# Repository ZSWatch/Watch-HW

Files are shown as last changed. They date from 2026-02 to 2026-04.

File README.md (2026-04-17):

> [!IMPORTANT]  
> This is a prototype right now, not fully tested. Do not order.
> Please use https://github.com/ZSWatch/Watch-DevKit-HW until this PCB is finalized.
> Not recommended to order the older legacy_zswatch. 

# ZSWatch-Watch



## 📑 Table of Contents

- [ZSWatch-Watch](#zswatch-watch)
  - [📑 Table of Contents](#-table-of-contents)
  - [📖 About](#-about)
  - [📂 Directory Breakdown](#-directory-breakdown)
  - [Purchasing](#purchasing)
  - [Ressources](#ressources)
  - [👨‍💻 Maintainer](#-maintainer)

## 📖 About

The **ZSWatch-Watch** project provides the hardware design and production files for a smartwatch development board tailored to the ZSWatch ecosystem.
It is built with **KiCad** and integrates a full **CI/CD pipeline** using **KiBot**, ensuring reproducible outputs for documentation, manufacturing, and releases.

Key features:

- 🛠️ Open-source hardware design
- 📦 Automated generation of Gerber, BoM, and documentation via KiBot
- 🔄 Workflow stages (DRAFT → PRELIMINARY → CHECKED → RELEASED) for structured releases
- 📝 Clear documentation and changelog to track progress
- 🌍 Designed with collaboration and transparency in mind

Please check the [wiki](https://github.com/ZSWatch/ZSWatch/wiki) for more information about the project.

You can also view this project on [CADLAB.io](...). 

## 📂 Directory Breakdown

- **`.github`**: GitHub related files
- **`.gitignore`**: Ignored files list
- **`devkit`**: KiCad project for the devkit
- **`production`**: Manufacturing outputs (Gerbers, documentation, etc.)
- **`CHANGELOG.md`**: Version history
- **`LICENSE`**: Project license (GPL-3.0)
- **`README.md`**: Project overview

## Purchasing

TBD

## Ressources

- [KiBot Template](https://github.com/nguyen-v/KDT_Hierarchical_KiBot)

## 👨‍💻 Maintainer

- [Daniel Kampert](mailto:danielkameprt@kampis-elektroecke.de)

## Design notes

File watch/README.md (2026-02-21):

<p align="center" width="100%">
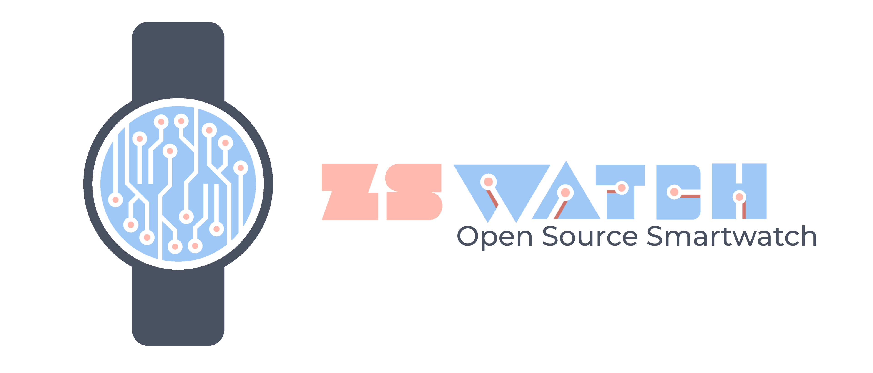
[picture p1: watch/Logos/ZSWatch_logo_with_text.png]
  
</p>

<h1 align="center">Template</h1>

<p align="center" width="100%">
  <a href="${GIT_URL}/actions/workflows/watch.yaml">
    CI Badge
  </a>
</p>

***

<p align="center">
  3D Top Angled
&nbsp; &nbsp; &nbsp; &nbsp;
  3D Bottom Angled
</p>

***

## SPECIFICATIONS

| Parameter | Value |
| --- | --- |
| Dimensions | 32.0 × 24.0 mm |

***

## DIRECTORY STRUCTURE

    .
    ├─ Computations       # Misc calculations
    ├─ HTML               # HTML files for generated webpage
    ├─ Images             # Pictures and renders
    │
    ├─ kibot_resources    # External resources for KiBot
    │  ├─ colors          # Color theme for KiCad
    │  ├─ fonts           # Fonts used in the project
    │  ├─ scripts         # External scripts used with KiBot
    │  └─ templates       # Templates for KiBot generated reports
    │
    ├─ kibot_yaml         # KiBot YAML config files
    ├─ KiRI               # KiRI (PCB diff viewer) files
    │
    ├─ lib                # KiCad footprint and symbol libraries
    │  ├─ 3d_models       # Component 3D models
    │  ├─ lib_fp          # Footprint libraries
    │  └─ lib_sym         # Symbol libraries
    │
    ├─ logos              # Logos
    │
    ├─ Manufacturing      # Assembly and fabrication documents
    │  ├─ Assembly        # Assembly documents (BoM, pos, notes)
    │  │
    │  └─ Fabrication     # Fabrication documents (ZIP, notes)
    │     ├─ Drill Tables # CSV drill tables
    │     └─ Gerbers      # Gerbers
    │
    ├─ Report             # Reports for ERC/DRC
    ├─ Schematic          # PDF of schematic
    ├─ templates          # Title block templates
    ├─ Testing
    │  └─ Testpoints      # Testpoints tables
    │
    └─ Variants           # Outputs for assembly variants

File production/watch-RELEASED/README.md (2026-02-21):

<p align="center" width="100%">
  
</p>

<h1 align="center">Watch-DevKit-HW</h1>

<p align="center" width="100%">
  <a href="https://github.com/ZSWatch/Watch-DevKit-HW/actions/workflows/watch.yaml">
    
  </a>
</p>

***

<p align="center">
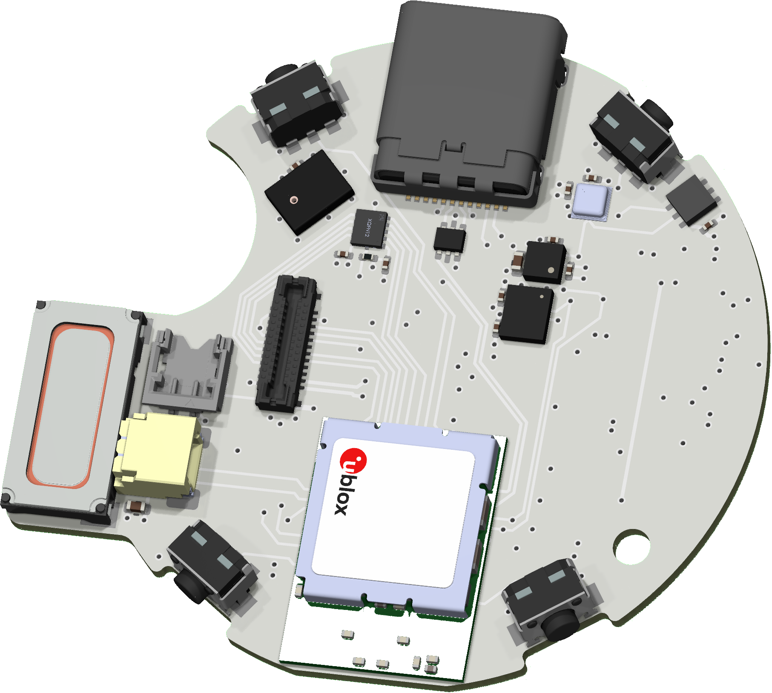
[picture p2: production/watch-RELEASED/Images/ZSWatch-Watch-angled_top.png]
3D Top Angled
  
&nbsp; &nbsp; &nbsp; &nbsp;
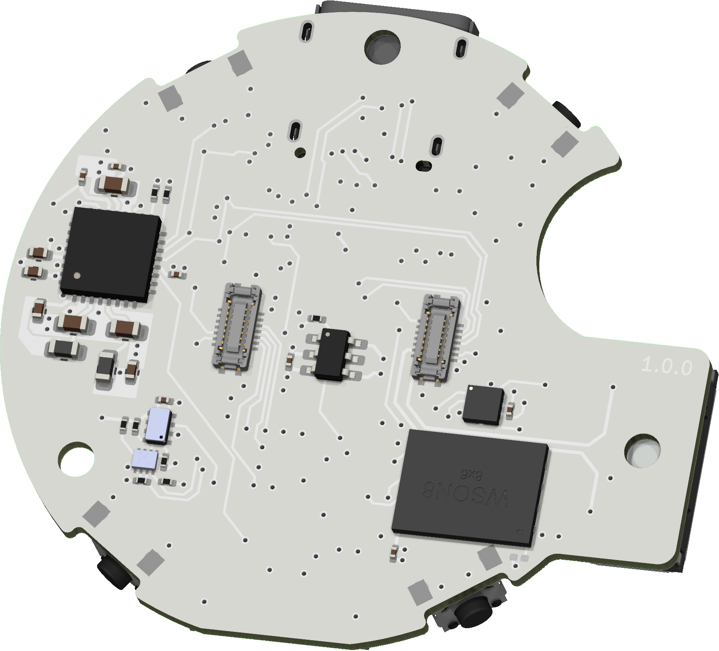
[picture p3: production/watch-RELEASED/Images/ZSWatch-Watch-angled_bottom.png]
3D Bottom Angled
  
</p>

***

## SPECIFICATIONS

| Parameter | Value |
| --- | --- |
| Dimensions | 40.97 × 37.5 mm |

***

## DIRECTORY STRUCTURE

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

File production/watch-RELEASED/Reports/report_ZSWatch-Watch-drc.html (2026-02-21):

Logo

| DRC report for ZSWatch-Watch
| PCB: ZSWatch-Watch Revision: 1.0.0 Date: 2026-02-21T12:36:49+0000 KiCad Version: 9.0.7 | Errors: 0 Warnings: 65 Total: 65

Violations

Type | Description | Details
lib_footprint_issues | The current configuration does not include the footprint library 'Package_QFN'. | @(202.45 mm, 131.19 mm): Footprint IC604
lib_footprint_mismatch | Footprint 'C_0201_0603Metric' does not match copy in library 'Capacitor_SMD'. | @(203.7 mm, 133.1 mm): Footprint C603
lib_footprint_issues | The current configuration does not include the footprint library 'Wuerth'. | @(216.7 mm, 124.7 mm): Footprint S501
lib_footprint_mismatch | Footprint 'C_0201_0603Metric' does not match copy in library 'Capacitor_SMD'. | @(210.507497 mm, 136.062499 mm): Footprint C504
lib_footprint_mismatch | Footprint 'C_0402_1005Metric' does not match copy in library 'Capacitor_SMD'. | @(192.325 mm, 148.675 mm): Footprint C403
lib_footprint_issues | The current configuration does not include the footprint library 'Wuerth'. | @(197.409401 mm, 152.152416 mm): Footprint S504
lib_footprint_mismatch | Footprint 'C_0201_0603Metric' does not match copy in library 'Capacitor_SMD'. | @(201.23 mm, 132.79 mm): Footprint C604
lib_footprint_mismatch | Footprint 'C_0201_0603Metric' does not match copy in library 'Capacitor_SMD'. | @(213.976079 mm, 132.307498 mm): Footprint C507
lib_footprint_mismatch | Footprint 'R_0201_0603Metric' does not match copy in library 'Resistor_SMD'. | @(202.63 mm, 132.79 mm): Footprint R613
lib_footprint_mismatch | Footprint 'C_0201_0603Metric' does not match copy in library 'Capacitor_SMD'. | @(210.462496 mm, 134.237499 mm): Footprint C503
lib_footprint_mismatch | Footprint 'C_0201_0603Metric' does not match copy in library 'Capacitor_SMD'. | @(214.282501 mm, 126.8575 mm): Footprint C509
lib_footprint_mismatch | Footprint 'C_0201_0603Metric' does not match copy in library 'Capacitor_SMD'. | @(213.100001 mm, 127.675001 mm): Footprint C508
lib_footprint_issues | The current configuration does not include the footprint library 'EastRising'. | @(199.0 mm, 138.5 mm): Footprint X608
lib_footprint_issues | The current configuration does not include the footprint library 'Package_LGA_Kampi'. | @(212.1 mm, 135.2 mm): Footprint IC502
lib_footprint_issues | The current configuration does not include the footprint library 'Wuerth'. | @(216.6 mm, 152.1 mm): Footprint S502
lib_footprint_mismatch | Footprint 'C_0201_0603Metric' does not match copy in library 'Capacitor_SMD'. | @(212.78 mm, 130.667001 mm): Footprint C505
lib_footprint_mismatch | Footprint 'C_0201_0603Metric' does not match copy in library 'Capacitor_SMD'. | @(197.675287 mm, 128.024713 mm): Footprint C502
lib_footprint_issues | The current configuration does not include the footprint library 'Package_LGA_Kampi'. | @(214.500001 mm, 128.2375 mm): Footprint IC504
lib_footprint_mismatch | Footprint 'JST_SH_SM02B-SRSS-TB_1x02-1MP_P1.00mm_Horizontal' does not match copy in library 'Connector_JST'. | @(192.9 mm, 146.0 mm): Footprint X402
lib_footprint_mismatch | Footprint 'SOT-666' does not match copy in library 'Package_TO_SOT_SMD'. | @(207.0375 mm, 131.35 mm): Footprint IC602
lib_footprint_issues | The current configuration does not include the footprint library 'Molex'. | @(193.95 mm, 140.8 mm): Footprint X509
lib_footprint_issues | The current configuration does not include the footprint library 'Wuerth'. | @(197.433306 mm, 124.890678 mm): Footprint S503
lib_footprint_issues | The current configuration does not include the footprint library 'Knowles'. | @(198.820801 mm, 129.566207 mm): Footprint MK501
lib_footprint_issues | The current configuration does not include the footprint library 'Package_LGA_Kampi'. | @(212.604999 mm, 132.15 mm): Footprint IC503
lib_footprint_issues | The current configuration does not include the footprint library 'Broadcom'. | @(220.146966 mm, 127.633273 mm): Footprint IC501
lib_footprint_issues | The current configuration does not include the footprint library 'uBlox'. | @(207.0 mm, 150.1 mm): Footprint M601
lib_footprint_mismatch | Footprint 'C_0402_1005Metric' does not match copy in library 'Capacitor_SMD'. | @(211.054999 mm, 132.1875 mm): Footprint C506
lib_footprint_mismatch | Footprint 'USB_C_Receptacle_Amphenol_12401610E4-2A' does not match copy in library 'Connector_USB'. | @(207.0 mm, 123.9 mm): Footprint X603
lib_footprint_mismatch | Footprint 'C_0201_0603Metric' does not match copy in library 'Capacitor_SMD'. | @(221.234143 mm, 128.879548 mm): Footprint C501
lib_footprint_issues | The current configuration does not include the footprint library 'Same Sky'. | @(188.0 mm, 143.8 mm): Footprint LS801
lib_footprint_issues | The current configuration does not include the footprint library 'Package_QFN'. | @(197.4 mm, 142.15 mm): Footprint IC505
lib_footprint_mismatch | Footprint 'C_0201_0603Metric' does not match copy in library 'Capacitor_SMD'. | @(216.3304 mm, 136.3 mm): Footprint C402
lib_footprint_mismatch | Footprint 'R_0201_0603Metric' does not match copy in library 'Resistor_SMD'. | @(207.9 mm, 138.0 mm): Footprint R601
lib_footprint_mismatch | Footprint 'R_0201_0603Metric' does not match copy in library 'Resistor_SMD'. | @(216.209999 mm, 148.7 mm): Footprint R501
lib_footprint_mismatch | Footprint 'R_0201_0603Metric' does not match copy in library 'Resistor_SMD'. | @(217.8 mm, 145.5 mm): Footprint R506
lib_footprint_mismatch | Footprint 'R_0201_0603Metric' does not match copy in library 'Resistor_SMD'. | @(214.755 mm, 148.6 mm): Footprint R502
lib_footprint_mismatch | Footprint 'C_0201_0603Metric' does not match copy in library 'Capacitor_SMD'. | @(209.0 mm, 140.7 mm): Footprint C601
lib_footprint_mismatch | Footprint 'C_0201_0603Metric' does not match copy in library 'Capacitor_SMD'. | @(215.755 mm, 143.8 mm): Footprint C511
lib_footprint_mismatch | Footprint 'C_0201_0603Metric' does not match copy in library 'Capacitor_SMD'. | @(220.9 mm, 130.3 mm): Footprint C401
lib_footprint_mismatch | Footprint 'C_0201_0603Metric' does not match copy in library 'Capacitor_SMD'. | @(201.05 mm, 151.355 mm): Footprint C602
lib_footprint_mismatch | Footprint 'C_0603_1608Metric' does not match copy in library 'Capacitor_SMD'. | @(220.761401 mm, 131.497172 mm): Footprint C410
lib_footprint_mismatch | Footprint 'C_0201_0603Metric' does not match copy in library 'Capacitor_SMD'. | @(195.9 mm, 142.2 mm): Footprint C510
lib_footprint_mismatch | Footprint 'C_0603_1608Metric' does not match copy in library 'Capacitor_SMD'. | @(218.622001 mm, 139.936383 mm): Footprint C409
lib_footprint_issues | The current configuration does not include the footprint library 'Amphenol'. | @(200.8 mm, 138.5 mm): Footprint X702
lib_footprint_mismatch | Footprint 'C_0402_1005Metric' does not match copy in library 'Capacitor_SMD'. | @(224.5 mm, 137.1 mm): Footprint C512
lib_footprint_mismatch | Footprint 'C_0402_1005Metric' does not match copy in library 'Capacitor_SMD'. | @(217.892001 mm, 142.308382 mm): Footprint C406
lib_footprint_mismatch | Footprint 'R_0201_0603Metric' does not match copy in library 'Resistor_SMD'. | @(193.87 mm, 150.8 mm): Footprint R612
lib_footprint_mismatch | Footprint 'C_0402_1005Metric' does not match copy in library 'Capacitor_SMD'. | @(224.400001 mm, 135.950002 mm): Footprint C404
lib_footprint_mismatch | Footprint 'L_0603_1608Metric' does not match copy in library 'Inductor_SMD'. | @(221.911 mm, 141.5 mm): Footprint L402
lib_footprint_issues | The current configuration does not include the footprint library 'Package_SON_Kampi'. | @(216.18 mm, 147.5 mm): Footprint IC506
lib_footprint_mismatch | Footprint 'R_0201_0603Metric' does not match copy in library 'Resistor_SMD'. | @(215.109999 mm, 147.420001 mm): Footprint R505
lib_footprint_mismatch | Footprint 'R_0201_0603Metric' does not match copy in library 'Resistor_SMD'. | @(217.75 mm, 131.608381 mm): Footprint R408
lib_footprint_mismatch | Footprint 'C_0402_1005Metric' does not match copy in library 'Capacitor_SMD'. | @(223.8304 mm, 139.278193 mm): Footprint C408
lib_footprint_mismatch | Footprint 'QFN-32-1EP_5x5mm_P0.5mm_EP3.6x3.6mm' does not match copy in library 'Package_DFN_QFN'. | @(220.2 mm, 135.7 mm): Footprint IC401
lib_footprint_mismatch | Footprint 'TSOT-23-6' does not match copy in library 'Package_TO_SOT_SMD'. | @(206.5375 mm, 140.15 mm): Footprint IC601
lib_footprint_mismatch | Footprint 'WSON-8-1EP_8x6mm_P1.27mm_EP3.4x4.3mm' does not match copy in library 'Package_SON'. | @(197.3 mm, 147.135 mm): Footprint IC603
lib_footprint_mismatch | Footprint 'C_0603_1608Metric' does not match copy in library 'Capacitor_SMD'. | @(221.657 mm, 139.936383 mm): Footprint C407
lib_footprint_mismatch | Footprint 'L_0603_1608Metric' does not match copy in library 'Inductor_SMD'. | @(219.370999 mm, 142.349382 mm): Footprint L401
lib_footprint_issues | The current configuration does not include the footprint library 'Micro Crystal'. | @(215.755 mm, 145.430001 mm): Footprint IC507
lib_footprint_mismatch | Footprint 'R_0201_0603Metric' does not match copy in library 'Resistor_SMD'. | @(217.1 mm, 145.5 mm): Footprint R504
lib_footprint_mismatch | Footprint 'R_0201_0603Metric' does not match copy in library 'Resistor_SMD'. | @(218.449999 mm, 131.608381 mm): Footprint R407
lib_footprint_mismatch | Footprint 'C_0201_0603Metric' does not match copy in library 'Capacitor_SMD'. | @(222.730398 mm, 131.087793 mm): Footprint C405
lib_footprint_issues | The current configuration does not include the footprint library 'Amphenol'. | @(212.3 mm, 139.1 mm): Footprint X701

Schematic parity

Type | Description | Details
footprint_symbol_mismatch | Connector_JST:JST_SH_SM02B-SRSS-TB_1x02-1MP_P1.00mm_Horizontal doesn't match footprint given by symbol (JST_SH_SM02B-SRSS-TB_1x02-1MP_P1.00mm_Horizontal). | @(192.9 mm, 146.0 mm): Footprint X402
extra_footprint | Extra footprint | @(220.2 mm, 147.8 mm): Footprint REF**

Generated by KiBot (https://github.com/INTI-CMNB/KiBot/) v1.8.5

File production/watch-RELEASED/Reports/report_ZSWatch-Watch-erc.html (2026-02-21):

Logo

| ERC report for ZSWatch-Watch
| Schematic: ZSWatch-Watch Revision: 1.0.0 Date: 2026-02-21T12:36:46+0000 KiCad Version: 9.0.7 | Errors: 0 Warnings: 49 Total: 49

Sheet / (ZSWatch-Watch.kicad_sch)

Type | Description | Details
unresolved_variable | Unresolved text variable | @(0.2032 mm, 0.3175 mm): Text Box
unresolved_variable | Unresolved text variable | @(0.2286 mm, 0.3556 mm): Text Box
unresolved_variable | Unresolved text variable | @(0.8636 mm, 0.3175 mm): Text Box
unresolved_variable | Unresolved text variable | @(0.889 mm, 0.3556 mm): Text Box
unresolved_variable | Unresolved text variable | @(1.524 mm, 0.3175 mm): Text Box
unresolved_variable | Unresolved text variable | @(1.5494 mm, 0.3556 mm): Text Box
unresolved_variable | Unresolved text variable | @(2.1844 mm, 0.3175 mm): Text Box
unresolved_variable | Unresolved text variable | @(2.2098 mm, 0.3556 mm): Text Box
footprint_link_issues | The current configuration does not include the footprint library 'Broadcom'. | @(0.3048 mm, 0.5461 mm): Symbol IC501 [APDS-9306-065]
footprint_link_issues | The current configuration does not include the footprint library 'Wuerth'. | @(0.254 mm, 1.0033 mm): Symbol S501 [SW_Push]
footprint_link_issues | The current configuration does not include the footprint library 'Wuerth'. | @(0.254 mm, 1.1176 mm): Symbol S502 [SW_Push]
footprint_link_issues | The current configuration does not include the footprint library 'Wuerth'. | @(0.254 mm, 1.2319 mm): Symbol S503 [SW_Push]
footprint_link_issues | The current configuration does not include the footprint library 'Wuerth'. | @(0.254 mm, 1.3462 mm): Symbol S504 [SW_Push]
footprint_link_issues | The current configuration does not include the footprint library 'Knowles'. | @(0.8636 mm, 1.27 mm): Symbol MK501 [SPK0641HT4H-1]
lib_symbol_issues | The current configuration does not include the symbol library 'Knowles' | @(0.8636 mm, 1.27 mm): Symbol MK501 [SPK0641HT4H-1]
footprint_link_issues | The current configuration does not include the footprint library 'Package_LGA_Kampi'. | @(1.9558 mm, 0.7747 mm): Symbol IC502 [BMI270]
lib_symbol_issues | The current configuration does not include the symbol library 'Bosch_Kampi' | @(1.9558 mm, 0.7747 mm): Symbol IC502 [BMI270]
footprint_link_issues | The current configuration does not include the footprint library 'Package_LGA_Kampi'. | @(2.7051 mm, 0.762 mm): Symbol IC504 [BMP581]
lib_symbol_issues | The current configuration does not include the symbol library 'Bosch_Kampi' | @(2.7051 mm, 0.762 mm): Symbol IC504 [BMP581]
footprint_link_issues | The current configuration does not include the footprint library 'Package_LGA_Kampi'. | @(2.6162 mm, 1.5875 mm): Symbol IC503 [LIS2MDLTR]
lib_symbol_issues | The current configuration does not include the symbol library 'ST' | @(2.6162 mm, 1.5875 mm): Symbol IC503 [LIS2MDLTR]
footprint_link_issues | The current configuration does not include the footprint library 'Package_QFN'. | @(3.3782 mm, 0.6096 mm): Symbol IC505 [DRV2603RUNT]
lib_symbol_issues | The current configuration does not include the symbol library 'Texas Instruments' | @(3.3782 mm, 0.6096 mm): Symbol IC505 [DRV2603RUNT]
footprint_link_issues | The current configuration does not include the footprint library 'Molex'. | @(3.6068 mm, 0.6223 mm): Symbol X509 [Conn_01x02]
footprint_link_issues | The current configuration does not include the footprint library 'Package_SON_Kampi'. | @(3.4544 mm, 1.3081 mm): Symbol IC506 [PCA9306JK]
lib_symbol_issues | The current configuration does not include the symbol library 'NXP' | @(3.4544 mm, 1.3081 mm): Symbol IC506 [PCA9306JK]
footprint_link_issues | The current configuration does not include the footprint library 'Micro Crystal'. | @(3.81 mm, 1.3843 mm): Symbol IC507 [RV-8263-C8]
lib_symbol_issues | The current configuration does not include the symbol library 'Micro Crystal' | @(3.81 mm, 1.3843 mm): Symbol IC507 [RV-8263-C8]
footprint_link_issues | The current configuration does not include the footprint library 'uBlox'. | @(0.8636 mm, 1.1049 mm): Symbol M601 [NORA-B106]
lib_symbol_issues | The current configuration does not include the symbol library 'uBlox' | @(0.8636 mm, 1.1049 mm): Symbol M601 [NORA-B106]
footprint_link_issues | The current configuration does not include the footprint library 'uBlox'. | @(1.397 mm, 1.0287 mm): Symbol M601 [NORA-B106]
lib_symbol_issues | The current configuration does not include the symbol library 'uBlox' | @(1.397 mm, 1.0287 mm): Symbol M601 [NORA-B106]
lib_symbol_issues | The current configuration does not include the symbol library 'ON Semiconductor' | @(0.5334 mm, 1.9685 mm): Symbol IC601 [FAN5622]
footprint_link_issues | The current configuration does not include the footprint library 'uBlox'. | @(2.159 mm, 1.2319 mm): Symbol M601 [NORA-B106]
lib_symbol_issues | The current configuration does not include the symbol library 'uBlox' | @(2.159 mm, 1.2319 mm): Symbol M601 [NORA-B106]
lib_symbol_issues | The current configuration does not include the symbol library 'Infineon' | @(2.3749 mm, 1.9939 mm): Symbol IC603 [S25FS512SAGNFI010]
footprint_link_issues | The current configuration does not include the footprint library 'Package_QFN'. | @(3.5179 mm, 0.762 mm): Symbol IC604 [NTS0104GU12 (XQFN12)]
lib_symbol_issues | The current configuration does not include the symbol library 'NXP' | @(3.5179 mm, 0.762 mm): Symbol IC604 [NTS0104GU12 (XQFN12)]
footprint_link_issues | The current configuration does not include the footprint library 'EastRising'. | @(3.5433 mm, 1.4605 mm): Symbol X608 [GC9A01A_CST816S]
lib_symbol_issues | The current configuration does not include the symbol library 'Display' | @(3.5433 mm, 1.4605 mm): Symbol X608 [GC9A01A_CST816S]
lib_symbol_issues | The current configuration does not include the symbol library 'Nordic' | @(1.7018 mm, 1.0414 mm): Symbol IC401 [nPM1300-QEXX]
footprint_link_issues | The current configuration does not include the footprint library ''. | @(1.9812 mm, 0.3683 mm): Symbol X402 [Conn_01x02]
footprint_link_issues | The current configuration does not include the footprint library 'Amphenol'. | @(0.9017 mm, 0.8636 mm): Symbol X701 [Conn_02x07_Top_Bottom]
footprint_link_issues | The current configuration does not include the footprint library 'Amphenol'. | @(1.5875 mm, 0.8636 mm): Symbol X702 [Conn_02x07_Top_Bottom]
footprint_link_issues | The current configuration does not include the footprint library 'Same Sky'. | @(1.8034 mm, 0.8255 mm): Symbol LS801 [Speaker]

Sheet /Project Architecture/Power Management/ (Power.kicad_sch)

Type | Description | Details
pin_to_pin | Pins of type Bidirectional and Power output are connected | @(2.032 mm, 1.2319 mm): Symbol IC401 Pin 29 [LSOUT1/VOUTLDO1, Bidirectional, Line] @(2.3114 mm, 1.2192 mm): Symbol #FLG0502 Pin 1 [Power output, Line]
pin_to_pin | Pins of type Bidirectional and Power output are connected | @(2.032 mm, 1.3081 mm): Symbol IC401 Pin 31 [LSOUT2/VOUTLDO2, Bidirectional, Line] @(2.159 mm, 1.2954 mm): Symbol #FLG0501 Pin 1 [Power output, Line]

Sheet /Project Architecture/Peripherals/ (Peripherals.kicad_sch)

Type | Description | Details
pin_to_pin | Pins of type Bidirectional and Power output are connected | @(1.8288 mm, 0.7239 mm): Symbol IC502 Pin 1 [SDO, Bidirectional, Line] @(0.889 mm, 1.8796 mm): Symbol #FLG0402 Pin 1 [Power output, Line]
pin_to_pin | Pins of type Bidirectional and Power output are connected | @(2.5781 mm, 0.7366 mm): Symbol IC504 Pin 5 [SDO, Bidirectional, Line] @(2.032 mm, 0.8255 mm): Symbol IC401 Pin 1 [VOUT1, Power output, Line]

Generated by KiBot (https://github.com/INTI-CMNB/KiBot/) v1.8.5

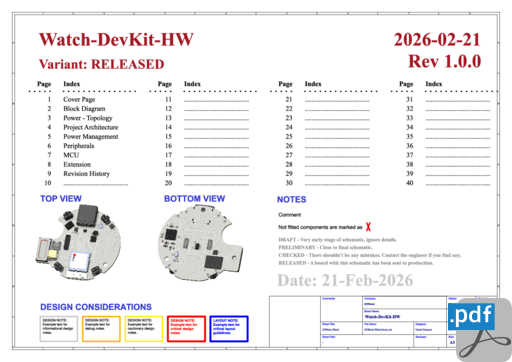
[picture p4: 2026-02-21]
production/watch-RELEASED/HTML/images/cat_pdf_schematic_ZSWatch-Watch-schematic.png

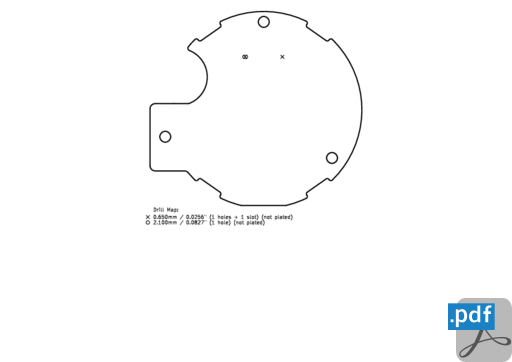
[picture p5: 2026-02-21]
production/watch-RELEASED/HTML/images/cat_pdf_drill_map_ZSWatch-Watch-NPTH_drill_map.png

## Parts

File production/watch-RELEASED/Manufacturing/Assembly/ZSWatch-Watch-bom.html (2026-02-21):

 | Bill of Materials
 | Schematic: ZSWatch-Watch Variant: RELEASED Revision: 1.0.0 Date: 2025-07-13 KiCad Version: 9.0.7+1 | Component Groups: 37 Component Count: 62 (per PCB) Fitted Components: 62 (per PCB) Number of PCBs: 1 Total Components: 62 (for 1 PCBs)
Row | Quantity Per PCB | References | Value | Datasheet | Footprint | Description | manf | manf# | mouser#
1 | 13 | C402 C501 C502 C503 C504 C507 C508 C509 C510 C511 C602 C603 C604 | 100n | https://datasheets.kyocera-avx.com/cx5r-KGM.pdf | C_0201_0603Metric | Unpolarized capacitor, small symbol | KYOCERA AVX | 02016D104MAT4A | 581-02016D104MAT4A
2 | 1 | C505 | 220n | https://datasheets.kyocera-avx.com/cx5r-KGM.pdf | C_0201_0603Metric | Unpolarized capacitor, small symbol | KYOCERA AVX | 0201ZD224KAT2A | 581-0201ZD224KAT2A
3 | 3 | C401 C405 C601 | 1u | https://datasheets.kyocera-avx.com/cx5r-KGM.pdf | C_0201_0603Metric | Unpolarized capacitor, small symbol | KYOCERA AVX | KGM03BR50J105KH | 581-KGM03BR50J105KH
4 | 1 | C403 | 2u2 | https://datasheets.kyocera-avx.com/cx5r.pdf | C_0402_1005Metric | Unpolarized capacitor, small symbol | KYOCERA AVX | 0402ZD225MAT2A | 581-0402ZD225MAT2A
5 | 5 | C404 C406 C408 C506 C512 | 10u | https://search.murata.co.jp/Ceramy/image/img/A01X/G101/ENG/GRJ155R60J106ME11-02A.pdf | C_0402_1005Metric | Unpolarized capacitor, small symbol | Murata Electronics | GRJ155R60J106ME11D | 81-GRJ155R60J106ME11D
6 | 3 | C407 C409 C410 | 10u | https://datasheets.kyocera-avx.com/cx5r-KGM.pdf | C_0603_1608Metric | Unpolarized capacitor, small symbol | KYOCERA AVX | KGM15CR50J106MT | 581-KGM15CR50J106MT
7 | 1 | IC501 | APDS-9306-065 | https://docs.broadcom.com/docs/AV02-4755EN | Broadcom_DFN-6_2x2mm_P0.65mm | Ambient Light Sensor, I2C interface, 1.7-3.6V, DFN-6 | Broadcom / Avago | APDS-9306-065 | 630-APDS-9306-065
8 | 1 | IC502 | BMI270 | https://www.bosch-sensortec.com/media/boschsensortec/downloads/datasheets/bst-bmi270-ds000.pdf | Bosch_LGA-14_3x2.5mm_P0.5mm_LayoutBorder3x4y |  | Bosch | BMI270 | 262-BMI270
9 | 1 | IC504 | BMP581 | https://www.bosch-sensortec.com/media/boschsensortec/downloads/datasheets/bst-bmp581-ds004.pdf | Bosch_LGA-10_2x2mm_P0.5mm_ClockwisePinNumbering |  | Bosch | BMP581 | 262-BMP581
10 | 1 | IC505 | DRV2603RUNT | https://www.ti.com/lit/ds/symlink/drv2603.pdf?HQS=dis-mous-null-mousermode-dsf-pf-null-wwe&ts=1692200896697 | WQFN-10_2x2mm_P0.5mm |  | Texas Instruments | DRV2603RUNT | 595-DRV2603RUNT
11 | 1 | IC601 | FAN5622SX | https://www.onsemi.com/download/data-sheet/pdf/fan5626-d.pdf | TSOT-23-6 |  | onsemi / Fairchild | FAN5622SX | 512-FAN5622SX
12 | 1 | IC503 | LIS2MDLTR | http://www.st.com/content/ccc/resource/technical/document/datasheet/group3/29/13/d1/e0/9a/4d/4f/30/DM00395193/files/DM00395193.pdf/jcr:content/translations/en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 | LGA-12_2x2mm_P0.5mm |  | STMicroelectronics | LIS2MDLTR | 511-LIS2MDLTR
13 | 1 | IC603 | MX25U51245GZ4I00 | https://www.mouser.de/datasheet/2/819/MX25U51245G_2c_1_8V_2c_512Mb_2c_v1_4-3371129.pdf | WSON-8-1EP_8x6mm_P1.27mm_EP3.4x4.3mm |  | Macronix | MX25U51245GZ4I00 | 95-25U51245GZ4I00T
14 | 1 | IC604 | NTS0104GU12 | https://www.nxp.com/docs/en/data-sheet/NTS0104.pdf | XQFN-12-1.7x2mm_P0.4mm |  | NXP Semiconductors | NTS0104GU12,115 | 771-NTS0104GU12115
15 | 1 | IC506 | PCA9306JK | https://www.nxp.com/docs/en/data-sheet/PCA9306.pdf | XSON-8_0.65x0.17mm_P0.35mm | Dual bidirectional I2C Bus and SMBus voltage level translator | NXP Semiconductors | PCA9306JKZ | 771-PCA9306JKZ
16 | 1 | IC507 | RV-8263-C8 | https://www.microcrystal.com/fileadmin/Media/Products/RTC/Datasheet/RV-8263-C8.pdf | RV-8263-C8 |  | Micro Crystal | RV-8263-C8 32.768kHz-20PPM-TA-QA | 428-204291-MC01
17 | 1 | IC602 | USBLC6-2P6 | https://www.st.com/resource/en/datasheet/usblc6-2.pdf | SOT-666 | Very low capacitance ESD protection diode, 2 data-line, SOT-666 | STMicroelectronics | USBLC6-2P6 | 511-USBLC6-2P6
18 | 1 | IC401 | nPM1300-QEXX | https://infocenter.nordicsemi.com/index.jsp?topic=%2Fstruct_pmic%2Fstruct%2Fnpm1300.html | QFN-32-1EP_5x5mm_P0.5mm_EP3.6x3.6mm |  | Nordic Semiconductor | nPM1300-QEAA-R7 | 949-NPM1300-QEAA-R7
19 | 2 | L401 L402 | 2u2 | https://www.mouser.de/datasheet/3/76/1/JELF243B-9121.pdf | L_0603_1608Metric | Inductor | Murata Electronics | LQM18PZ2R2MDHD | 81-LQM18PZ2R2MDHD
20 | 1 | LS801 | Speaker | https://www.mouser.de/datasheet/3/6118/1/cmr_12062s_67.pdf | CMR-12062S-67 | Speaker | Same Sky | CMR-12062S-67 | 490-CMR-12062S-67
21 | 1 | M601 | NORA-B106 | https://www.u-blox.com/docs/UBX-20027119 | NORA-B106 |  | u-blox | NORA-B106-00B | 377-NORA-B106-00B
22 | 1 | MK501 | SPK0641HT4H-1 | https://www.knowles.com/docs/default-source/default-document-library/sph0645lm4h-1-datasheet.pdf | SPK0641HT4H-1 | Digital MEMS Microphone | Knowles | SPK0641HT4H-1 | 721-SPK0641HT4H-1
23 | 2 | R501 R502 | 1k8 | https://www.mouser.com/catalog/specsheets/YAGEO_PYu_RC_Group_51_RoHS_L_12.pdf | R_0201_0603Metric | Resistor, small symbol | YAGEO | RC0201JR-071K8L | 603-RC0201JR-071K8L
24 | 2 | R504 R505 | 3k3 | https://www.mouser.com/catalog/specsheets/YAGEO_PYu_RC_Group_51_RoHS_L_12.pdf | R_0201_0603Metric | Resistor, small symbol | YAGEO | RC0201JR-073K3L | 603-RC0201JR-073K3L
25 | 1 | R601 | 12k | https://www.mouser.com/catalog/specsheets/YAGEO_PYu_RC_Group_51_RoHS_L_12.pdf | R_0201_0603Metric | Resistor, small symbol | YAGEO | RC0201JR-0712KL | 603-RC0201JR-0712KL
26 | 1 | R407 | 47k | https://www.mouser.com/catalog/specsheets/YAGEO_PYu_RC_Group_51_RoHS_L_12.pdf | R_0201_0603Metric | Resistor, small symbol | YAGEO | RC0201JR-0747KL | 603-RC0201JR-0747KL
27 | 2 | R408 R613 | 100k | https://www.mouser.com/catalog/specsheets/YAGEO_PYu_RC_Group_51_RoHS_L_12.pdf | R_0201_0603Metric | Resistor, small symbol | YAGEO | RC0201JR-07100KL | 603-RC0201JR-07100KL
28 | 1 | R506 | 200k | https://www.mouser.com/catalog/specsheets/YAGEO_PYu_RC_Group_51_RoHS_L_12.pdf | R_0201_0603Metric | Resistor, small symbol | YAGEO | RC0201JR-07200KL | 603-RC0201JR-07200KL
29 | 1 | S501 | SW1 | https://www.we-online.com/components/products/datasheet/436333033816.pdf | 43633303381_NoMountingPads | Push button switch, generic, two pins | Wurth Elektronik | 436333033816 | 710-436333033816
30 | 1 | S502 | SW2 | https://www.we-online.com/components/products/datasheet/436333033816.pdf | 43633303381_NoMountingPads | Push button switch, generic, two pins | Wurth Elektronik | 436333033816 | 710-436333033816
31 | 1 | S503 | SW3 | https://www.we-online.com/components/products/datasheet/436333033816.pdf | 43633303381_NoMountingPads | Push button switch, generic, two pins | Wurth Elektronik | 436333033816 | 710-436333033816
32 | 1 | S504 | SW4 | https://www.we-online.com/components/products/datasheet/436333033816.pdf | 43633303381_NoMountingPads | Push button switch, generic, two pins | Wurth Elektronik | 436333033816 | 710-436333033816
33 | 1 | X402 | Battery | https://www.mouser.com/catalog/specsheets/JST_SM02B-SRSS-TB_LF_SN_eSR_SZ.pdf | JST_SH_SM02B-SRSS-TB_1x02-1MP_P1.00mm_Horizontal | Generic connector, single row, 01x02, script generated (kicad-library-utils/schlib/autogen/connector/) | JST Commercial | SM02B-SRSS-TB | 306-SM02BSRSSTBLFSN
34 | 1 | X603 | Device | https://www.usb.org/sites/default/files/documents/usb_type-c.zip | USB_C_Receptacle_Amphenol_12401610E4-2A | USB Full-Featured Type-C Receptacle connector | Amphenol Commercial Products | 12401610E4#2A | 523-12401610E4#2A
35 | 1 | X608 | Display | https://www.buydisplay.com/download/manual/ER-TFT1.28-2_Datasheet.pdf | ER-CON0.4-24P |  | EastRising | OK-24F024-04
36 | 2 | X701 X702 | MB1 | https://cdn.amphenol-cs.com/media/wysiwyg/files/drawing/101r014fb110.pdf | 101R014FB110 | Generic connector, double row, 02x07, top/bottom pin numbering scheme (row 1: 1...pins_per_row, row2: pins_per_row+1 ... num_pins), script generated (kicad-library-utils/schlib/autogen/connector/) | Amphenol Aorora | 101R014FB110 | 649-101R014FB110
37 | 1 | X509 | Motor | https://www.molex.com/en-us/products/part-detail-pdf/781710002?display=pdf | 78171-0002 | Generic connector, single row, 01x02, script generated (kicad-library-utils/schlib/autogen/connector/) | Molex | 78171-0002 | 538-78171-0002
Color reference for columns:
KiCad Fields (default)
Generated Fields
User Fields
Empty Fields

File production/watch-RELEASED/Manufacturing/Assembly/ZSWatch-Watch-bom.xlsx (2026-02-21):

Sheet: BoM
Bill of Materials
Schematic: | ZSWatch-Watch | Component Groups: | 37
Variant: | RELEASED | Component Count: | 62 (58 SMD/ 4 THT)
Revision: |  | Fitted Components: | 62 (58 SMD/ 4 THT)
Date: | 2025-07-13 | Number of PCBs: | 1
KiCad Version: | 9.0.7+1 | Total Components: | 62
Row | Quantity Per PCB | References | Value | Datasheet | Footprint | Description | manf | manf#
1 | 13 | C402 C501 C502 C503 C504 C507 C508 C509 C510 C511 C602 C603 C604 | 100n | https://datasheets.kyocera-avx.com/cx5r-KGM.pdf | C_0201_0603Metric | Unpolarized capacitor, small symbol | KYOCERA AVX | 02016D104MAT4A
2 | 1 | C505 | 220n | https://datasheets.kyocera-avx.com/cx5r-KGM.pdf | C_0201_0603Metric | Unpolarized capacitor, small symbol | KYOCERA AVX | 0201ZD224KAT2A
3 | 3 | C401 C405 C601 | 1u | https://datasheets.kyocera-avx.com/cx5r-KGM.pdf | C_0201_0603Metric | Unpolarized capacitor, small symbol | KYOCERA AVX | KGM03BR50J105KH
4 | 1 | C403 | 2u2 | https://datasheets.kyocera-avx.com/cx5r.pdf | C_0402_1005Metric | Unpolarized capacitor, small symbol | KYOCERA AVX | 0402ZD225MAT2A
5 | 5 | C404 C406 C408 C506 C512 | 10u | https://search.murata.co.jp/Ceramy/image/img/A01X/G101/ENG/GRJ155R60J106ME11-02A.pdf | C_0402_1005Metric | Unpolarized capacitor, small symbol | Murata Electronics | GRJ155R60J106ME11D
6 | 3 | C407 C409 C410 | 10u | https://datasheets.kyocera-avx.com/cx5r-KGM.pdf | C_0603_1608Metric | Unpolarized capacitor, small symbol | KYOCERA AVX | KGM15CR50J106MT
7 | 1 | IC501 | APDS-9306-065 | https://docs.broadcom.com/docs/AV02-4755EN | Broadcom_DFN-6_2x2mm_P0.65mm | Ambient Light Sensor, I2C interface, 1.7-3.6V, DFN-6 | Broadcom / Avago | APDS-9306-065
8 | 1 | IC502 | BMI270 | https://www.bosch-sensortec.com/media/boschsensortec/downloads/datasheets/bst-bmi270-ds000.pdf | Bosch_LGA-14_3x2.5mm_P0.5mm_LayoutBorder3x4y |  | Bosch | BMI270
9 | 1 | IC504 | BMP581 | https://www.bosch-sensortec.com/media/boschsensortec/downloads/datasheets/bst-bmp581-ds004.pdf | Bosch_LGA-10_2x2mm_P0.5mm_ClockwisePinNumbering |  | Bosch | BMP581
10 | 1 | IC505 | DRV2603RUNT | https://www.ti.com/lit/ds/symlink/drv2603.pdf?HQS=dis-mous-null-mousermode-dsf-pf-null-wwe&ts=1692200896697 | WQFN-10_2x2mm_P0.5mm |  | Texas Instruments | DRV2603RUNT
11 | 1 | IC601 | FAN5622SX | https://www.onsemi.com/download/data-sheet/pdf/fan5626-d.pdf | TSOT-23-6 |  | onsemi / Fairchild | FAN5622SX
12 | 1 | IC503 | LIS2MDLTR | http://www.st.com/content/ccc/resource/technical/document/datasheet/group3/29/13/d1/e0/9a/4d/4f/30/DM00395193/files/DM00395193.pdf/jcr:content/translations/en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 | LGA-12_2x2mm_P0.5mm |  | STMicroelectronics | LIS2MDLTR
13 | 1 | IC603 | MX25U51245GZ4I00 | https://www.mouser.de/datasheet/2/819/MX25U51245G_2c_1_8V_2c_512Mb_2c_v1_4-3371129.pdf | WSON-8-1EP_8x6mm_P1.27mm_EP3.4x4.3mm |  | Macronix | MX25U51245GZ4I00
14 | 1 | IC604 | NTS0104GU12 | https://www.nxp.com/docs/en/data-sheet/NTS0104.pdf | XQFN-12-1.7x2mm_P0.4mm |  | NXP Semiconductors | NTS0104GU12,115
15 | 1 | IC506 | PCA9306JK | https://www.nxp.com/docs/en/data-sheet/PCA9306.pdf | XSON-8_0.65x0.17mm_P0.35mm | Dual bidirectional I2C Bus and SMBus voltage level translator | NXP Semiconductors | PCA9306JKZ
16 | 1 | IC507 | RV-8263-C8 | https://www.microcrystal.com/fileadmin/Media/Products/RTC/Datasheet/RV-8263-C8.pdf | RV-8263-C8 |  | Micro Crystal | RV-8263-C8 32.768kHz-20PPM-TA-QA
17 | 1 | IC602 | USBLC6-2P6 | https://www.st.com/resource/en/datasheet/usblc6-2.pdf | SOT-666 | Very low capacitance ESD protection diode, 2 data-line, SOT-666 | STMicroelectronics | USBLC6-2P6
18 | 1 | IC401 | nPM1300-QEXX | https://infocenter.nordicsemi.com/index.jsp?topic=%2Fstruct_pmic%2Fstruct%2Fnpm1300.html | QFN-32-1EP_5x5mm_P0.5mm_EP3.6x3.6mm |  | Nordic Semiconductor | nPM1300-QEAA-R7
19 | 2 | L401 L402 | 2u2 | https://www.mouser.de/datasheet/3/76/1/JELF243B-9121.pdf | L_0603_1608Metric | Inductor | Murata Electronics | LQM18PZ2R2MDHD
20 | 1 | LS801 | Speaker | https://www.mouser.de/datasheet/3/6118/1/cmr_12062s_67.pdf | CMR-12062S-67 | Speaker | Same Sky | CMR-12062S-67
21 | 1 | M601 | NORA-B106 | https://www.u-blox.com/docs/UBX-20027119 | NORA-B106 |  | u-blox | NORA-B106-00B
22 | 1 | MK501 | SPK0641HT4H-1 | https://www.knowles.com/docs/default-source/default-document-library/sph0645lm4h-1-datasheet.pdf | SPK0641HT4H-1 | Digital MEMS Microphone | Knowles | SPK0641HT4H-1
23 | 2 | R501 R502 | 1k8 | https://www.mouser.com/catalog/specsheets/YAGEO_PYu_RC_Group_51_RoHS_L_12.pdf | R_0201_0603Metric | Resistor, small symbol | YAGEO | RC0201JR-071K8L
24 | 2 | R504 R505 | 3k3 | https://www.mouser.com/catalog/specsheets/YAGEO_PYu_RC_Group_51_RoHS_L_12.pdf | R_0201_0603Metric | Resistor, small symbol | YAGEO | RC0201JR-073K3L
25 | 1 | R601 | 12k | https://www.mouser.com/catalog/specsheets/YAGEO_PYu_RC_Group_51_RoHS_L_12.pdf | R_0201_0603Metric | Resistor, small symbol | YAGEO | RC0201JR-0712KL
26 | 1 | R407 | 47k | https://www.mouser.com/catalog/specsheets/YAGEO_PYu_RC_Group_51_RoHS_L_12.pdf | R_0201_0603Metric | Resistor, small symbol | YAGEO | RC0201JR-0747KL
27 | 2 | R408 R613 | 100k | https://www.mouser.com/catalog/specsheets/YAGEO_PYu_RC_Group_51_RoHS_L_12.pdf | R_0201_0603Metric | Resistor, small symbol | YAGEO | RC0201JR-07100KL
28 | 1 | R506 | 200k | https://www.mouser.com/catalog/specsheets/YAGEO_PYu_RC_Group_51_RoHS_L_12.pdf | R_0201_0603Metric | Resistor, small symbol | YAGEO | RC0201JR-07200KL
29 | 1 | S501 | SW1 | https://www.we-online.com/components/products/datasheet/436333033816.pdf | 43633303381_NoMountingPads | Push button switch, generic, two pins | Wurth Elektronik | 436333033816
30 | 1 | S502 | SW2 | https://www.we-online.com/components/products/datasheet/436333033816.pdf | 43633303381_NoMountingPads | Push button switch, generic, two pins | Wurth Elektronik | 436333033816
31 | 1 | S503 | SW3 | https://www.we-online.com/components/products/datasheet/436333033816.pdf | 43633303381_NoMountingPads | Push button switch, generic, two pins | Wurth Elektronik | 436333033816
32 | 1 | S504 | SW4 | https://www.we-online.com/components/products/datasheet/436333033816.pdf | 43633303381_NoMountingPads | Push button switch, generic, two pins | Wurth Elektronik | 436333033816
33 | 1 | X402 | Battery | https://www.mouser.com/catalog/specsheets/JST_SM02B-SRSS-TB_LF_SN_eSR_SZ.pdf | JST_SH_SM02B-SRSS-TB_1x02-1MP_P1.00mm_Horizontal | Generic connector, single row, 01x02, script generated (kicad-library-utils/schlib/autogen/connector/) | JST Commercial | SM02B-SRSS-TB
34 | 1 | X603 | Device | https://www.usb.org/sites/default/files/documents/usb_type-c.zip | USB_C_Receptacle_Amphenol_12401610E4-2A | USB Full-Featured Type-C Receptacle connector | Amphenol Commercial Products | 12401610E4#2A
35 | 1 | X608 | Display | https://www.buydisplay.com/download/manual/ER-TFT1.28-2_Datasheet.pdf | ER-CON0.4-24P |  | EastRising | OK-24F024-04
36 | 2 | X701 X702 | MB1 | https://cdn.amphenol-cs.com/media/wysiwyg/files/drawing/101r014fb110.pdf | 101R014FB110 | Generic connector, double row, 02x07, top/bottom pin numbering scheme (row 1: 1...pins_per_row, row2: pins_per_row+1 ... num_pins), script generated (kicad-library-utils/schlib/autogen/connector/) | Amphenol Aorora | 101R014FB110
37 | 1 | X509 | Motor | https://www.molex.com/en-us/products/part-detail-pdf/781710002?display=pdf | 78171-0002 | Generic connector, single row, 01x02, script generated (kicad-library-utils/schlib/autogen/connector/) | Molex | 78171-0002

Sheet: Costs
Bill of Materials
Schematic: | ZSWatch-Watch |  |  |  |  | Board Qty: | 1
Variant: | RELEASED |  |  |  |  | Unit Cost: | $0.00
Revision: |  |  |  |  |  | Total Cost: | $0.00 |  |  |  |  | $0.00 | 0 of 37 parts found
Date: | 2025-07-13
KiCad Version: | 9.0.7+1
Global Part Info |  |  |  |  |  |  |  | Mouser
References | Value | Footprint | Manf | Manf# | Build Quantity | Unit$ | Ext$ | Avail | Purch | Unit$ | MOQ | Ext$ | Cat#
C402 C501 C502 C503 C504 C507 C508 C509 C510 C511 C602 C603 C604 | 100n | C_0201_0603Metric | KYOCERA AVX | 02016D104MAT4A (https://datasheets.kyocera-avx.com/cx5r-KGM.pdf) | 13
C505 | 220n | C_0201_0603Metric | KYOCERA AVX | 0201ZD224KAT2A (https://datasheets.kyocera-avx.com/cx5r-KGM.pdf) | 1
C401 C405 C601 | 1u | C_0201_0603Metric | KYOCERA AVX | KGM03BR50J105KH (https://datasheets.kyocera-avx.com/cx5r-KGM.pdf) | 3
C403 | 2u2 | C_0402_1005Metric | KYOCERA AVX | 0402ZD225MAT2A (https://datasheets.kyocera-avx.com/cx5r.pdf) | 1
C404 C406 C408 C506 C512 | 10u | C_0402_1005Metric | Murata Electronics | GRJ155R60J106ME11D (https://search.murata.co.jp/Ceramy/image/img/A01X/G101/ENG/GRJ155R60J106ME11-02A.pdf) | 5
C407 C409 C410 | 10u | C_0603_1608Metric | KYOCERA AVX | KGM15CR50J106MT (https://datasheets.kyocera-avx.com/cx5r-KGM.pdf) | 3
IC501 | APDS-9306-065 | Broadcom_DFN-6_2x2mm_P0.65mm | Broadcom / Avago | APDS-9306-065 (https://docs.broadcom.com/docs/AV02-4755EN) | 1
IC502 | BMI270 | Bosch_LGA-14_3x2.5mm_P0.5mm_LayoutBorder3x4y | Bosch | BMI270 (https://www.bosch-sensortec.com/media/boschsensortec/downloads/datasheets/bst-bmi270-ds000.pdf) | 1
IC504 | BMP581 | Bosch_LGA-10_2x2mm_P0.5mm_ClockwisePinNumbering | Bosch | BMP581 (https://www.bosch-sensortec.com/media/boschsensortec/downloads/datasheets/bst-bmp581-ds004.pdf) | 1
IC505 | DRV2603RUNT | WQFN-10_2x2mm_P0.5mm | Texas Instruments | DRV2603RUNT (https://www.ti.com/lit/ds/symlink/drv2603.pdf?HQS=dis-mous-null-mousermode-dsf-pf-null-wwe&ts=1692200896697) | 1
IC601 | FAN5622SX | TSOT-23-6 | onsemi / Fairchild | FAN5622SX (https://www.onsemi.com/download/data-sheet/pdf/fan5626-d.pdf) | 1
IC503 | LIS2MDLTR | LGA-12_2x2mm_P0.5mm | STMicroelectronics | LIS2MDLTR (http://www.st.com/content/ccc/resource/technical/document/datasheet/group3/29/13/d1/e0/9a/4d/4f/30/DM00395193/files/DM00395193.pdf/jcr:content/translations/en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) | 1
IC603 | MX25U51245GZ4I00 | WSON-8-1EP_8x6mm_P1.27mm_EP3.4x4.3mm | Macronix | MX25U51245GZ4I00 (https://www.mouser.de/datasheet/2/819/MX25U51245G_2c_1_8V_2c_512Mb_2c_v1_4-3371129.pdf) | 1
IC604 | NTS0104GU12 | XQFN-12-1.7x2mm_P0.4mm | NXP Semiconductors | NTS0104GU12,115 (https://www.nxp.com/docs/en/data-sheet/NTS0104.pdf) | 1
IC506 | PCA9306JK | XSON-8_0.65x0.17mm_P0.35mm | NXP Semiconductors | PCA9306JKZ (https://www.nxp.com/docs/en/data-sheet/PCA9306.pdf) | 1
IC507 | RV-8263-C8 | RV-8263-C8 | Micro Crystal | RV-8263-C8 32.768kHz-20PPM-TA-QA (https://www.microcrystal.com/fileadmin/Media/Products/RTC/Datasheet/RV-8263-C8.pdf) | 1
IC602 | USBLC6-2P6 | SOT-666 | STMicroelectronics | USBLC6-2P6 (https://www.st.com/resource/en/datasheet/usblc6-2.pdf) | 1
IC401 | nPM1300-QEXX | QFN-32-1EP_5x5mm_P0.5mm_EP3.6x3.6mm | Nordic Semiconductor | nPM1300-QEAA-R7 (https://infocenter.nordicsemi.com/index.jsp?topic=%2Fstruct_pmic%2Fstruct%2Fnpm1300.html) | 1
L401 L402 | 2u2 | L_0603_1608Metric | Murata Electronics | LQM18PZ2R2MDHD (https://www.mouser.de/datasheet/3/76/1/JELF243B-9121.pdf) | 2
LS801 | Speaker | CMR-12062S-67 | Same Sky | CMR-12062S-67 (https://www.mouser.de/datasheet/3/6118/1/cmr_12062s_67.pdf) | 1
M601 | NORA-B106 | NORA-B106 | u-blox | NORA-B106-00B (https://www.u-blox.com/docs/UBX-20027119) | 1
MK501 | SPK0641HT4H-1 | SPK0641HT4H-1 | Knowles | SPK0641HT4H-1 (https://www.knowles.com/docs/default-source/default-document-library/sph0645lm4h-1-datasheet.pdf) | 1
R501 R502 | 1k8 | R_0201_0603Metric | YAGEO | RC0201JR-071K8L (https://www.mouser.com/catalog/specsheets/YAGEO_PYu_RC_Group_51_RoHS_L_12.pdf) | 2
R504 R505 | 3k3 | R_0201_0603Metric | YAGEO | RC0201JR-073K3L (https://www.mouser.com/catalog/specsheets/YAGEO_PYu_RC_Group_51_RoHS_L_12.pdf) | 2
R601 | 12k | R_0201_0603Metric | YAGEO | RC0201JR-0712KL (https://www.mouser.com/catalog/specsheets/YAGEO_PYu_RC_Group_51_RoHS_L_12.pdf) | 1
R407 | 47k | R_0201_0603Metric | YAGEO | RC0201JR-0747KL (https://www.mouser.com/catalog/specsheets/YAGEO_PYu_RC_Group_51_RoHS_L_12.pdf) | 1
R408 R613 | 100k | R_0201_0603Metric | YAGEO | RC0201JR-07100KL (https://www.mouser.com/catalog/specsheets/YAGEO_PYu_RC_Group_51_RoHS_L_12.pdf) | 2
R506 | 200k | R_0201_0603Metric | YAGEO | RC0201JR-07200KL (https://www.mouser.com/catalog/specsheets/YAGEO_PYu_RC_Group_51_RoHS_L_12.pdf) | 1
S501 | SW1 | 43633303381_NoMountingPads | Wurth Elektronik | 436333033816 (https://www.we-online.com/components/products/datasheet/436333033816.pdf) | 1
S502 | SW2 | 43633303381_NoMountingPads | Wurth Elektronik | 436333033816 (https://www.we-online.com/components/products/datasheet/436333033816.pdf) | 1
S503 | SW3 | 43633303381_NoMountingPads | Wurth Elektronik | 436333033816 (https://www.we-online.com/components/products/datasheet/436333033816.pdf) | 1
S504 | SW4 | 43633303381_NoMountingPads | Wurth Elektronik | 436333033816 (https://www.we-online.com/components/products/datasheet/436333033816.pdf) | 1
X402 | Battery | JST_SH_SM02B-SRSS-TB_1x02-1MP_P1.00mm_Horizontal | JST Commercial | SM02B-SRSS-TB (https://www.mouser.com/catalog/specsheets/JST_SM02B-SRSS-TB_LF_SN_eSR_SZ.pdf) | 1
X603 | Device | USB_C_Receptacle_Amphenol_12401610E4-2A | Amphenol Commercial Products | 12401610E4#2A (https://www.usb.org/sites/default/files/documents/usb_type-c.zip) | 1
X608 | Display | ER-CON0.4-24P | EastRising | OK-24F024-04 (https://www.buydisplay.com/download/manual/ER-TFT1.28-2_Datasheet.pdf) | 1
X701 X702 | MB1 | 101R014FB110 | Amphenol Aorora | 101R014FB110 (https://cdn.amphenol-cs.com/media/wysiwyg/files/drawing/101r014fb110.pdf) | 2
X509 | Motor | 78171-0002 | Molex | 78171-0002 (https://www.molex.com/en-us/products/part-detail-pdf/781710002?display=pdf) | 1
 |  |  |  |  |  | Total Purchase: | $0.00 | Buy here (https://mouser.com/bom/) |  |  |  | $0.00
Created: | 2026-02-21 12:41:46 |  |  |  |  | Purchase description:
KiCost® v1.1.20 + KiBot v1.8.5

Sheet: Colors
Columns colors
KiCad Fields (default)
Generated Fields
User Fields
Empty Fields
Costs sheet colors
Best price
No manufacturer or distributor code
Not available
Purchase quantity is more than what is available
Minimum order quantity not respected
Total available part quantity is less than needed
Total purchased part quantity is less than needed
This part is obsolete
This part is listed but is not normally stocked

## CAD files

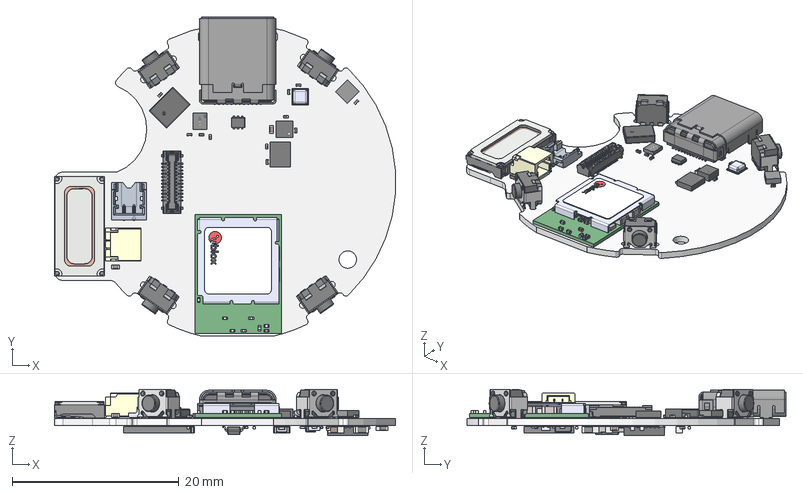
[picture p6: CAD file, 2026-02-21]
production/watch-CHECKED/3D/ZSWatch-Watch.step
40.9 x 38.3 x 5.54 mm
XQFN-12
C_0201_0603Metric x 17
frame x 4
stem x 4
cover_0 x 4
pins x 4
pin2 x 8
C_0402_1005Metric x 6
R_0201_0603Metric x 9
ER-CON0.4-24P
LGA-14_3x2.5mm_P0.5mm_LayoutBorder3x4y
BMP581
SM02B-SRSS-TB-LF-SN
SOT-666
SPK0641HT4H
LGA-12_2x2mm_P0.5mm
Pins
label_8x8
logo_x_4mm
logo_o_4mm
logo_l_4mm
logo_b_4mm
logo_u_4mm
UBXH04-0000650_NORA-TYPE-1_SHIELD_rev3
Extruded x 185
aQFN-116_(7x7) x 2
Free-Models
USB_C_Receptacle_Amphenol_12401610E4-2A
CMR-12062S-67
WQFN-10
C_0603_1608Metric x 3
BW94_SERIES x 2
L_0603_1608Metric x 2
SOT1089 LF
SOT1089 Mold body
QFN-32-5x5_0.5_EP3.6x3.6mm
TSOT-23-6
WSON-8-8x6
RV-8263-C8
kibot_yj7t4_vw_PCB

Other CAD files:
production/watch-PRELIMINARY/3D/ZSWatch-Watch.step
production/watch-RELEASED/3D/ZSWatch-Watch.step

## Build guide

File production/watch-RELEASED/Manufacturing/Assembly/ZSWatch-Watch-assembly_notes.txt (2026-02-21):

ASSEMBLY NOTES (UNLESS OTHERWISE SPECIFIED)

1)	DO NOT POPULATE PARTS ARE MARKED WITH A RED CROSS.

2)	DO NOT POPULATE PARTS ARE NOT PRESENT IN THE BOM.

3)	IF CONFLICTING INFORMATION IS FOUND BETWEEN THE ASSEMBLY
	FILE AND BOM, BOM SHOULD BE USED AS THE MAIN SOURCE.

4)	CONFORMAL COATING IS NOT REQUIRED.

5)	DOT IDENTIFIES PIN #1 LOCATION AND DEVICE ORIENTATION
	WHEN VIEWED FROM THE TOP.

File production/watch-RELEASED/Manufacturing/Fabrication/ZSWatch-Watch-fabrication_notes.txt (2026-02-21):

FABRICATION NOTES (UNLESS OTHERWISE SPECIFIED)

1)	FABRICATE PER IPC-6012A CLASS 2.

2)	OUTLINE DEFINED IN SEPARATE GERBER FILE WITH
	"Edge_Cuts.GBR" SUFFIX.

	DIMENSIONS OF CIRCUMSIZED RECTANGLE SHOWN ON THIS
	DRAWING FOR REFERENCE ONLY.

3)	SEE SEPARATE DRILL FILES WITH ".DRL" SUFFIX 
	FOR HOLE LOCATIONS.

	SELECTED HOLE LOCATIONS SHOWN ON THIS DRAWING 
	FOR REFERENCE ONLY.

4)	SURFACE FINISH: HAL LEAD-FREE

5)	SOLDERMASK ON BOTH SIDES OF THE BOARD SHALL 
	BE LPI, COLOR WHITE.

6)	SILK SCREEN LEGEND TO BE APPLIED PER LAYER 
	STACKUP USING BLACK NON-CONDUCTIVE EPOXY INK.

7)	ALL VIAS ARE TENTED ON BOTH SIDES UNLESS 
	SOLDERMASK OPENED IN GERBER.

8)	VENDOR SHOULD FOLLOW ROHS COMPLIANT PROCESS 
	AND Pb FREE FOR MANUFACTURING

9)	PCB MATERIAL REQUIREMENTS:

	A.	FLAMMABILITY RATING MUST MEET OR EXCEED 
		UL94V-0 REQUIREMENTS.
	B.	Tg 150 C OR EQUIVALENT.

10)	DESIGN GEOMETRY MINIMUM FEATURE SIZES:

	BOARD SIZE				40.972 × 37.500 mm
	BOARD THICKNESS		0.982 mm
	TRACE WIDTH			0.150 mm
	TRACE TO TRACE		0.125 mm
	MIN. HOLE (PTH)			0.250 mm
	MIN. HOLE (NPTH)		0.650 mm
	ANNULAR RING			0.100 mm
	COPPER TO HOLE		0.125 mm
	COPPER TO EDGE		0.125 mm
	HOLE TO HOLE			0.250 mm

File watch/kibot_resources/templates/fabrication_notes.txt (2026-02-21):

FABRICATION NOTES (UNLESS OTHERWISE SPECIFIED)

1)	FABRICATE PER IPC-6012A CLASS 2.

2)	OUTLINE DEFINED IN SEPARATE GERBER FILE WITH
	"Edge_Cuts.GBR" SUFFIX.

	DIMENSIONS OF CIRCUMSIZED RECTANGLE SHOWN ON THIS
	DRAWING FOR REFERENCE ONLY.

3)	SEE SEPARATE DRILL FILES WITH ".DRL" SUFFIX 
	FOR HOLE LOCATIONS.

	SELECTED HOLE LOCATIONS SHOWN ON THIS DRAWING 
	FOR REFERENCE ONLY.

4)	SURFACE FINISH: ${pcb_finish_cap}

5)	SOLDERMASK ON BOTH SIDES OF THE BOARD SHALL 
	BE LPI, COLOR ${solder_mask_color_text_cap}.

6)	SILK SCREEN LEGEND TO BE APPLIED PER LAYER 
	STACKUP USING ${silk_screen_color_text_cap} NON-CONDUCTIVE EPOXY INK.

7)	ALL VIAS ARE TENTED ON BOTH SIDES UNLESS 
	SOLDERMASK OPENED IN GERBER.

8)	VENDOR SHOULD FOLLOW ROHS COMPLIANT PROCESS 
	AND Pb FREE FOR MANUFACTURING

9)	PCB MATERIAL REQUIREMENTS:

	A.	FLAMMABILITY RATING MUST MEET OR EXCEED 
		UL94V-0 REQUIREMENTS.
	B.	Tg 150 C OR EQUIVALENT.

10)	DESIGN GEOMETRY MINIMUM FEATURE SIZES:

	BOARD SIZE				${bb_w_mm} × ${bb_h_mm} mm
	BOARD THICKNESS		${thickness_mm} mm
	TRACE WIDTH			${track_mm} mm
	TRACE TO TRACE		${clearance_mm} mm
	MIN. HOLE (PTH)			${drill_pth_real_mm} mm
	MIN. HOLE (NPTH)		${drill_npth_real_mm} mm
	ANNULAR RING			${oar_mm} mm
	COPPER TO HOLE		${c2h_mm} mm
	COPPER TO EDGE		${c2e_mm} mm
	HOLE TO HOLE			${h2h_mm} mm
#?stackup and impedance_controlled

#?stackup and impedance_controlled
11)	REFER TO IMPEDANCE TABLE FOR IMPEDANCE CONTROL REQUIREMENTS.
#?stackup and impedance_controlled

#?stackup and impedance_controlled
12)	CONFIRM SPACE WIDTHS AND SPACINGS.

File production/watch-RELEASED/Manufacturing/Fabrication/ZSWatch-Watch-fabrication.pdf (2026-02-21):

# Top Fabrication (Scale 1:1)

# Watch-DevKit-HW Fabrication Document

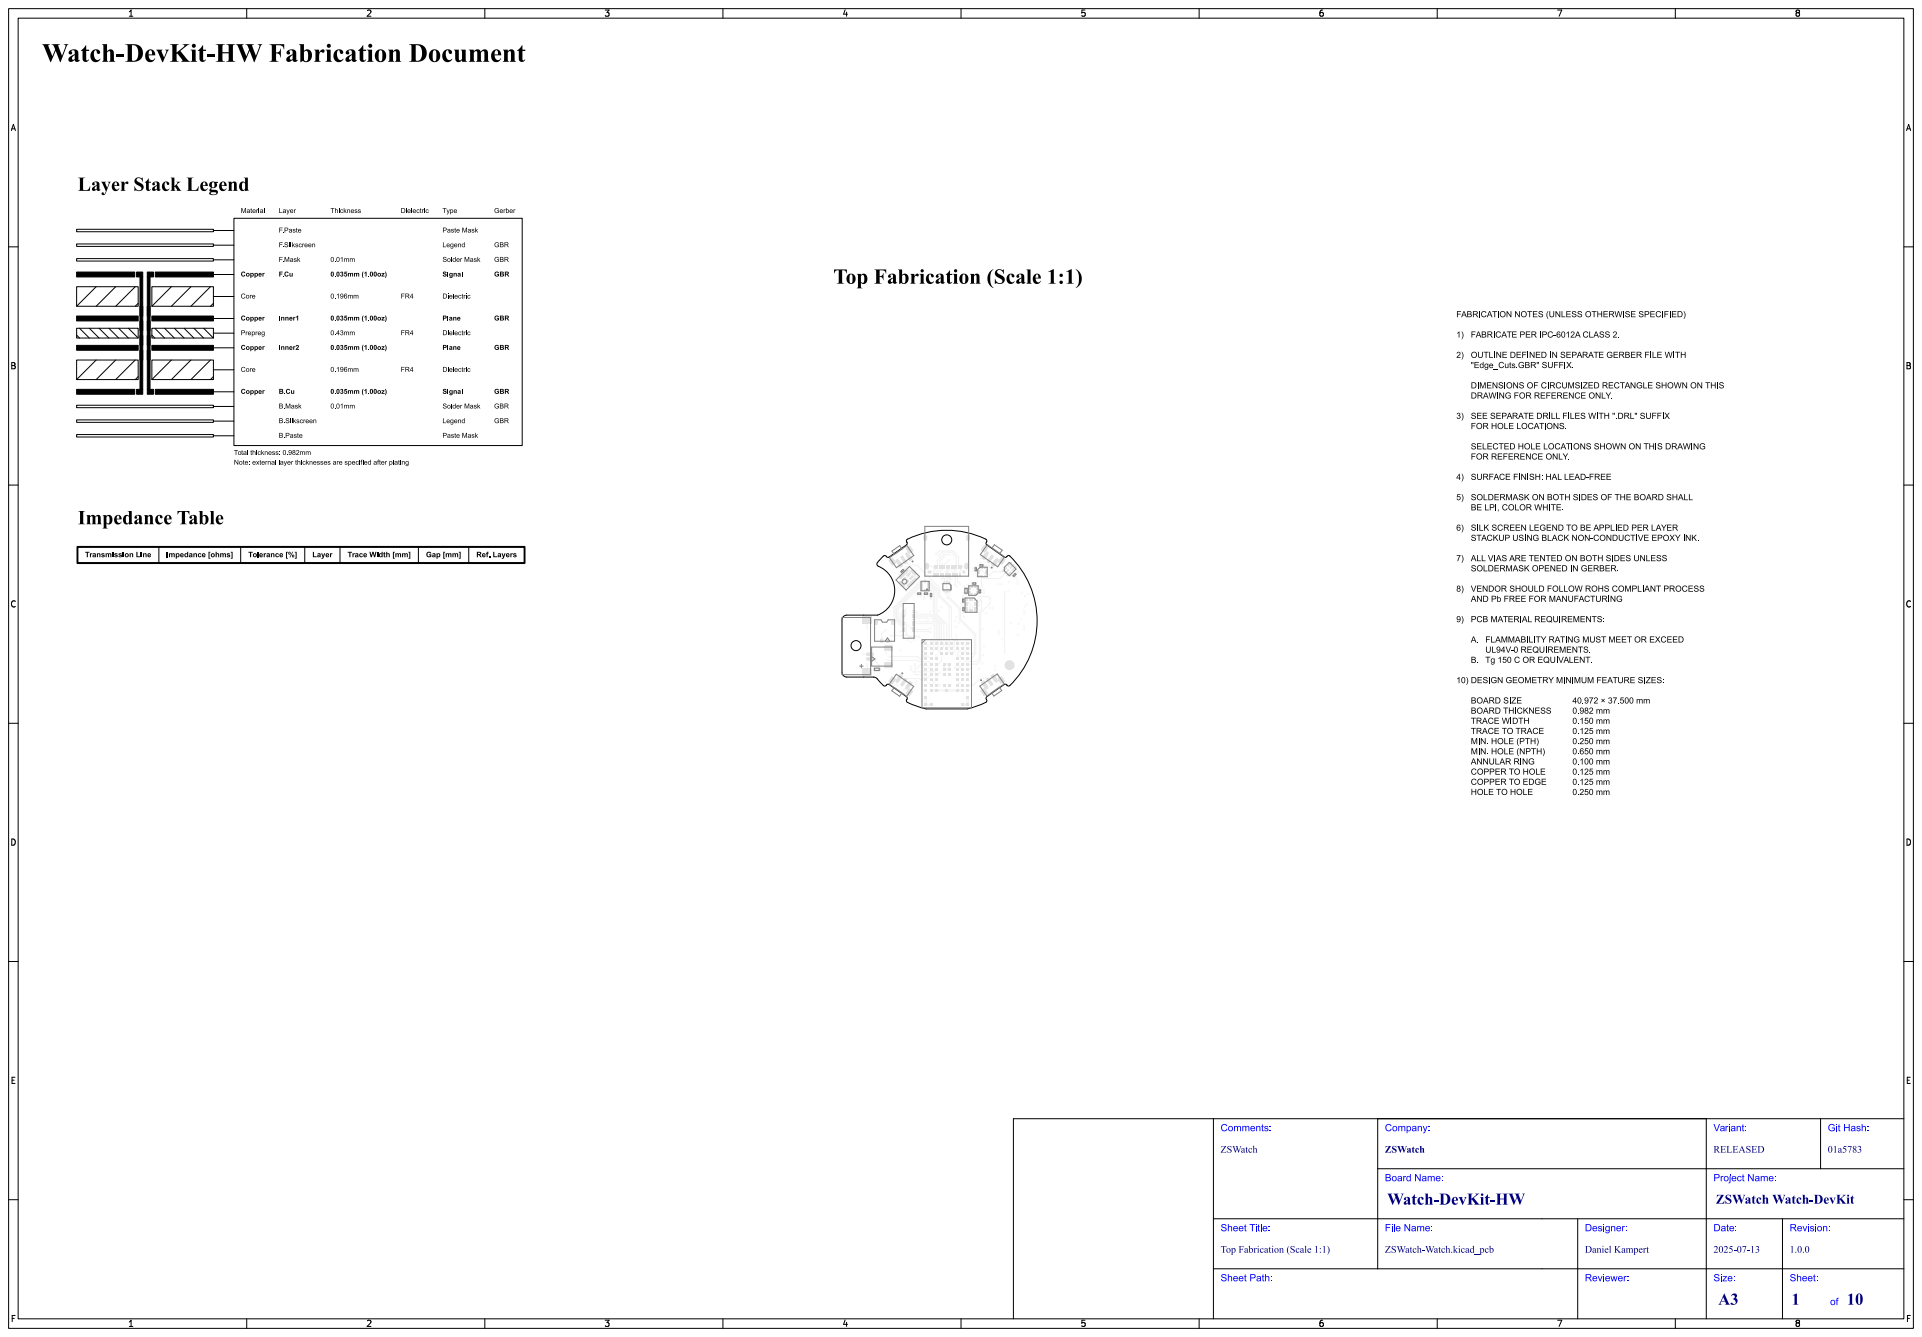
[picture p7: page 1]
Git Hash:; ZSWatch; Comments:; Sheet Path:; Sheet Title:; File Name:; Watch-DevKit-HW; ZSWatch Watch-DevKit; Company:; RELEASED; Variant:; Board Name:; ZSWatch-Watch.kicad_pcb; Daniel Kampert; Designer:; Reviewer:; Project Name:; Date:; Revision:; Size:; Sheet:

Top Fabrication (Scale 1:1)

# Bottom Fabrication (Scale 1:1)

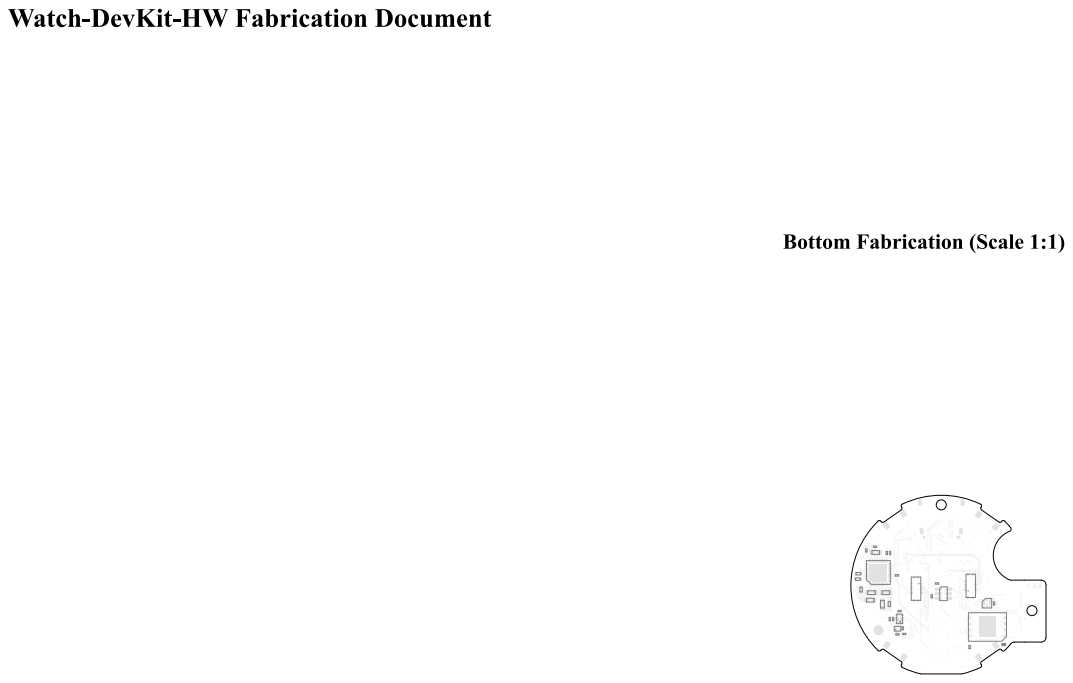
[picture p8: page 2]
Git; Hash:; ZSWatch; Comments:; Sheet Title:; File Name:; Watch-DevKit-HW; ZSWatch Watch-DevKit; Company:; RELEASED; Variant:; Board Name:; ZSWatch-Watch.kicad_pcb; Daniel Kampert; Designer:; Project Name:; Date:; Revision:

Bottom Fabrication (Scale 1:1)

# Drill Drawing L1 - L4 (Scale 1:1)

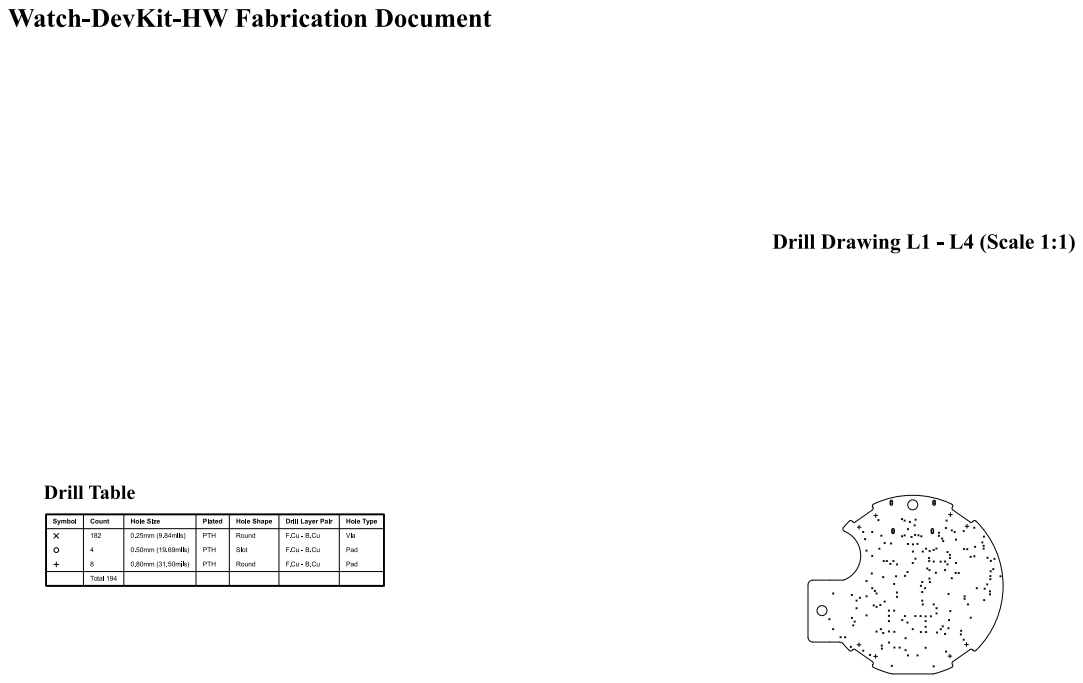
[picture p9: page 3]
Git; Hash:; ZSWatch; Comments:; Drill Drawing (L1 - L4); Sheet Title:; File Name:; Watch-DevKit-HW; ZSWatch Watch-DevKit; Company:; RELEASED; Variant:; Board Name:; ZSWatch-Watch.kicad_pcb; Daniel Kampert; Designer:; Project Name:; Date:; Revision:

# Drill Drawing L1 - L4 (Scale 1:1)

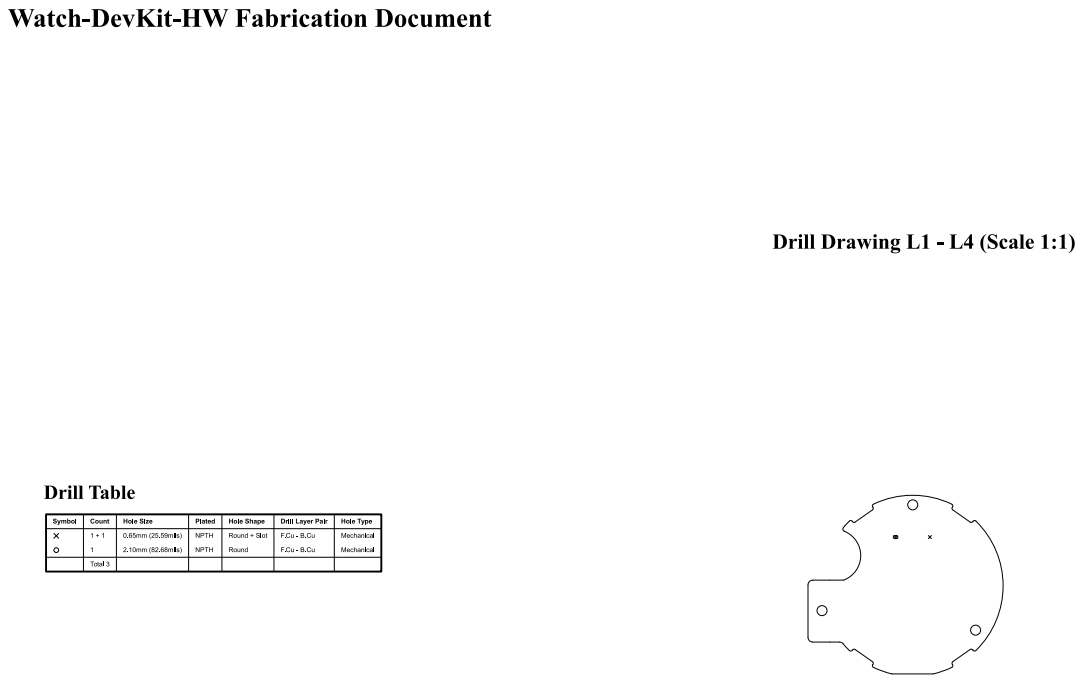
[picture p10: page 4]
Git; Hash:; ZSWatch; Comments:; Drill Drawing (L1 - L4); Sheet Title:; File Name:; Watch-DevKit-HW; ZSWatch Watch-DevKit; Company:; RELEASED; Variant:; Board Name:; ZSWatch-Watch.kicad_pcb; Daniel Kampert; Designer:; Project Name:; Date:; Revision:

# Top Test Points (Scale 1:1)

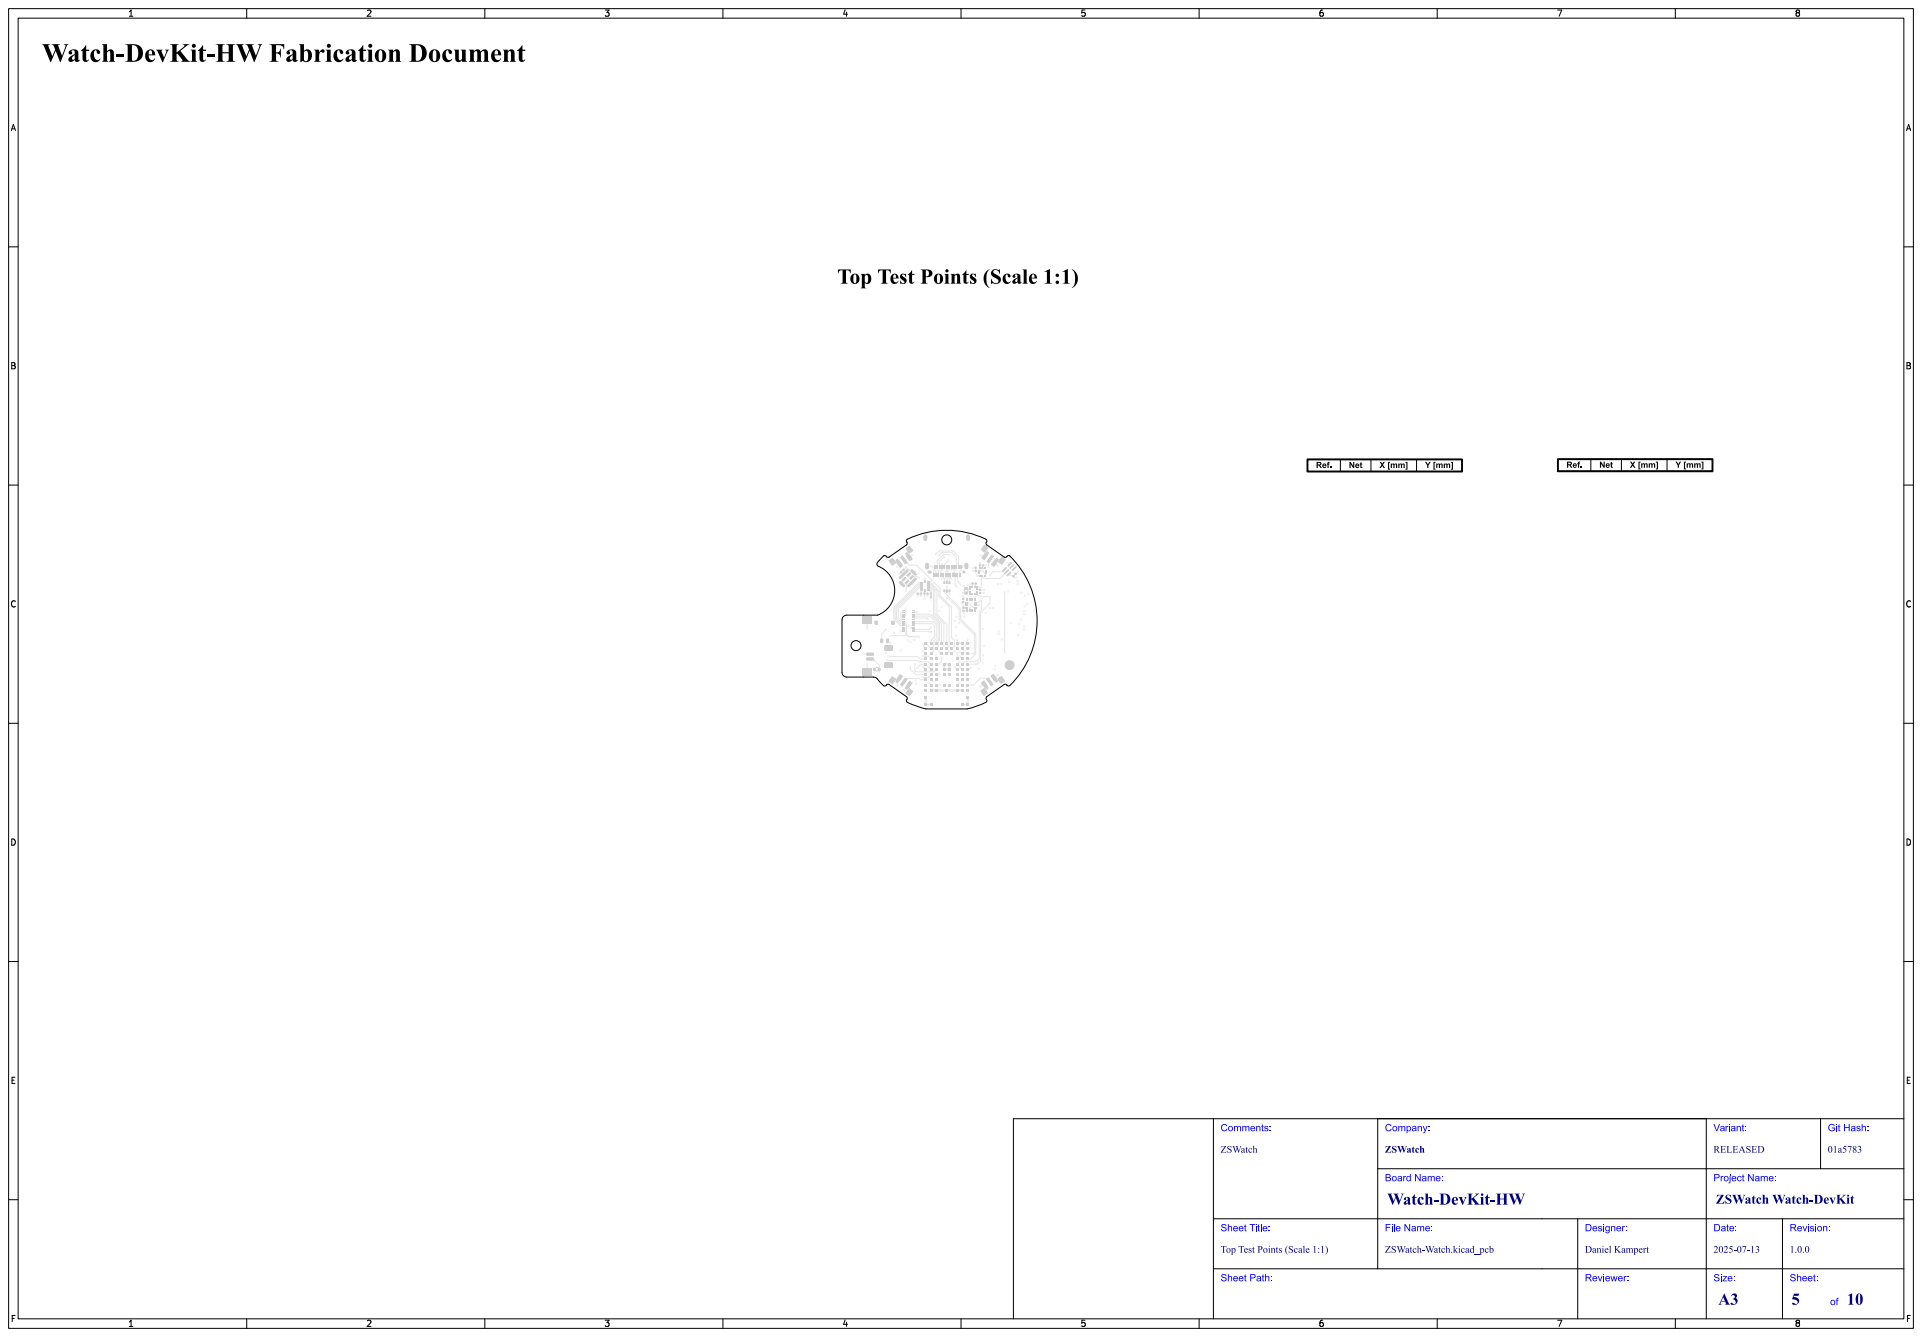
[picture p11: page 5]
Git; Hash:; ZSWatch; Comments:; Sheet Title:; File Name:; Watch-DevKit-HW; ZSWatch Watch-DevKit; Company:; RELEASED; Variant:; Board Name:; ZSWatch-Watch.kicad_pcb; Daniel Kampert; Designer:; Project Name:; Date:; Revision:

Top Test Points (Scale 1:1)

# Bottom Test Points (Scale 1:1)

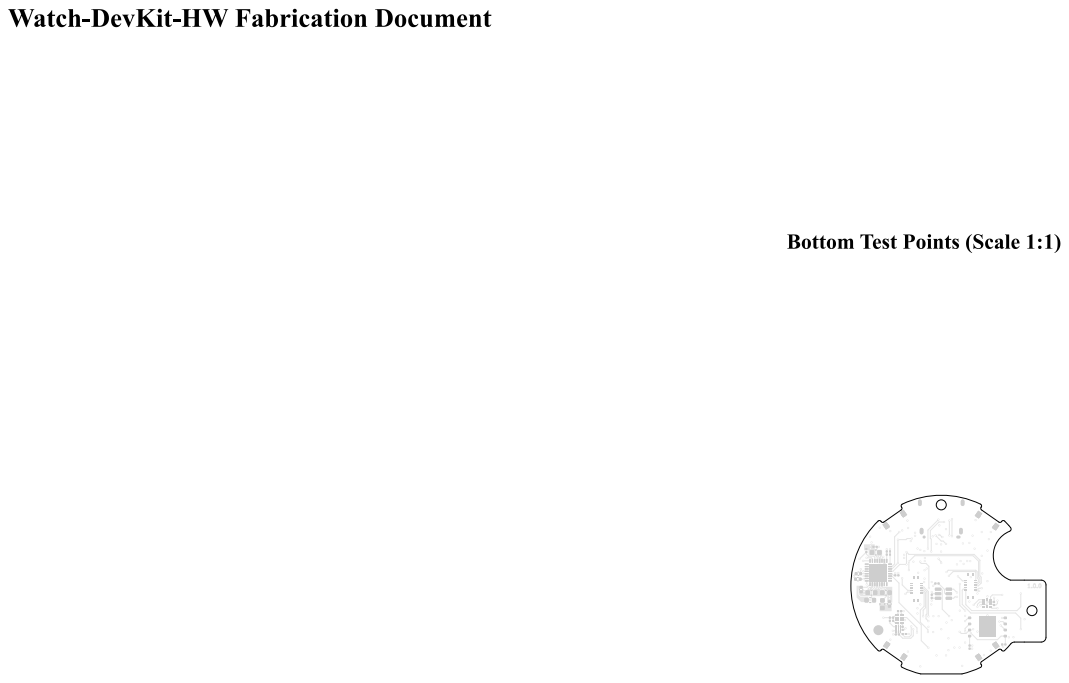
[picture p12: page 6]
Git; Hash:; ZSWatch; Comments:; Sheet Title:; File Name:; Watch-DevKit-HW; ZSWatch Watch-DevKit; Company:; RELEASED; Variant:; Board Name:; ZSWatch-Watch.kicad_pcb; Daniel Kampert; Designer:; Project Name:; Date:; Revision:

Bottom Test Points (Scale 1:1)

# F.Cu (Scale 1:1)

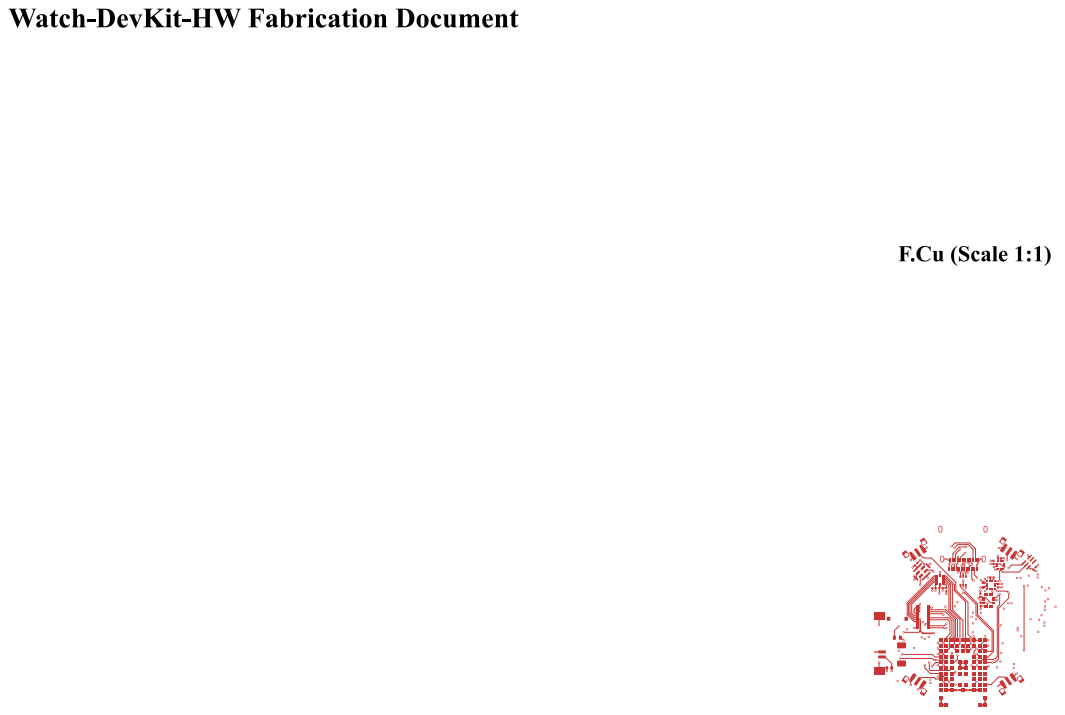
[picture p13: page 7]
Git; Hash:; ZSWatch; Comments:; F.Cu (Scale 1:1); Sheet Title:; File Name:; Watch-DevKit-HW; ZSWatch Watch-DevKit; Company:; RELEASED; Variant:; Board Name:; ZSWatch-Watch.kicad_pcb; Daniel Kampert; Designer:; Project Name:; Date:; Revision:

# Inner1 (Scale 1:1)

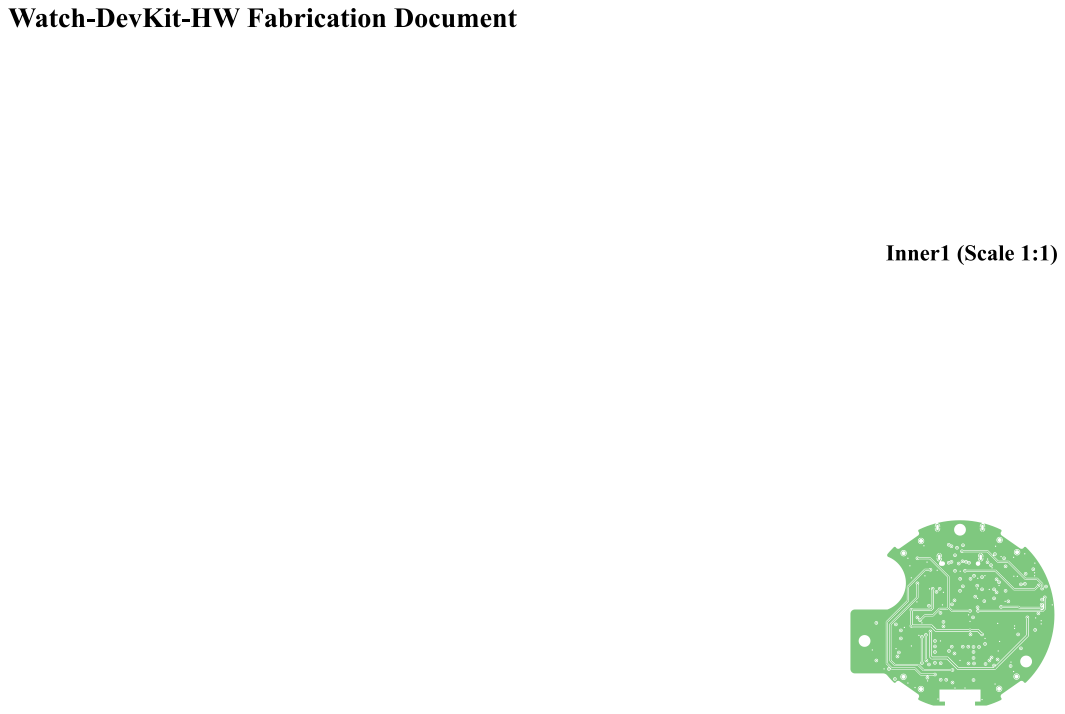
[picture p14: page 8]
Git; Hash:; ZSWatch; Comments:; Inner1 (Scale 1:1); Sheet Title:; File Name:; Watch-DevKit-HW; ZSWatch Watch-DevKit; Company:; RELEASED; Variant:; Board Name:; ZSWatch-Watch.kicad_pcb; Daniel Kampert; Designer:; Project Name:; Date:; Revision:

# Inner2 (Scale 1:1)

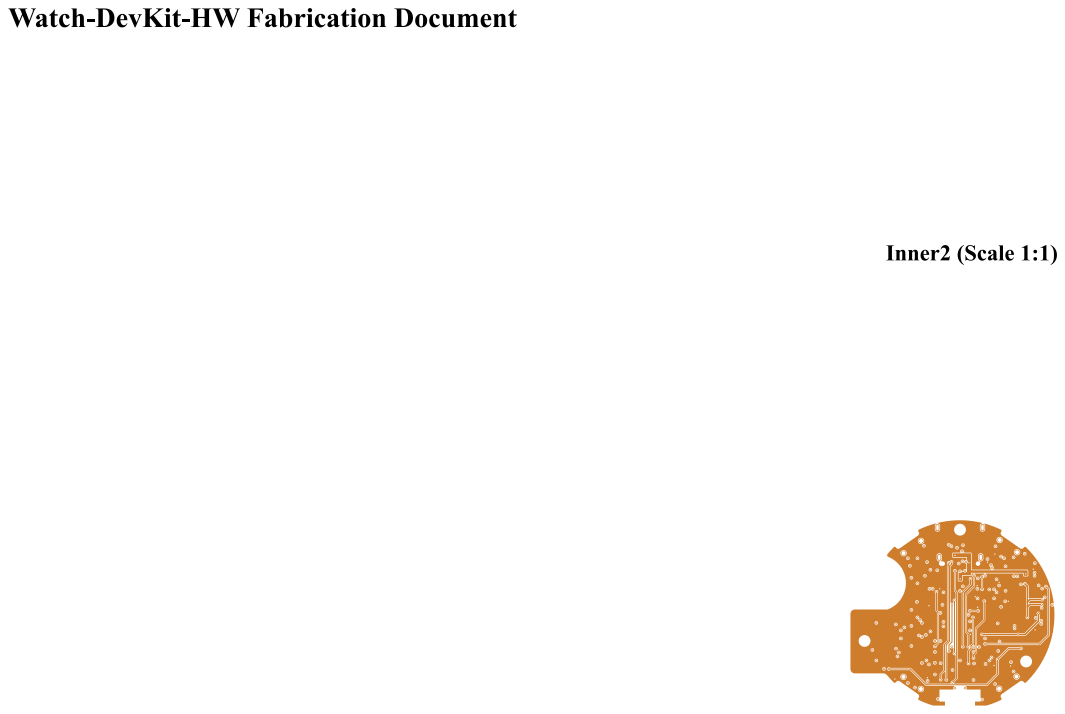
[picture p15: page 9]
Git; Hash:; ZSWatch; Comments:; Inner2 (Scale 1:1); Sheet Title:; File Name:; Watch-DevKit-HW; ZSWatch Watch-DevKit; Company:; RELEASED; Variant:; Board Name:; ZSWatch-Watch.kicad_pcb; Daniel Kampert; Designer:; Project Name:; Date:; Revision:

# B.Cu (Scale 1:1)

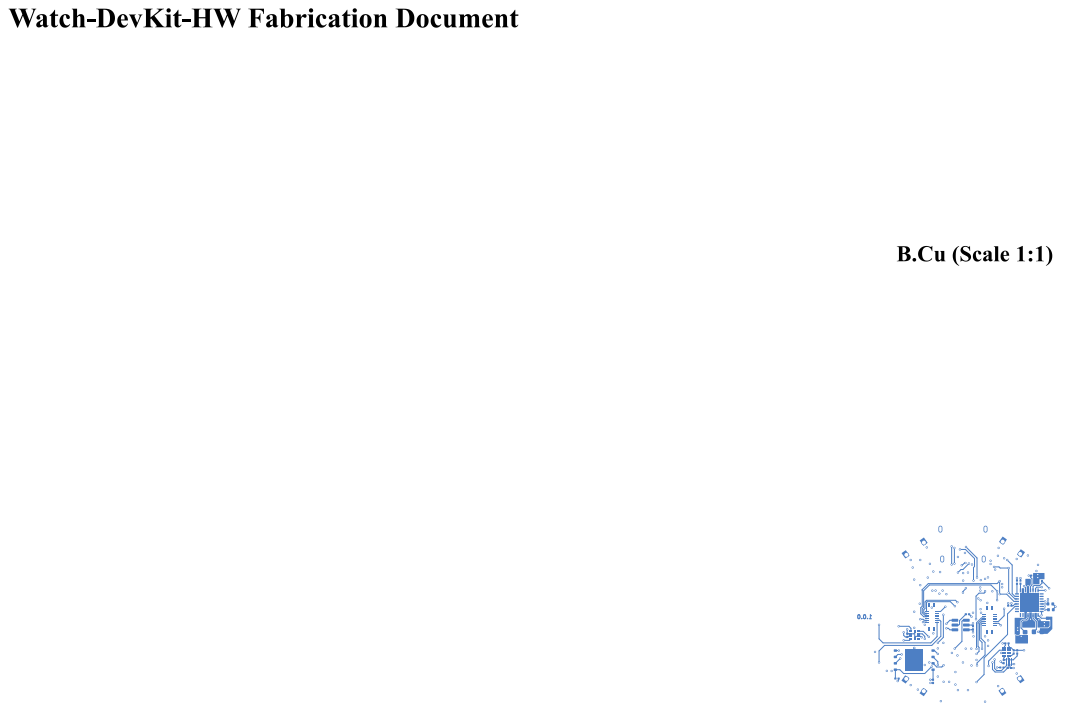
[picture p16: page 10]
Git; Hash:; ZSWatch; Comments:; B.Cu (Scale 1:1); Sheet Title:; File Name:; Watch-DevKit-HW; ZSWatch Watch-DevKit; Company:; RELEASED; Variant:; Board Name:; ZSWatch-Watch.kicad_pcb; Daniel Kampert; Designer:; Project Name:; Date:; Revision:

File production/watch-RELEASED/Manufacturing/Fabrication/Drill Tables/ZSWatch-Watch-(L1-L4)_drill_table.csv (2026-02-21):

Count | Hole Size | Plated | Hole Shape | Drill Layer Pair | Hole Type
182 | 0.25mm (9.84mils) | PTH | Round | F.Cu - B.Cu | Via
4 | 0.50mm (19.69mils) | PTH | Slot | F.Cu - B.Cu | Pad
8 | 0.80mm (31.50mils) | PTH | Round | F.Cu - B.Cu | Pad
Total 194

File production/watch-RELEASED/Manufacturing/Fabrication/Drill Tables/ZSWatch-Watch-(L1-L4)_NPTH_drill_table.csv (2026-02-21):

Count | Hole Size | Plated | Hole Shape | Drill Layer Pair | Hole Type
1 + 1 | 0.65mm (25.59mils) | NPTH | Round + Slot | F.Cu - B.Cu | Mechanical
1 | 2.10mm (82.68mils) | NPTH | Round | F.Cu - B.Cu | Mechanical
Total 3

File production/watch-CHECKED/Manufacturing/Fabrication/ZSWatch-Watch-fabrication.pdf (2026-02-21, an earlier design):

# Top Fabrication (Scale 1:1)

# Watch-DevKit-HW Fabrication Document

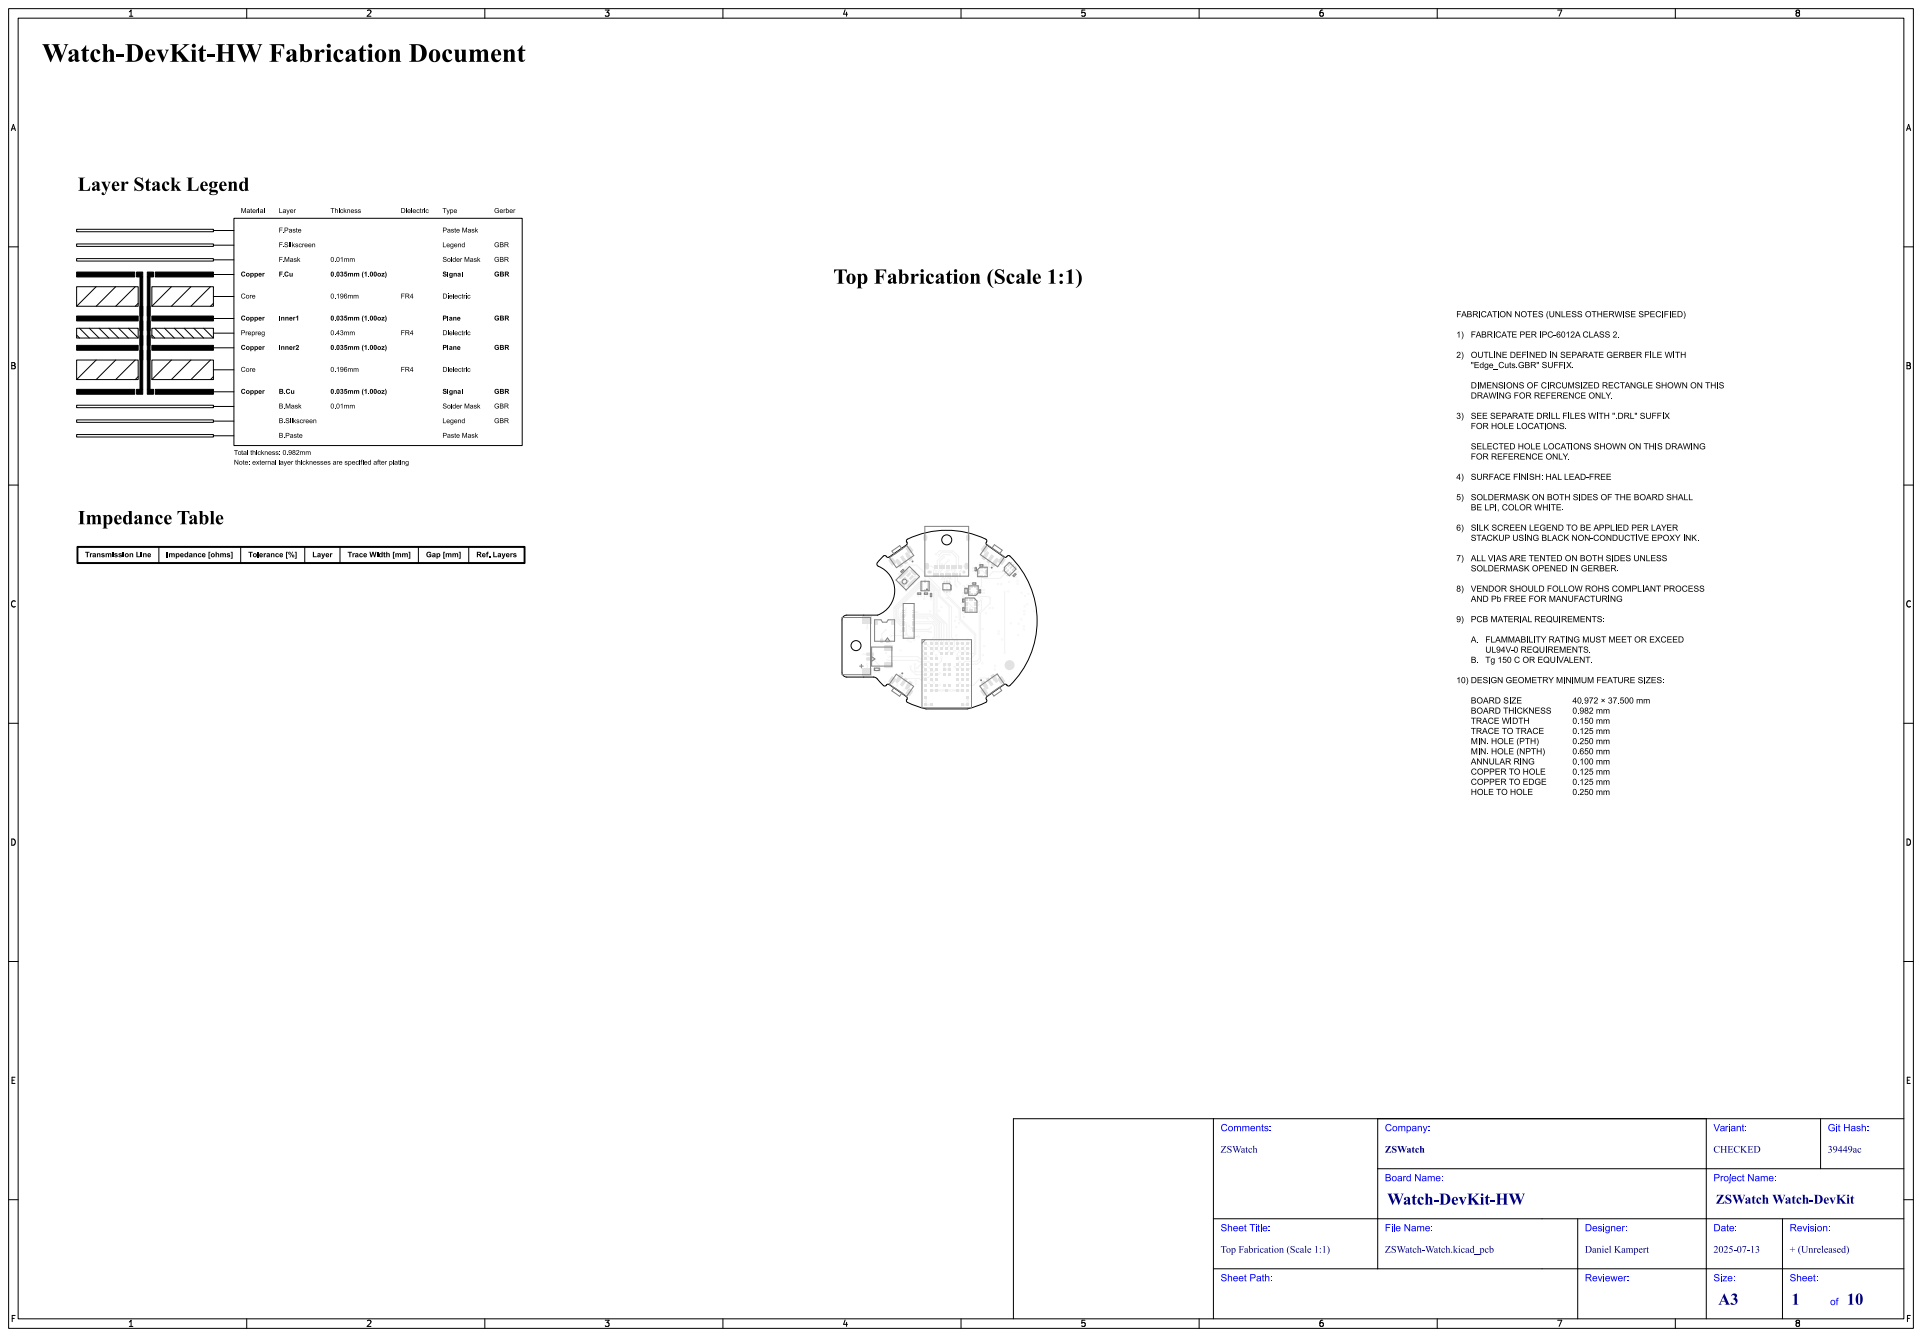
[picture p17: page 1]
Git Hash:; ZSWatch; Comments:; Sheet Path:; Sheet Title:; File Name:; Watch-DevKit-HW; ZSWatch Watch-DevKit; Company:; CHECKED; Variant:; Board Name:; ZSWatch-Watch.kicad_pcb; Daniel Kampert; Designer:; Reviewer:; Project Name:; Date:; + (Unreleased); Revision:; Size:; Sheet:

Top Fabrication (Scale 1:1)

# Bottom Fabrication (Scale 1:1)

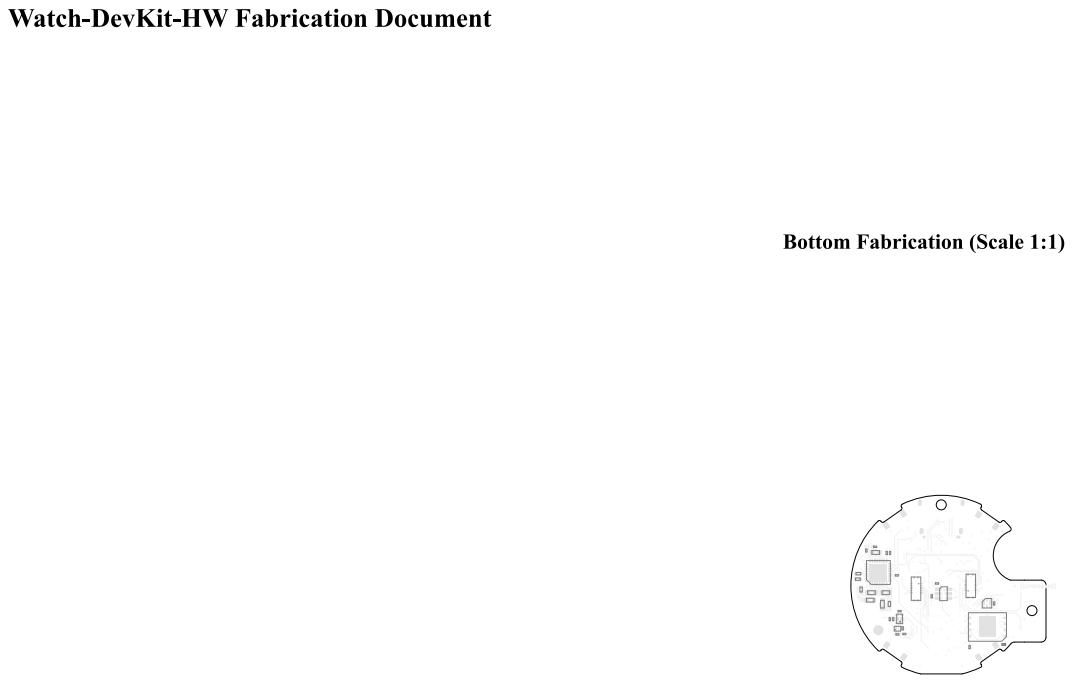
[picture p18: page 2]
Git; Hash:; ZSWatch; Comments:; Sheet Title:; File Name:; Watch-DevKit-HW; ZSWatch Watch-DevKit; Company:; CHECKED; Variant:; Board Name:; ZSWatch-Watch.kicad_pcb; Daniel Kampert; Designer:; Project Name:; Date:; + (Unreleased); Revision:

Bottom Fabrication (Scale 1:1)

# Drill Drawing L1 - L4 (Scale 1:1)

Git; Hash:; ZSWatch; Comments:; Drill Drawing (L1 - L4); Sheet Title:; File Name:; Watch-DevKit-HW; ZSWatch Watch-DevKit; Company:; CHECKED; Variant:; Board Name:; ZSWatch-Watch.kicad_pcb; Daniel Kampert; Designer:; Project Name:; Date:; + (Unreleased); Revision:

# Drill Drawing L1 - L4 (Scale 1:1)

Git; Hash:; ZSWatch; Comments:; Drill Drawing (L1 - L4); Sheet Title:; File Name:; Watch-DevKit-HW; ZSWatch Watch-DevKit; Company:; CHECKED; Variant:; Board Name:; ZSWatch-Watch.kicad_pcb; Daniel Kampert; Designer:; Project Name:; Date:; + (Unreleased); Revision:

# Top Test Points (Scale 1:1)

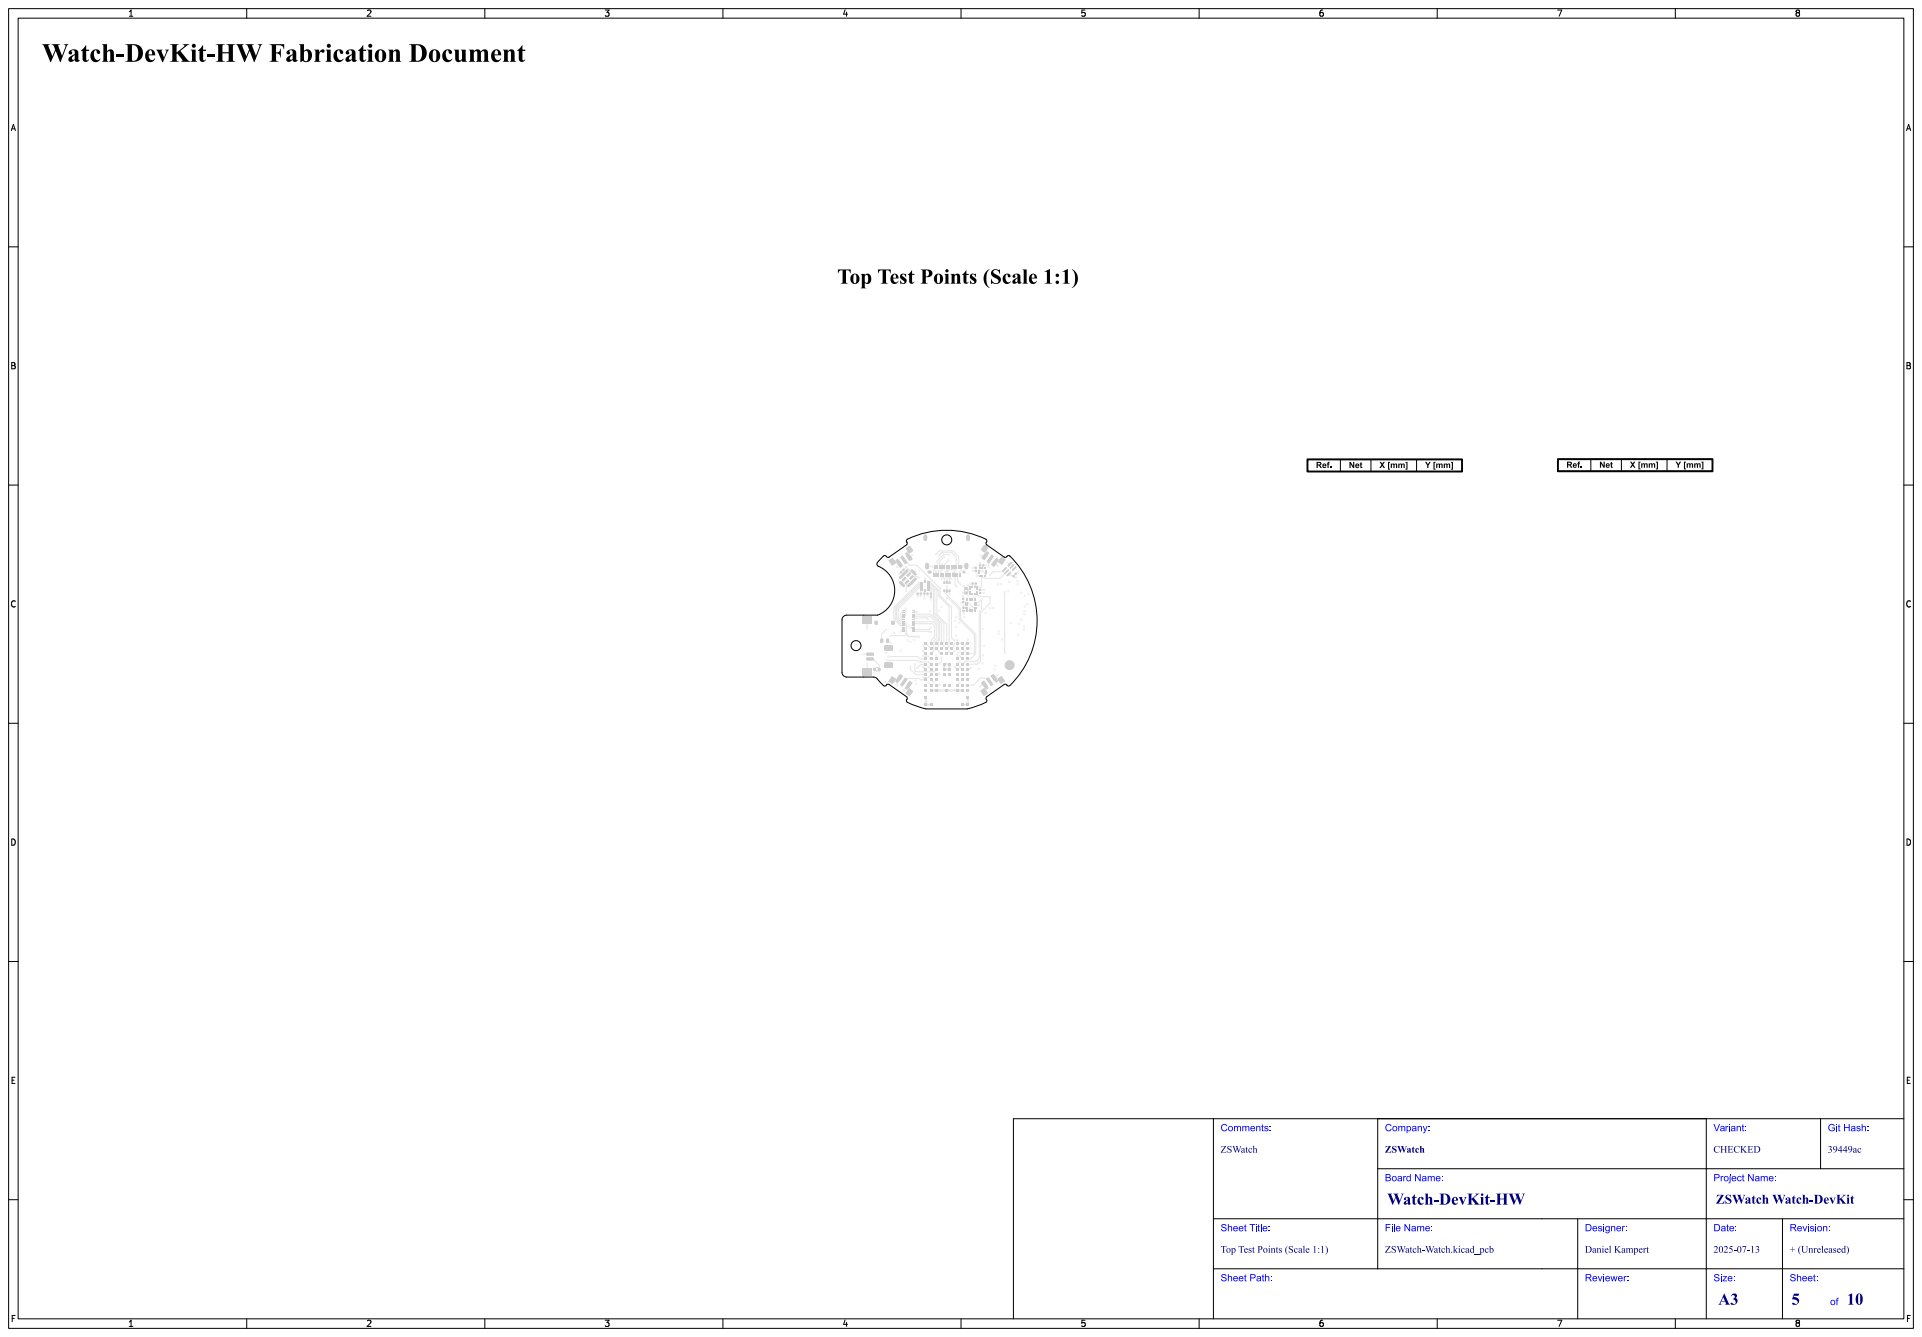
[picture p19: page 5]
Git; Hash:; ZSWatch; Comments:; Sheet Title:; File Name:; Watch-DevKit-HW; ZSWatch Watch-DevKit; Company:; CHECKED; Variant:; Board Name:; ZSWatch-Watch.kicad_pcb; Daniel Kampert; Designer:; Project Name:; Date:; + (Unreleased); Revision:

Top Test Points (Scale 1:1)

# Bottom Test Points (Scale 1:1)

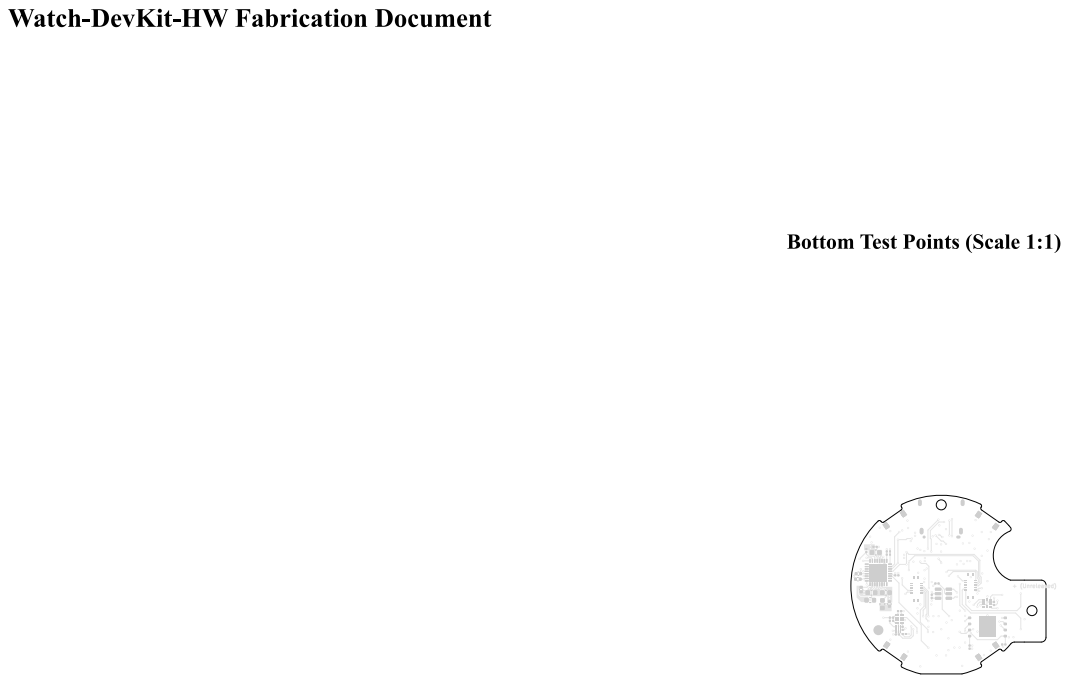
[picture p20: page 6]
Git; Hash:; ZSWatch; Comments:; Sheet Title:; File Name:; Watch-DevKit-HW; ZSWatch Watch-DevKit; Company:; CHECKED; Variant:; Board Name:; ZSWatch-Watch.kicad_pcb; Daniel Kampert; Designer:; Project Name:; Date:; + (Unreleased); Revision:

Bottom Test Points (Scale 1:1)

# F.Cu (Scale 1:1)

Git; Hash:; ZSWatch; Comments:; F.Cu (Scale 1:1); Sheet Title:; File Name:; Watch-DevKit-HW; ZSWatch Watch-DevKit; Company:; CHECKED; Variant:; Board Name:; ZSWatch-Watch.kicad_pcb; Daniel Kampert; Designer:; Project Name:; Date:; + (Unreleased); Revision:

# Inner1 (Scale 1:1)

Git; Hash:; ZSWatch; Comments:; Inner1 (Scale 1:1); Sheet Title:; File Name:; Watch-DevKit-HW; ZSWatch Watch-DevKit; Company:; CHECKED; Variant:; Board Name:; ZSWatch-Watch.kicad_pcb; Daniel Kampert; Designer:; Project Name:; Date:; + (Unreleased); Revision:

# Inner2 (Scale 1:1)

Git; Hash:; ZSWatch; Comments:; Inner2 (Scale 1:1); Sheet Title:; File Name:; Watch-DevKit-HW; ZSWatch Watch-DevKit; Company:; CHECKED; Variant:; Board Name:; ZSWatch-Watch.kicad_pcb; Daniel Kampert; Designer:; Project Name:; Date:; + (Unreleased); Revision:

# B.Cu (Scale 1:1)

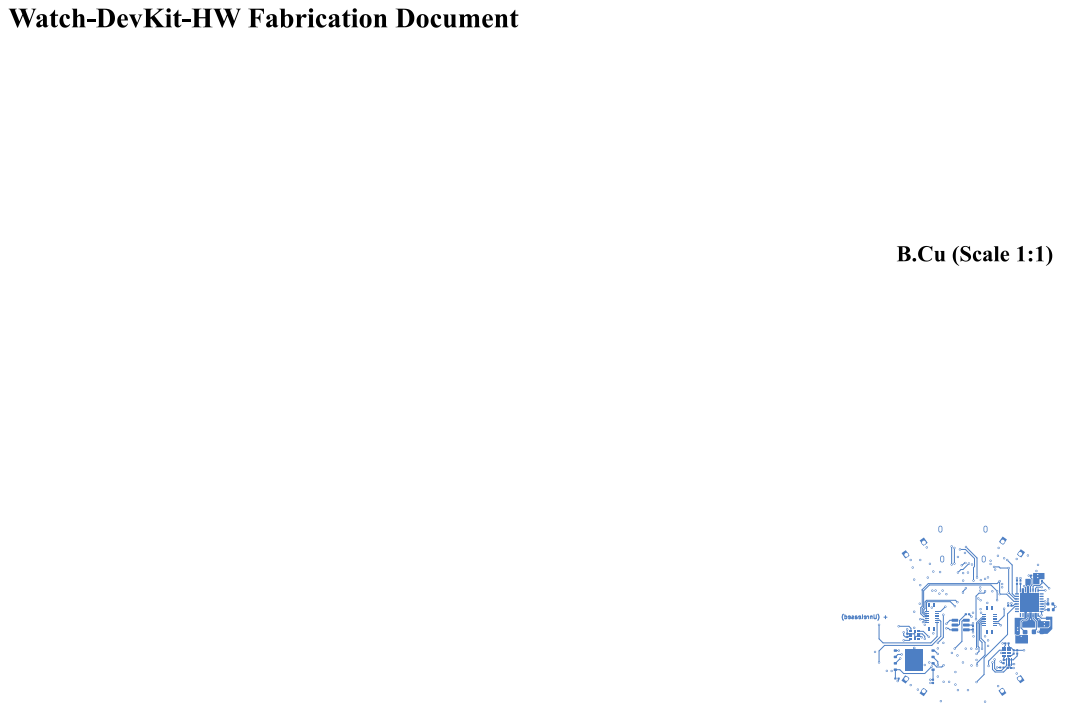
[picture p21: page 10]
Git; Hash:; ZSWatch; Comments:; B.Cu (Scale 1:1); Sheet Title:; File Name:; Watch-DevKit-HW; ZSWatch Watch-DevKit; Company:; CHECKED; Variant:; Board Name:; ZSWatch-Watch.kicad_pcb; Daniel Kampert; Designer:; Project Name:; Date:; + (Unreleased); Revision:

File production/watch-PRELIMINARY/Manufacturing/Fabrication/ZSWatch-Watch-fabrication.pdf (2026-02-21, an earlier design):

# Top Fabrication (Scale 1:1)

# Watch-DevKit-HW Fabrication Document

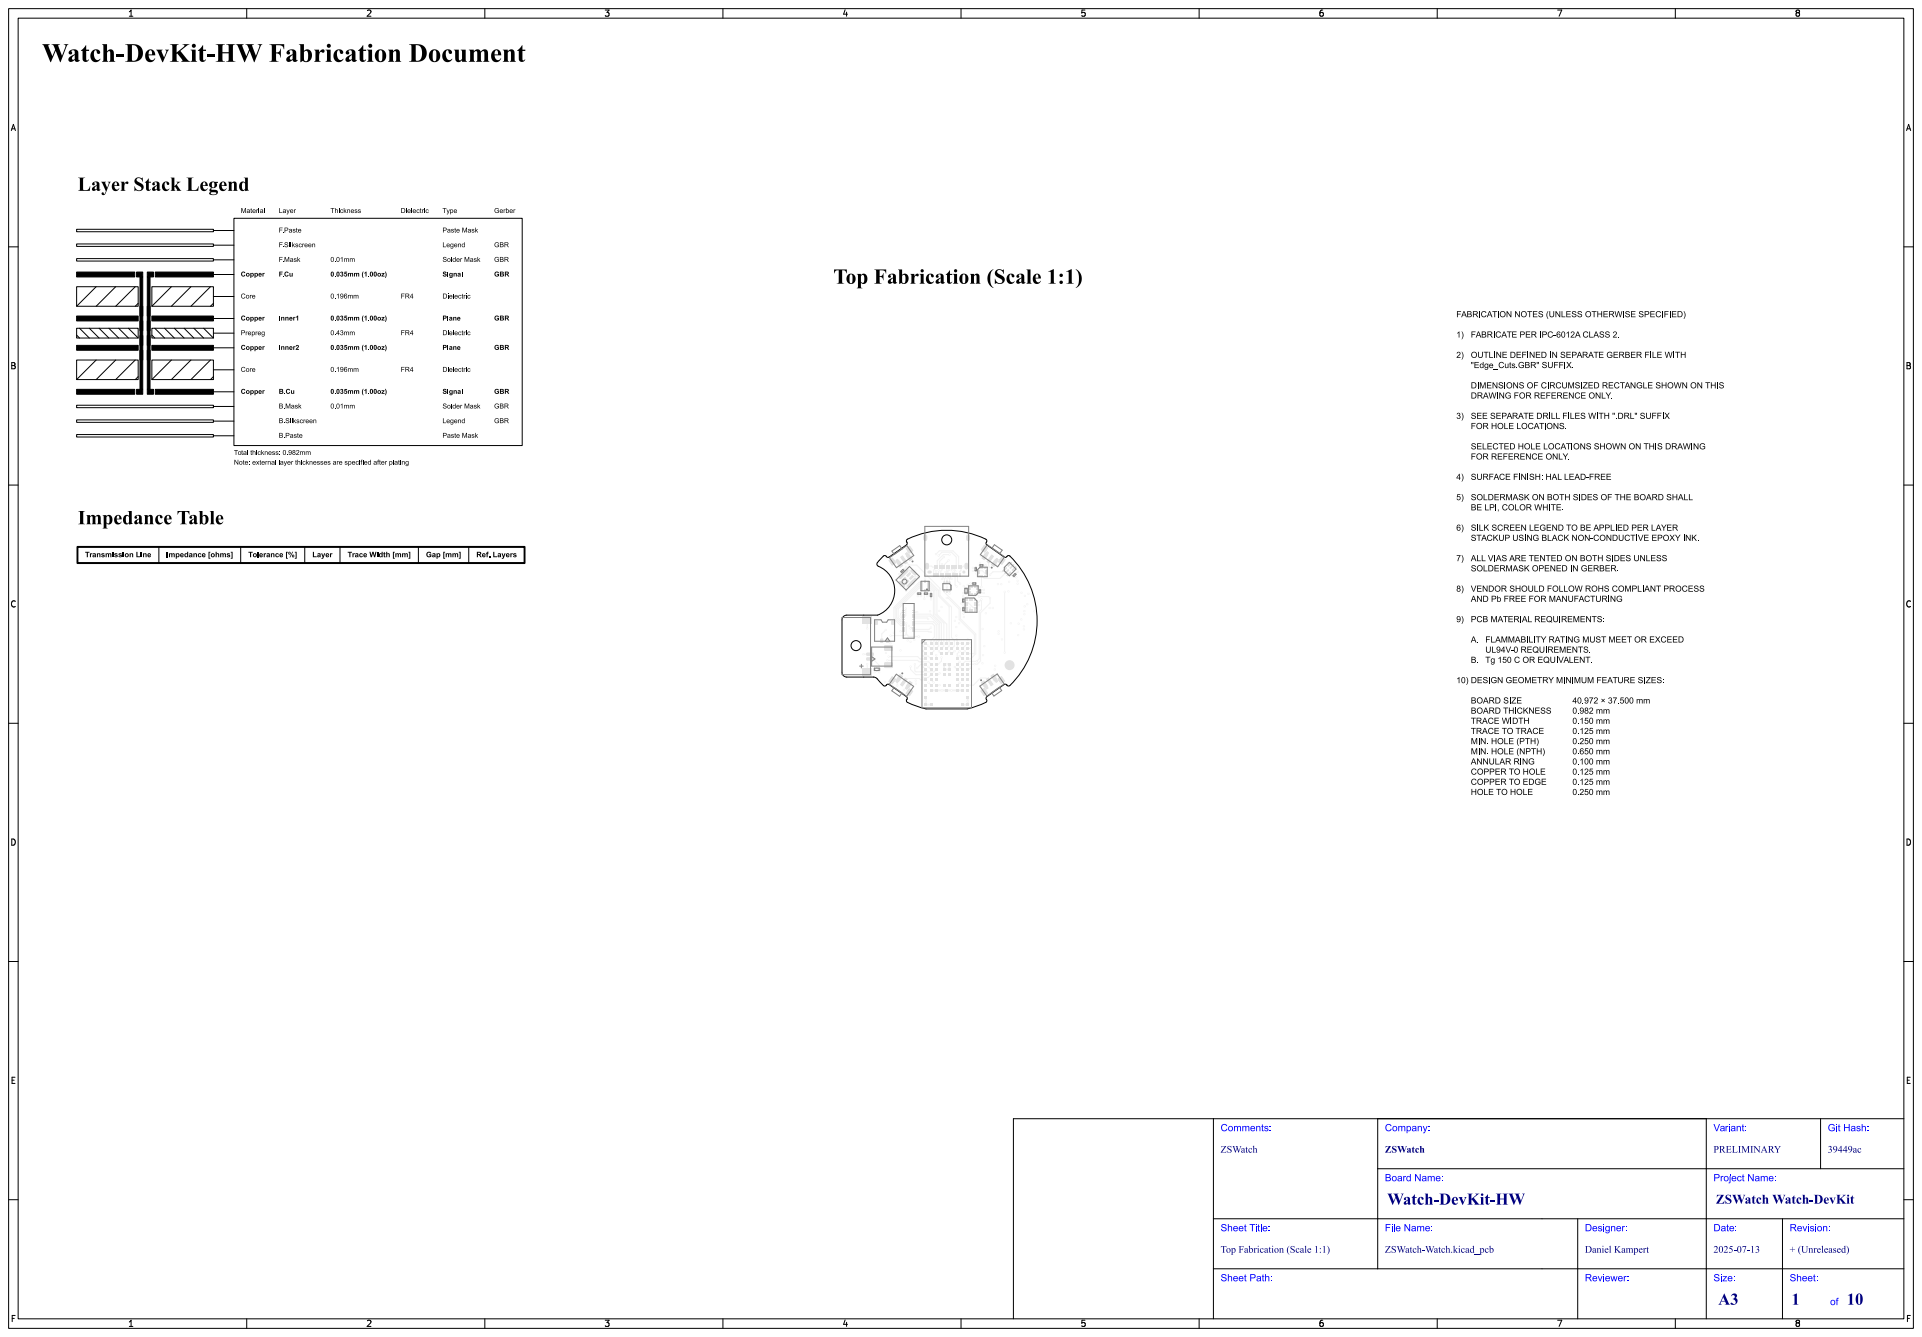
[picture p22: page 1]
Git Hash:; ZSWatch; Comments:; Sheet Path:; Sheet Title:; File Name:; Watch-DevKit-HW; ZSWatch Watch-DevKit; Company:; PRELIMINARY; Variant:; Board Name:; ZSWatch-Watch.kicad_pcb; Daniel Kampert; Designer:; Reviewer:; Project Name:; Date:; + (Unreleased); Revision:; Size:; Sheet:

Top Fabrication (Scale 1:1)

# Bottom Fabrication (Scale 1:1)

Git; Hash:; ZSWatch; Comments:; Sheet Title:; File Name:; Watch-DevKit-HW; ZSWatch Watch-DevKit; Company:; PRELIMINARY; Variant:; Board Name:; ZSWatch-Watch.kicad_pcb; Daniel Kampert; Designer:; Project Name:; Date:; + (Unreleased); Revision:

Bottom Fabrication (Scale 1:1)

# Drill Drawing L1 - L4 (Scale 1:1)

Git; Hash:; ZSWatch; Comments:; Drill Drawing (L1 - L4); Sheet Title:; File Name:; Watch-DevKit-HW; ZSWatch Watch-DevKit; Company:; PRELIMINARY; Variant:; Board Name:; ZSWatch-Watch.kicad_pcb; Daniel Kampert; Designer:; Project Name:; Date:; + (Unreleased); Revision:

# Drill Drawing L1 - L4 (Scale 1:1)

Git; Hash:; ZSWatch; Comments:; Drill Drawing (L1 - L4); Sheet Title:; File Name:; Watch-DevKit-HW; ZSWatch Watch-DevKit; Company:; PRELIMINARY; Variant:; Board Name:; ZSWatch-Watch.kicad_pcb; Daniel Kampert; Designer:; Project Name:; Date:; + (Unreleased); Revision:

# Top Test Points (Scale 1:1)

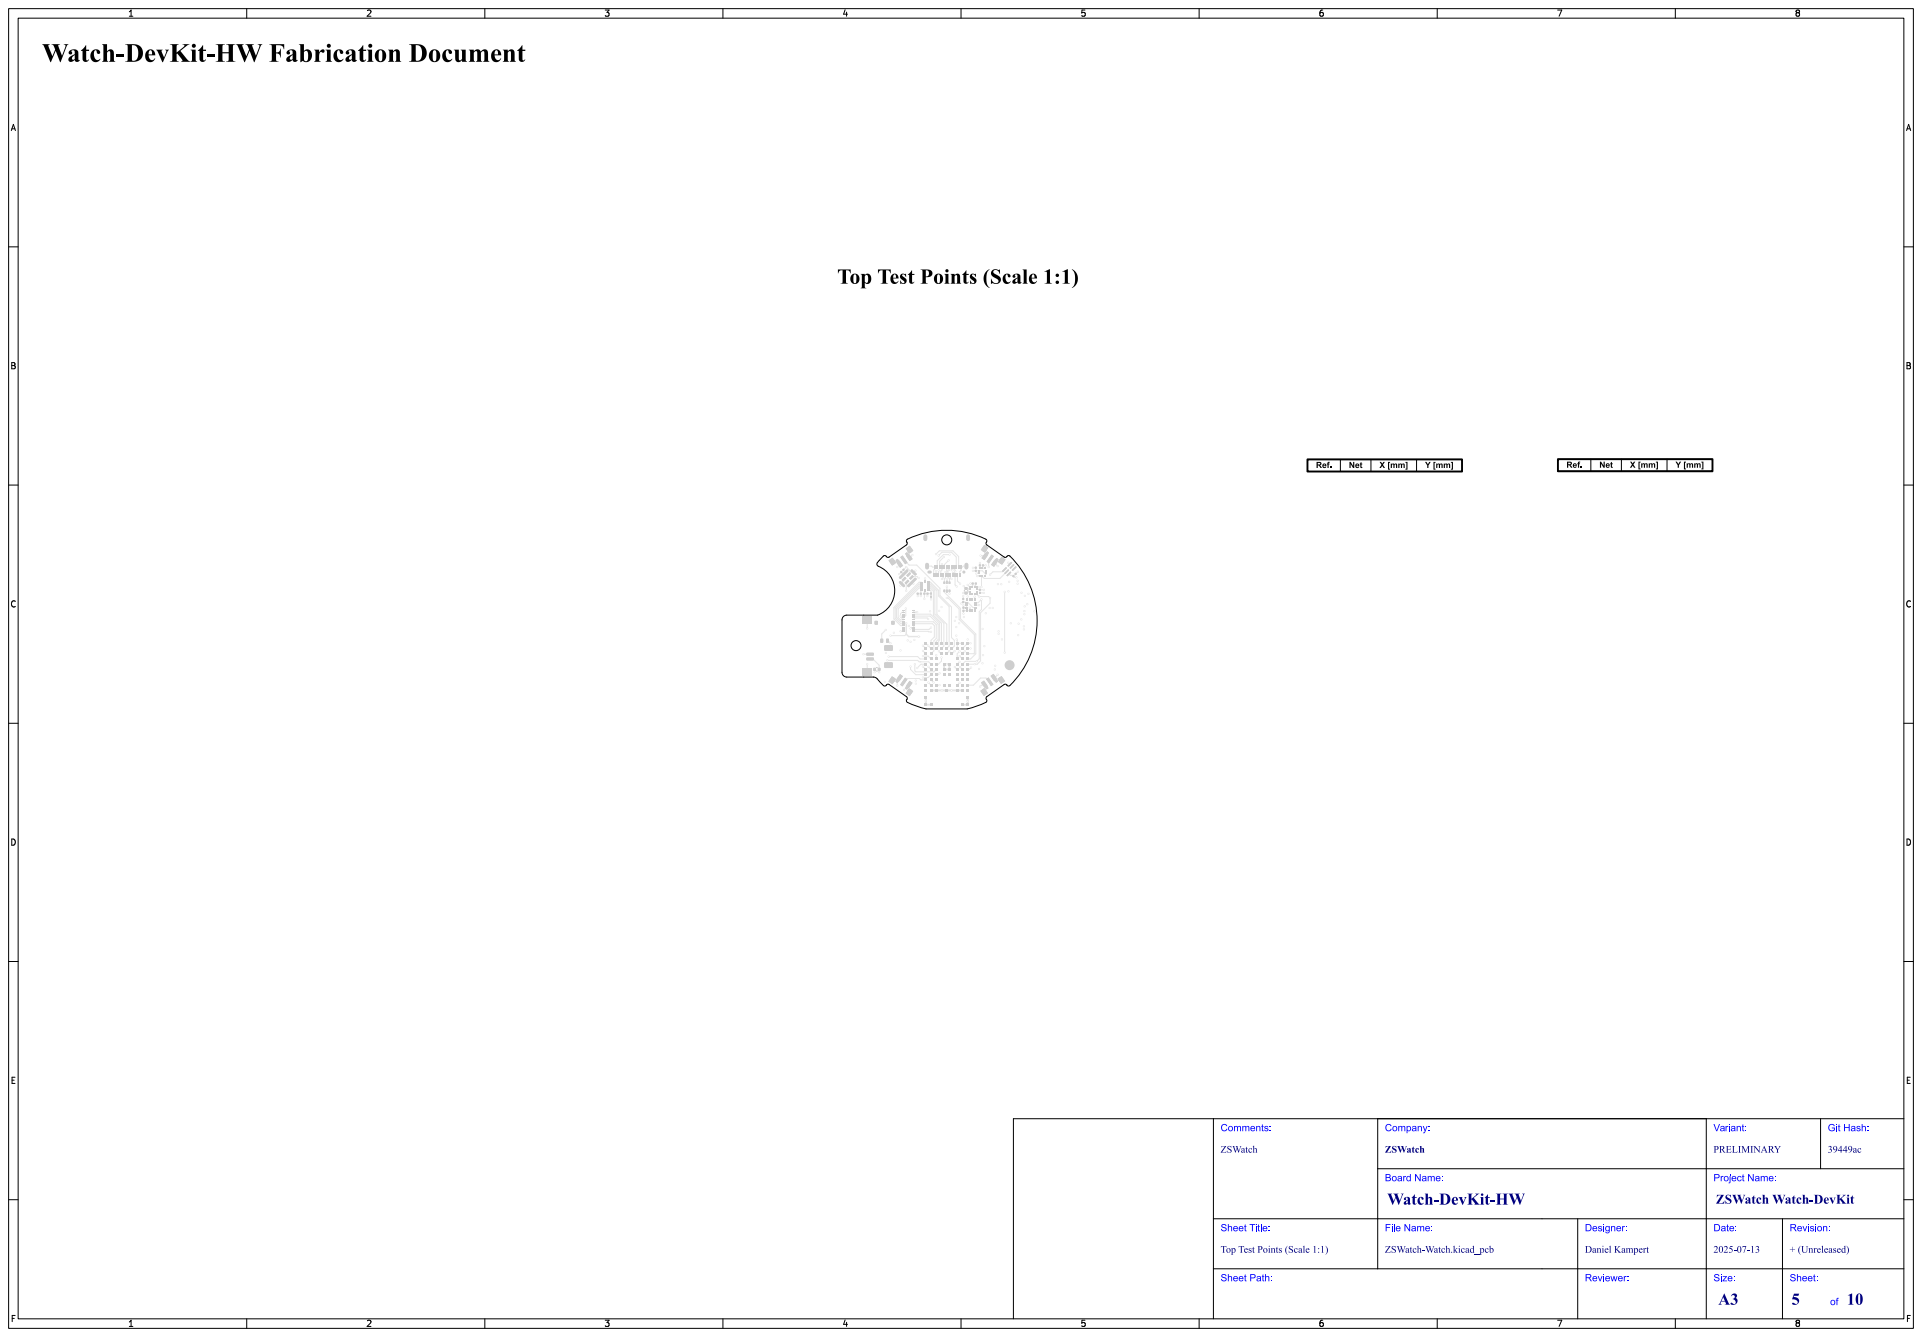
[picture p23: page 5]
Git; Hash:; ZSWatch; Comments:; Sheet Title:; File Name:; Watch-DevKit-HW; ZSWatch Watch-DevKit; Company:; PRELIMINARY; Variant:; Board Name:; ZSWatch-Watch.kicad_pcb; Daniel Kampert; Designer:; Project Name:; Date:; + (Unreleased); Revision:

Top Test Points (Scale 1:1)

# Bottom Test Points (Scale 1:1)

Git; Hash:; ZSWatch; Comments:; Sheet Title:; File Name:; Watch-DevKit-HW; ZSWatch Watch-DevKit; Company:; PRELIMINARY; Variant:; Board Name:; ZSWatch-Watch.kicad_pcb; Daniel Kampert; Designer:; Project Name:; Date:; + (Unreleased); Revision:

Bottom Test Points (Scale 1:1)

# F.Cu (Scale 1:1)

Git; Hash:; ZSWatch; Comments:; F.Cu (Scale 1:1); Sheet Title:; File Name:; Watch-DevKit-HW; ZSWatch Watch-DevKit; Company:; PRELIMINARY; Variant:; Board Name:; ZSWatch-Watch.kicad_pcb; Daniel Kampert; Designer:; Project Name:; Date:; + (Unreleased); Revision:

# Inner1 (Scale 1:1)

Git; Hash:; ZSWatch; Comments:; Inner1 (Scale 1:1); Sheet Title:; File Name:; Watch-DevKit-HW; ZSWatch Watch-DevKit; Company:; PRELIMINARY; Variant:; Board Name:; ZSWatch-Watch.kicad_pcb; Daniel Kampert; Designer:; Project Name:; Date:; + (Unreleased); Revision:

# Inner2 (Scale 1:1)

Git; Hash:; ZSWatch; Comments:; Inner2 (Scale 1:1); Sheet Title:; File Name:; Watch-DevKit-HW; ZSWatch Watch-DevKit; Company:; PRELIMINARY; Variant:; Board Name:; ZSWatch-Watch.kicad_pcb; Daniel Kampert; Designer:; Project Name:; Date:; + (Unreleased); Revision:

# B.Cu (Scale 1:1)

Git; Hash:; ZSWatch; Comments:; B.Cu (Scale 1:1); Sheet Title:; File Name:; Watch-DevKit-HW; ZSWatch Watch-DevKit; Company:; PRELIMINARY; Variant:; Board Name:; ZSWatch-Watch.kicad_pcb; Daniel Kampert; Designer:; Project Name:; Date:; + (Unreleased); Revision:

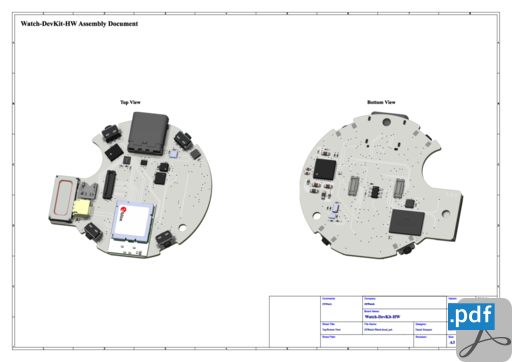
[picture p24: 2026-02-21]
production/watch-RELEASED/HTML/images/cat_pdf_assembly_ZSWatch-Watch-assembly.png

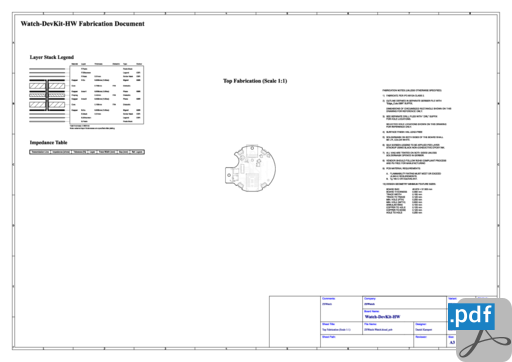
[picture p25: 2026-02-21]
production/watch-RELEASED/HTML/images/cat_pdf_fabrication_ZSWatch-Watch-fabrication.png

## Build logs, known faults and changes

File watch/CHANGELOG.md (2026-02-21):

# Changelog

## [Unreleased]

## [1.0.0] - 2026-02-21

**Added:**

Initial release

[Unreleased]: https://github.com/ZSWatch/Watch-HW/compare/1.0.0...HEAD

[1.0.0]: https://github.com/ZSWatch/Watch-HW/compare/95d0aab8f4096c096bc494c76be4f3cb53c9ec07...1.0.0

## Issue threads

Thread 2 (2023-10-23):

PCBWay Assembly Can't Locate Pomagtor (RD90_LZH0230529-004_DJ-5PIN_PH2_54) & EastRising(ER-CON0.4-24P)

xorb22, 2023-10-23:
I tried ordering the HW PCB and assembly through PCBWay, but upon review by PCBWay, they could not locate the following components.

33 | X1 | 1 | Pomagtor | RD90_LZH0230529-004_DJ-5PIN_PH2_54 | DOCK | Pomagtor:RD90_LZH0230529-004_DJ-5PIN_PH2_54 | THT | We can find this part number. Please confirm the correct part number.

34 | X8 | 1 | EastRising | ER-CON0.4-24P | OK-24F024-04 | EastRising:ER-CON0.4-24P | SMD | We can find this part number. Please confirm the correct part number.

How can i overcome this?

Thanks

jakkra, 2023-10-23:
Hi, the first one is a Do not mount, so they should not source it. It's a custom connector I have gotten manufactured for me. the BOM.xls is updated to more clearly state this.

Second one OK-24F024-04 is the correct number and this should be used for sourcing, and they have successfully sourced this part two times for me. Updated the BOM.xls to make it clearer this is the part number.

Fixed in main now https://github.com/jakkra/ZSWatch-HW/commit/0e061375c47cf4ed94781e597d2eb1aed2d0d848

xorb22, 2023-10-28:
For the custom Pomagtor connector, how can I get it done and assembled on the pcb? Do you instruction for those?

Thanks

jakkra, 2023-10-28:
> For the custom Pomagtor connector, how can I get it done and assembled on the pcb? Do you instruction for those?
>
> Thanks

You need to buy a low profile standard 1.54 mm female pin header and solder on yourself.

xorb22, 2023-10-28:
Thanks. Any chance you could share which component you used? From where?
Thanks

jakkra, 2023-10-28:
> Thanks. Any chance you could share which component you used? From where? Thanks

There is not documentation yet for this, you are a bit early, have not had time to write it all. So note this project is not for beginners, at least not right now.

This is the pin header I have used before, it's about 3.6mm heigh. I don't remember where I bought it however and could not find where I bought it. So you will need to search around a bit.

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

Depending on whwre you live, I may be able to ship one dock connector + cable, but you need to conect me on discord then: jakkra

Closed 2023-10-23.

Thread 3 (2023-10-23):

Please fill in total quantity of single PCBs

HUGOW04, 2023-10-23:
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

HUGOW04, 2023-10-23:
I can also not upload 4 files just one on the upload .png
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

jakkra, 2023-10-23:
Hi @HUGOW04 the quantity is the amount of PCBs you want PCBWay to assemble, you fill that in.

You can add more files when you have it on the Cart also. I ordered just 2 weeks ago and could upload all necessary files.
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

jakkra, 2023-10-23:
The above looks correct, there will always be an audit from pcbway for assembly, you will get a quoted BOM from them with the price for components.

HUGOW04, 2023-10-23:
oh thanks I see but do I need to buy some special display and what bettery and display do you recommend??

jakkra, 2023-10-24:
Yes, here:
https://www.buydisplay.com/240x240-round-ips-tft-lcd-display-1-28-capacitive-touch-circle-screen
https://www.aliexpress.com/item/4000121983257.html?spm=a2g0o.order_list.order_list_main.5.4b3418027XxHjE

Closed 2023-10-24.

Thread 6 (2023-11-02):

Using an analog switch to add USB to the magnetic connector

Kampi, 2023-11-02:
**Requirements**

USB Switch with enable (i. e. https://www.ti.com/lit/ds/symlink/ts3usb221a.pdf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)

**Idea**

Use the SWD pins on the magnetic dock connector as USB pins. The switching will be done by the reset line of the watch connector. MCU reset is done via SWD completely.

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

Kampi, 2023-11-02:
The feature will be postponed as long as we don´t know for sure that the switch supports SWD.

Closed 2024-01-29.

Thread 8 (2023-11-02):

Add nPM1300 instead of the current power supply

Kampi, 2023-11-02:
**Parts to remove**

- Remove the LiPo charger
- Remove the battery measurement circuit
- Remove reset circuit
- Remove 1.8 V regulator
- Remove 3.3 V regulator

**Features**

- Integrated battery measurement
- 1.8 voltage per default (BUCK2)
- "Real" reset logic

**Notes**

- Use sensor I2C
- One GPIO as an interrupt source
- Leave CC pins open

**Status**

- [x] Added to the nPM1300 dev board. The board is ordered
- [x] Design is functional, but Software crashes when using the Zephy regulator API

Kampi, 2024-01-30:
- [ ] https://github.com/jakkra/ZSWatch-HW/issues/23#issuecomment-1915787503

Closed 2024-02-05.

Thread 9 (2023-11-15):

1.8-3.3V level shift

DREAM669, 2023-11-15:
Hello, I have noticed that the chip you are using for the 1.8V-3.3V level shift is TXB0104QRUTRQ1, but you are currently using NTS0104GU12. May I know the reason? Is there any defect in TXB0104?Thanks!

Kampi, 2023-11-15:
Hi @DREAM669,

can you explain it further? We are using `NTS0104GU12` in both the schematics and the BOM (at least for rev 3). In theory, both versions should work. The `TXB0104QRUTRQ1` supports a higher voltage range and costs a little bit more.

DREAM669, 2023-11-15:
Hello, I think so. The first version of the schematic used the TXB0104 module, but the later version was changed to NTS0104. Is TXB0104 unable to adapt to Touch functionality?

jakkra, 2023-11-15:
> Hello, I think so. The first version of the schematic used the TXB0104 module, but the later version was changed to NTS0104. Is TXB0104 unable to adapt to Touch functionality?

Yes if I remember correctly it was touch not working because that logic shifter didn't work well for i2c.

Kampi, 2023-11-15:
Hi @DREAM669

does it answer your question and can we close this ticket?

DREAM669, 2023-11-16:
Of course, my problem has been resolved. Thank you.

Closed 2023-11-16.

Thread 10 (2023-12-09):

Part Substitutions from PCBWAY

taintedkernel, 2023-12-09:
Hello, thank you for all the work on this project.  I'm looking to get an assembled device from PCBWAY and I submitted the files that you've created.

They responded that a few items needed review:
* AT25SL128A-MHE-T to be substituted for AT25SL128A
* RD90_LZH0230529-004_DJ-5PIN_PH2_54 needs an exact part number but I see it's noted as "do not assemble"
* OK-24F024-04 cannot be found and a replacement is needed

Appreciate any help you can provide here.

WenchongWang, 2023-12-09:
这是来自QQ邮箱的假期自动回复邮件。邮件已经收到，我会尽快回复您。

Kampi, 2023-12-09:
Hi @taintedkernel

- AT25SL128A-MHE-T -> Correct
- RD90_LZH0230529-004_DJ-5PIN_PH2_54 -> Not available for regular ordering. @jakkra can provide this part to you and you have to solder it on your own (or send it to PCBWay)
- OK-24F024-04 -> Should be available through PCBWay. @jakkra can you please check the part in the BOM of your last order?

jakkra, 2023-12-10:
@taintedkernel PCBway should be able to source the OK-24F024-04
See quoted BOM
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

taintedkernel, 2023-12-12:
Thank you @Kampi @jakkra, I've passed this along to PCBWay and will await their response.

taintedkernel, 2023-12-15:
I received the same response back from them, they cannot source the part.  I see an item available on Alibaba which looks like a match:
* https://www.alibaba.com/product-detail/OK-24F024-04-Connector-Electronic-Components_1600483272580.html

I have a decent amount of soldering experience - would this component be something I can hand solder myself after the rest of the device is assembled and shipped?  The leads seem fairly well-exposed and from what I can tell via KiCad there looks to be sufficient clearance to get an iron in.  Mainly, I'd want to avoid using a hotplate after assembly of the rest of the device.

jakkra, 2023-12-15:
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

Very strange. Don't know what else I can do, they have sources it for me successfully on 3 different orders.
If you didn't already order the display you cab order it together with the connector https://www.buydisplay.com/240x240-round-ips-tft-lcd-display-1-28-capacitive-touch-circle-screen

jakkra, 2023-12-15:
You could try giving them this order number and say in it they managed to source the components
 T-X24W564276A

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

taintedkernel, 2023-12-15:
Thanks for the info.  I passed along that order number to them and will await their reply.  If they can no longer get it, then I'll go the route of ordering the connector with the display.  I'm fairly confident I'll be able to solder it with an iron or hot air.

I wonder if swapping to a different part might be necessary at some point?  I don't have much experience sourcing connectors, but I've definitely seen similar ones in many devices I've disassembled - it does seem odd there isn't much luck with a match on DigiKey.

Kampi, 2023-12-15:
Hi @taintedkernel,

I think we should qualify an additional variant, maybe from Mouser or DigiKey, as a replacement to prevent additional issues like that in the future.

taintedkernel, 2023-12-18:
@jakkra It seems that order number helped them track the part down, so I've submitted my order and will see how it turns out.  And I certainly agree with you @Kampi that having another variant would be helpful and hopefully mitigate this.

Since I was able to get through this, should I close the issue?  Maybe open a new issue for the part variant idea?  Or keep this one open?

Kampi, 2023-12-18:
@taintedkernel I´ve created a ToDo for this issue, so you can close the the case.

https://github.com/users/jakkra/projects/2?pane=issue&itemId=47711312

The additional variant will be qualified during the work for rev 5 and I then we can add it to rev 4 too.

jamolnng, 2024-01-09:
> Thanks for the info. I passed along that order number to them and will await their reply. If they can no longer get it, then I'll go the route of ordering the connector with the display. I'm fairly confident I'll be able to solder it with an iron or hot air.
>
> I wonder if swapping to a different part might be necessary at some point? I don't have much experience sourcing connectors, but I've definitely seen similar ones in many devices I've disassembled - it does seem odd there isn't much luck with a match on DigiKey.

@taintedkernel were you able to get it sourced? I am having the same issue and am forwarding them that previous order number as well

taintedkernel, 2024-01-12:
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

I've had a lot of difficulty with them in general and I'm going the route of hand-soldering.  The agent I communicated with mentioned that it's possible for you to ship them the part and they can assemble it, if you want to go that route.

Closed 2023-12-18.

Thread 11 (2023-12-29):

Minor additions/corrections for PCBWAY assembly

taintedkernel, 2023-12-29:
Hello, I received 2 more questions from PCBWAY regarding assembly and wanted to drop a note here.

First, the BOM has a component marked as R10 listed, but I do not see it on the schematic or PCB - so I'm guessing it was from a previous revision. I told PCBWAY to skip this, let me know if that is incorrect.

And second, a few of the ICs did not have pin 1 marked so they asked me. I looked at the PCB and highlighted the correct pin from what I saw. Attaching a image they provided with my highlights; it looks to be ICs 9 12 14 and 15.

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

Kampi, 2023-12-30:
Hi @taintedkernel,

you should also miss `R6` in your BOM. The designators are wrong and `R10` is `R6`. Thanks for the correction.

You can see the pin 1 markings in `Ref_Top.pdf` in the `docs` folder.

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

taintedkernel, 2024-01-05:
Thank you @Kampi - they have not noticed this yet, but I will point it out.

They also pointed out for S1-S4 there is no solder mask opening for holes on top side and holes are covered with solder ink - they are asking if the holes are ok without opening pads on top, it can be reworked by them.  But if pads are necessary they would need a new order.

From what I see on the datasheet, they look to be through-hole and simply mechanical & not electrically connected, so I don't think pads would be necessary on the top?

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

Kampi, 2024-01-05:
Hi @taintedkernel,

you are right. The holes are only for mechanical stability. You can decide if you want a rework or not. I will adjust it in the footprint.

Btw. this is the first time I heard about this error. @jakkra do you had this issue already?

jakkra, 2024-01-05:
@taintedkernel @Kampi I have done 3 orders without any issue, they never noticed this. You can go ahead, for me pcbway have probably soldered manually the bottons through holes afterwards.

taintedkernel, 2024-01-12:
So I've heard back and they are saying the cause was due to a lack of a solder mask opening on the top side. The factory claims the holes are too small to rework and they suggest updating the design, then placing a new order.

Am I missing something? I used the files that are currently in the repo labeled 20231029 and it looks like there is an opening. At this point it's getting very frustrating dealing with PCBWAY and all of these problems.

Kampi, 2024-01-12:
@taintedkernel I´m sorry for this trouble. As @jakkra mentioned we hadn´t had this problem so far and we ordered ~20 or more PCBs there. I checked an empty PCB on my desk and it looks good and there is no soldermask on the holes.

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

From my point of view, we have the following options:

- They try to assemble the push buttons and remove the pin for the hole. This might cause some more pressure on the pads
- They ship the buttons unsoldered and you try it on your own
- You have to order new PCBs and I have to check how we can avoid this

What is your preferred way to go? You can also forward your e-mail conversation to me (kontakt@daniel-kampert.de) and I can try to talk with them to find a solution.

taintedkernel, 2024-01-12:
@Kampi I very much appreciate your (and @jakkra's) help on this and my frustration is definitely at PCBWAY!

From what I understand, it seems they have made an error somewhere in the manufacturing since your PCB doesn't have this issue and they were generated from the same source files.  I'm not sure I trust their job enough now for me to be able to fix whatever the issue is.

Assuming this is correct, I'd prefer them to fix their mistake and make a new set of PCBs.  Thank you for offering to jump into the conversation - I will go ahead with this route.

Kampi, 2024-01-12:
@taintedkernel I´m not sure if it´s 100% an issue of PCBWay alone. I´ve figured out that the pad of the switch has no solder mask on the bottom (masked out), but the hole has solder mask (not masked out). It looks like the solder mask goes into the via. I adjusted the footprint to fix this issue now. The question is why hasn´t it happened in the previous orders. Maybe they changed the mask or the process. A good indicator for this is this marked via.

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

Here you can see that this via is covered by a bit solder mask, but not total. So it looks like the process isn´t very clean because otherwise all holes must be covered in the same way ("wrong" data -> same result on every location). But we have different results.

We can try to argue in this way with PCBWay and see what happens.

Closed 2024-01-21.

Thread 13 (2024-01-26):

Add marking for display connector to prevent wrong orientation

Kampi, 2024-01-26:
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

Closed 2024-01-29.

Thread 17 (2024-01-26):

Replace light sensor footprint with the version from the library to prevent issues with the 3D model

Kampi, 2024-01-26:
Needed for #7

Closed 2024-01-26.

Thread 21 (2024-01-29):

Add WSON-8 flash memory

Kampi, 2024-01-29:
Option to use 64 MB flash

https://www.mouser.de/ProductDetail/Infineon-Technologies/S25FS512SAGNFI010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

Should fit

Closed 2024-01-29.

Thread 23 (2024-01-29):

Removing pull-up and pull-down resistors for vibration motor driver?

Kampi, 2024-01-29:
- Checked the datasheet but don´t find any need for them
- Checking with Jakob if we can move the resistors into the MCU

jakkra, 2024-01-29:
If I remember correctly I added this to make sure the motor was disabled when the voltage regulator removed power to the nRF, hence pin would float.

Looking a bit more into the nPM1300 I think we always should use `VBUSOUT` instead of VBAT (connected directly to battery). This way it will be impossible for any component to pull current after the nPM1300 under voltage hits.

So I think we should use VBUS-MCU (VBUSOUT) as input to the vibration motor.

jakkra, 2024-01-29:
Update this comment to say 50mA instead.
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

Kampi, 2024-01-30:
> Update this comment to say 50mA instead. ![image](https://private-user-images.githubusercontent.com/4318648/300636546-78a597b8-6134-45eb-b1b7-ca479c9b87af.png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)

Good point. 100 mA are related to the LOADSW feature.

jakkra, 2024-01-30:
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

Oops thought I was in the PR, too many tabs open...

Kampi, 2024-01-30:
@jakkra I close this. I moved your idea with VBAT into a separate issue and link the screenshot to the nPM1300 issue.

Closed 2024-01-30.

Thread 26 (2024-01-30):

Replace VBAT with VBUSOUT

Kampi, 2024-01-30:
If I remember correctly I added this to make sure the motor was disabled when the voltage regulator removed power to the nRF, hence pin would float.

Looking a bit more into the nPM1300 I think we always should use `VBUSOUT` instead of VBAT (connected directly to battery). This way it will be impossible for any component to pull current after the nPM1300 under voltage hits.

So I think we should use VBUS-MCU (VBUSOUT) as input to the vibration motor instead of VBAT.

`VBAT` should never be used, and I searched the schematics and ot's only being used for vibration motor, so we are fine except that I think.

_Originally posted by @jakkra in https://github.com/jakkra/ZSWatch-HW/issues/23#issuecomment-1915678082_

Closed 2024-01-30.

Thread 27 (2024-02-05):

Fix broken documentation

Kampi, 2024-02-05:
- 3D model for nPM1300
- 3D model for flash memory
- Broken badge link in README
- Missing doc connector image in README

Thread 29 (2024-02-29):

3D file

DREAM669, 2024-02-29:
Hi,@jakkra
I have found button.inner.stl and button.inner.angled.stl in your CAD file. May I ask if there is any difference between these two?

WenchongWang, 2024-02-29:
这是来自QQ邮箱的假期自动回复邮件。邮件已经收到，我会尽快回复您。

jakkra, 2024-02-29:
Here it's marked which ones are the angles ones https://github.com/jakkra/ZSWatch/wiki/Case,-3D-printing-and-assembling#buttons

DREAM669, 2024-02-29:
Okay, I understand. Is there any difference between these two sizes?

jakkra, 2024-02-29:
@DREAM669 Yes you need two of each and they need to sit at the location specified in this image:
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

DREAM669, 2024-03-04:
@jakkra ,Hi,Can you use a vernier caliper to measure the thickness of the battery and let me know?

jakkra, 2024-03-04:
> @jakkra ,Hi,Can you use a vernier caliper to measure the thickness of the battery and let me know?

3.7mm

DREAM669, 2024-03-05:
Hi,@jakkra
May I ask what material is used for 3D printed watches on your end? What kind of glue is used to stick the buttons? I'm worried that paying taxes may not be able to stick it firmly. Thank you for your reply!

jakkra, 2024-03-05:
> Hi,@jakkra May I ask what material is used for 3D printed watches ? What kind of glue is used to stick the buttons? I'm worried that paying taxes may not be able to stick it firmly. Thank you for your reply!

I have used PLA. For the buttons the outer cap is optional, so you can skip gluing it alos. But for those I use super glue, for example: https://www.loctiteproducts.com/en/products/fix/super-glue/loctite_super_gluelongneckbottle.html

DREAM669, 2024-03-05:
Do you mean to use the one inside directly? Will it not move without an outer cover, and even fall into the watch?

Closed 2024-03-16.

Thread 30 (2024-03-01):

Mounting frame for second PCB side

Kampi, 2024-03-01:
**Idea**

3D printed frame to provide some additional height during the PCB assembling. The PCB will placed upside down (with the components) into the frame and then you can add the stencil on the second side (or solder manually). After assembling you can put the PCB into an oven or use a hot air gun to solder the second side.

blubbsy, 2024-10-12:
do i get the idea right?

you want to have the negative of one soldered PCB-Side 3d printed to use it as a base to solder more comfortable the other side?

Kampi, 2024-10-12:
Not exactly. A simple frame where you can put in the PC is enough

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

blubbsy, 2024-10-13:
so basically it is a frame with PCB outline + little more for a border?
just thinking if this is something that can be automatized somehow with FreeCAD, but in general sounds like a ~5 minute CAD work.

Kampi, 2024-10-13:
Yep, it's not much work

blubbsy, 2024-10-13:
Like this?
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

Only have to add maybe an additional offset to not have a tight fit of the PCB in it. Put 1mm offset below the PCB and 1mm for the outer ring. Dont think that much of more is necessary for what i understood you would like to have this. I would keep it that way and if we notice that it is not really stable on a table surface, we simply change the base to have 3 or 5 legs.

(Havent done it with FreeCAD, FreeCAD killed me trying to re-use the PCB geometry...)

[Halterung.zip](https://github.com/user-attachments/files/17356405/Halterung.zip)

Kampi, 2024-10-13:
Yeah - but I would like to have some plateau to mount the SMD stencil. You put the stencil on the PCB, adjust it with tape on the frame, add the solder paste, flip the stencil upwards, and remove the PCB. So you have to make sure that the PCB isn´t mounted that tight and maybe add a hole on the side to remove the PCB with the paste and the components from the frame.

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

blubbsy, 2024-10-14:
This way or do you prefer to have some contact points outside the PCB-Outline?

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

The "plateau" is 5mm in the screenshot to actually be able to move the stencil (the transparent piece) a little bit and added a cut-out (5*5mm) to make life easier to lift the PCB again out of the holder.

Was thinking to actually use the big through holes as positioning help, but then i though that maybe a FDM 3d printer would have some difficulties to make them properly and would rather prefer that the printer simply does the outline nicely.

WenchongWang, 2025-02-11:
这是来自QQ邮箱的假期自动回复邮件。邮件已经收到，我会尽快回复您。

Closed 2025-02-11.

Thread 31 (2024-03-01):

Bring back the heart rate sensor

Kampi, 2024-03-01:
- [MAXM86161EFD+T](https://www.mouser.de/ProductDetail/Analog-Devices-Maxim-Integrated/MAXM86161EFD%2bT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)
- [MAX32664GTGC+](https://www.mouser.de/ProductDetail/Analog-Devices-Maxim-Integrated/MAX32664GTGC%2b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)
- Normal PCB with flex cable (i. e. https://www.amazon.de/Aexit-Steckverbinder-f%C3%BCr-St%C3%BCck-Bottom/dp/B07C96ZNF2)
- Or flex PCB with integrated cable?

blubbsy, 2024-10-22:
if using the MAX3266...-Hub, shouldnt the accelerotmeter then also a accelerometer being connected to it as it is recommended in the datasheet?

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

here they mention the ROHM KX-11, but also the Bosch BMI323 and LIS2DS12 appear to be possible (I found examples with the old BMI160), but i wonder if the available BMI270 could be used for it.

Actually it hough maybe the MAX86174A could be an option as a HR-Sensor, because it has much more features, but i think it will get much more complicated (and bigger) to do this.

Kampi, 2024-10-22:
AFAIK it´s possible to use an external Acc and send the data to the sensor hub. Jakob or I have looked it up. But the whole HR concept isn´t final yet. It´s more a collection of ideas and depending on the date when we start with the integration we can rethink the component selection and maybe use the bigger one and maybe also a second Acc. Currently I would prefer the LIS2DS12 because of the price :)

jakkra, 2024-10-22:
> AFAIK it´s possible to use an external Acc and send the data to the sensor hub. Jakob or I have looked it up. But the whole HR concept isn´t final yet. It´s more a collection of ideas and depending on the date when we start with the integration we can rethink the component selection and maybe use the bigger one and maybe also a second Acc. Currently I would prefer the LIS2DS12 because of the price :)

You can feed it external Accelerometer data, I looked it up a while ago. So no Accelerometer directly connected needed.

blubbsy, 2024-10-22:
i would rather try to avoid having 2 acc :) i tried to understand in 15 minutes a little bit of how the stuff works, but well... not that easy. i think rohm also has some HR sensors, but what you selected seemed to me much better/easier.

> You can feed it external Accelerometer data, I looked it up a while ago. So no Accelerometer directly connected needed.
perfect!

What was the idea behind the FlexPCB? To position the LEDs/Sensor on the right height next to the charger/programmer-interface?
I quickly added it to the assembly and measured the height difference between these two and maybe it is sufficient to put it on a 2nd PCB for the right height? would just require few solder pads and make the assembly easier.

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

Kampi, 2024-10-22:
@blubbsy I accidentally edit your message instead of writing a new -.-

> What was the idea behind the FlexPCB? To position the LEDs/Sensor on the right height next to the charger/programmer-interface?

We have to position the HR sensor so he can touch the skin. The current setup is a PCB with a dock connector. The dock connector adds 10 (?) millimeters of height between the skin and the PCB bottom side. So we have the option to shrink down the dock connector or add a second PCB to handle the distance. The first idea was to use a flex PCB. The current (and latest) idea is to add a second PCB and use small PCB connectors to attach it to the mainboard.

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

blubbsy, 2024-10-22:
okay, this works too. i dislike connectors, because i got educated at work that connectors are expensive ;)

yeah, this could owrk too for the few cents, but then the HR has to be well positioned, so that it does not make any force on the connector or looses contact. And thinking about how to protect against sweat. Nothing that cannot be solved.

Though i liked my idea and the Bottom is basically empty.

is the plan to have 1 or multiple of the HR sensors integrated?

Kampi, 2024-10-22:
The plan is to add one HR sensor only. And I think we must use two connectors to add more stability into the construction. The connectors are cheap and for now it's the best solution because we also need a small height. But anyway we had to brainstorm the idea as soon as we continue the work on it. It's paused for now.

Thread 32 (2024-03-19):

holes for the motor

DREAM669, 2024-03-19:
@jakkra ,Hello, is it necessary to leave holes for the motor on the PCB board?
If the wire passes through the back of the hole without leaving any space for the wire, right?

jakkra, 2024-03-19:
Not sure what you mean, have you looked here https://github.com/jakkra/ZSWatch/wiki/Case,-3D-printing-and-assembling#preparing-the-pcb

DREAM669, 2024-03-20:
@jakkra ，I would like to ask you what is the difference between inner_holder_support and inner_holder_no_support?

Closed 2024-03-28.

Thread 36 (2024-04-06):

Testing V2.0.5

Kampi, 2024-04-06:
- [x] USB with new dock
- [x] SWD with Dock rev 3
- [x] SWD with Dock <rev 3
- [x] Microphone
- [x] Speaker
- [x] nPM1300 power supply
- [x] nPM1300 system reset
- [x] Flash memory
- [x] Bridge to disable USB Switch IC

Kampi, 2024-04-06:
Regular 64 Flash memory doesn't work because wrong component with wrong sector size. A 32 MB Flash with the right sector size is working. 64 MB will be testet next.

jakkra, 2024-04-07:
Buzzer OK

jakkra, 2024-04-07:
nPM System Reset OK

jakkra, 2024-07-16:
Done all working

Closed 2024-07-16.

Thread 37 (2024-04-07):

Add option for LED instead of buzzer for sensor board

Kampi, 2024-04-07:
Additional assembly variant with 0805 LED. Use the LED instead of the flyback diode for the buzzer

I. e.
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

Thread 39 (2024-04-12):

Support for JLCPCB

Kampi, 2024-04-12:
Add production files in JLCPCB format to Kibot

- [ ] BOM
- [ ] Pick&Place

Kampi, 2024-04-14:
Not all parts available for assembly.

Closed 2024-04-14.

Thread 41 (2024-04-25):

Remove pull-up for SEL pin

Kampi, 2024-04-25:
This pull up is powering the USB switch over SEL from the dock and it's not needed. Set it to NA for the start.
@jakkra is testing this modification to make sure everything is working as expected.

WenchongWang, 2024-05-23:
这是来自QQ邮箱的假期自动回复邮件。邮件已经收到，我会尽快回复您。

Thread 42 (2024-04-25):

Separate power supply for the USB switch

Kampi, 2024-04-25:
Don't use the PMIC to power the USB switch any longer. Instead use either a voltage divider or a Z-diode connected to VBUS to power the switch.

Check the current consumption of the switch first.

Closed 2024-04-26.

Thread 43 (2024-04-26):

Different modifications for USB

Kampi, 2024-04-26:
- Add `CONFIG` option for USB switch IC
- Update comment (USB switch can be bridged by closing the jumper and leave out the voltage divider for power supply. Also the reset resistor must be added)

Closed 2024-05-04.

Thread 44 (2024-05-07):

Add RV-8263-C8

Kampi, 2024-05-07:
- Needed for Alarm API stuff
- [Mouser](https://www.mouser.de/ProductDetail/Micro-Crystal/RV-8263-C8-32.768kHz-20PPM-TA-QA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)
- Place above the NORA module and use the SCL from nPM
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
- Voltage directly from battery

Closed 2024-05-07.

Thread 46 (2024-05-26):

Remove jumper from BOM and match Layer names in gerbers with KiCad

jakkra, 2024-05-26:
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

Different names
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

Kampi, 2024-05-27:
Are you speaking about the innter layers? The rest looks imo okay

Kampi, 2024-05-27:
@jakkra please check it

jakkra, 2024-05-27:
> @jakkra please check it

Layers still have different names, exported gerbers say "ZSWatch-F_Cu.gbr"

BOM is OK

Kampi, 2024-05-27:
@jakkra I prefer the project name in the Gerber files to identify them easily in case I have to check them manually. So I would leave the prefix as it is.

jakkra, 2024-05-27:
Great

Closed 2024-05-27.

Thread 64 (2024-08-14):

Rework sharing of PCB specifications

Kampi, 2024-08-14:
Screenshots are outdated.

WenchongWang, 2024-08-14:
这是来自QQ邮箱的假期自动回复邮件。邮件已经收到，我会尽快回复您。

Closed 2025-06-23.

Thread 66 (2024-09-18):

NORA-B10 or NORA-B12

blubbsy, 2024-09-18:
Hi,

is there a reason why not using the NORA-B12 with Bluetooth v5.3 instead of 5.2? As far as i see the price are the same (actually on mouser the B12 is 40 cent cheaper). 5.3 should use less energy, which would benefit the Watch.

The only reason why not using the B12 is that they are running with a max. Voltage of 3.6V instead of 5.5, but as most other ICs are running on 3.6V i don't see the problem.

this is just on first sight, without checking if on SW side the registers changed or whatever... still trying to find some time to take a look on the schematics :/

WenchongWang, 2024-09-18:
这是来自QQ邮箱的假期自动回复邮件。邮件已经收到，我会尽快回复您。

jakkra, 2024-09-18:
Actually it's the same chip and the Bluetooth version can be ignored as it's the same HW, could be just documentation issue. Anyway there is no power consumption difference in v5.2 vs v5.3. The real difference is actually that NORA-B12 have an internal PA (to amplify TX power), but this uses some pins from the nRF5340 which may limit us as we may want those pins.

Closed 2024-09-18.

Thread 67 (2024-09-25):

New vibration motor

Kampi, 2024-09-25:
- [VZ30C1T8219732L](https://www.vybronics.com/erm-cylindrical-vibration-motors/smd/v-z30c1t8219732l)
- Available at [Digikey](https://www.digikey.de/de/products/detail/vybronics-inc/VZ30C1T8219732L/15220804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)

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

Kampi, 2024-09-25:
@jakkra we must check if the height can be an issue, This is an ERM motor so it should work with our driver.

Kampi, 2024-11-03:
The motor needs 3.2 V max. We can use the regulator from the nPM for that.

Kampi, 2025-05-02:
Will be reworked in rev 3

WenchongWang, 2025-05-02:
这是来自QQ邮箱的假期自动回复邮件。邮件已经收到，我会尽快回复您。

Closed 2025-05-02.

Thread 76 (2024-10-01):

DRC Check (PCBWay)

blubbsy, 2024-10-01:
Hi,

Were any design rules imported from PCBWay? (Source DRC-File: https://www.pcbway.com/pcb_prototype/PCB_Design_Rule_Check.html; Source Written: https://www.pcbway.com/capabilities.html)
I imported these infomration and i get some errors (in total 411) , here some examples:

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

I mean the differences are not that big and probably not very severe, but still it is probably not the best to violate the recommendation of the manufacturer. Probably most of these can be easily fixed and i would actually thinking of doing it the next few days/weeks. As probably half of these are the via hole sizes, thats not difficult to fix and many clearance errors can be fixed by moving the vias sligthly (not the ones right below the ICs). **Still i have to check if the DRC-File from PCBWay fits to their capabilities!**

I'm not sure if the minimum trace width should be fixed at all, because probably most will throw a DRC error anyway, because they have to be narrowed for the in-between tracing.

@Kampi offtopic question: is it okay for you if we write in german? ;)

LG
Adrian

Kampi, 2024-10-01:
Hi @blubbsy,

let´s use English please if someone else has the same question :)

I don´t use the values from the PCB design rule check page. Instead, I use the values from the PCB Capabilities ([here](https://www.pcbway.com/capabilities.html)).

I´m not sure where the values from PCB come from. You can compare both values here (the bottom is ours)

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

- uVias doesn´t care
- Hole size is set to the value from the configuration mask (0.25 is the smallest hole without switching to "Advanced")
- Min. spacing is also taken from the configuration mask (5 mil is the smallest without switching to "Advanced")
- Via diameter is calculated from 0.25 hole size + 0.15 mm annular ring from the capabilities page (plus 0.05 mm extra)
- Restring is the same in both
- Spacing is set to 0.15 mm (6 mil) to not switch to "Advanced"

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

Kampi, 2024-10-01:
Btw. you can check the PCBWay screenshot in the `production` directory from the CI/CD pipeline for the settings. We order the PCBs with these settings every time and they pass the check most of the time. PCBWay is complaining sometimes about the footprint of a sensor. But this is the recommended footprint from the manufacturer so it´s fine.

blubbsy, 2024-10-02:
> By the way, you can check the PCBWay screenshot in the production directory from the CI/CD pipeline for the settings.

True! totally forgot about this, when i checked it yesterday 🤦

I uploaded it to PCBWAy and there werent any complains at all, except about one solder mask bridge, which.... well... i dont care much:
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

Are you using the PCBA service of PCBWay or are you soldering everything on your own? i'm thinking to order some PCBs and still checking if i want to assembly everything on my own or try out PCBWays service. Depends how lazy i'm...

Kampi, 2024-10-02:
This IC is always critical but the footprint is the recommended footprint from the manufacturer. So you have a distance of 0.18 but you need 0.19. So it´s not a big deal.

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

We use the PCBA service from PCBWay all the time and we don´t have any issues with this IC AFAIK. And we order the PCBs in blue or greeen so we can use the 0.19 mm distance.

Anyways the solder mask bridge is basically solder mask between two pads from the IC. It´s not important to have solder mask between this pins if your soldering process is good because the mask stops the solder paste bridging two pins

blubbsy, 2024-10-06:
so here a summary:

### Cosmetics
So most of the differences are cosmetic or because of the unit systems, see here the more cosmetic differences:

| Name                               | ZSWatch   | PCBWay                | Severity | Comment                       |
|------------------------------------|-----------|-----------------------|----------|-------------------------------|
| Solder Mask minimum web width      | 0 [mm]    | 0.1016 [mm] / 4 [mil] | low      |                               |
| Text: Silk Layer Thickness         | 0.12 [mm] | 0.15                  | low      | Worst case: text is not nice. |
| Text: Copper Layers Text Width     | 0.8 [mm]  | 1 [mm]                | low      | Worst Case: text is not nice. |
| Text: Copper Layers Text Height    | 0.8 [mm]  | 1 [mm]                | low      | Worst Case: text is not nice. |
| Text: Copper Layers Text Thickness | 0.12 [mm] | 1 [mm]                | low      | Worst Case: text is not nice. |
| Text: Fab Layers Text Width        | see above | see above             | low      |                               |
| Text: Fab Layers Text Height       | see above | see above             | low      |                               |
| Text: Layers Text Thickness        | see above | see above             | low      |                               |

### Vias
But what i found is that it would be possible to reduce the via sizes actually, because the min. drill size that PCBWay still puts as "normal" would be 0.2mm instead of 0.25mm. This could maybe help a little bit with routing on this narrow space, though i dont understand why in their KiCAD setup they are also setting 0.254mm:

| Name                          | ZSWatch | PCBWay | Severity | Comment |
|-------------------------------|---------|--------|----------|---------|
| Track Width                   | 0.2  [mm]   | 0.1524 [mm] |          |         |
| Clearance                     | 0.125 [mm]  | 0.15 [mm]  |          |         |
| Via Size                      | 0.45 [mm]   | 0.452 [mm] |          |         |
| Via Hole                      | 0.25 [mm]   | 0.254 [mm] |          |         |
| Differential pair track width | 0.2 [mm]    | 0.1524 [mm] |          |         |
| Differential pair track gap   | 0.25 [mm]   | 0.1524 [mm] |          |         |

### Custom DRCs

What i also curious is that PCBWay actually uses some custom DRC rules in their example and if i understand this correctly (never used these) **they reduce the track width and clearance to 0.09**. which is maybe also not that bad to know. :

``(version 1)
#PCBWay Custom DRC for Kicad 7

# ----------------------------------- Minimum trace width and spacing (PICK ONE) --------------------

# 2oz copper
#(rule "Minimum Trace Width and Spacing (outer layer)"
#(constraint track_width (min 0.1524mm))
#(constraint clearance (min 0.1778mm))
#(layer outer)
#(condition "A.Type == 'track'"))

#(rule "Minimum Trace Width and Spacing (innner layer)"
#(constraint track_width (min 0.1524mm))
#(constraint clearance (min 0.1778mm))
#(layer inner)
#(condition "A.Type == 'track'"))

# 2-layer, 1oz copper
(rule "Minimum Trace Width and Spacing (outer layer)"
(constraint track_width (min 0.127mm))
(constraint clearance (min 0.127mm))
(layer outer)
(condition "A.Type == 'track'"))

(rule "Minimum Trace Width and Spacing (inner layer)"
(constraint track_width (min 0.1mm))
(constraint clearance (min 0.1mm))
(layer inner)
(condition "A.Type == 'track'"))

# 4-layer , 1oz and 0.5oz copper
#(rule "Minimum Trace Width and Spacing (outer layer)"
#(constraint track_width (min 0.09mm))
#(constraint clearance (min 0.09mm))
#(layer outer)
#(condition "A.Type == 'track'"))

#(rule "Minimum Trace Width and Spacing (inner layer)"
#(constraint track_width (min 0.1mm))
#(constraint clearance (min 0.09mm))
#(layer inner)
#(condition "A.Type == 'track'"))

# ------------------------------------------------------------------------------------------------------
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
Kampi, 2024-10-06:
The definitions for the pad stacks are provided by PCBway too. AFAIK we don't had any issues with the total height. We order the PCB as 1 mm board and the height will normally differ by something like 0.1 mm.

blubbsy, 2024-10-06:
> The clearance topic is a bit odd because PCBWay says they can produce 0.1 mm with the normal process but they recommend 0.15 mm. So we use the middle of both :)

i also havent understood why the clearance should differ between a 2 and 4 layer PCB. As fasr as I know the process steps are the same, just putting more layers on top.

> I guess PCBWay hasn't updated their design rules for KiCad. So maybe they are outdated. I guess the rules will fit for the most projects and if they don't fit the people will be experienced enough to adjust it.

I was thinking about this too, but they were done for KiCAD 7, which was release february 2023, so it cant be that outdated at all. And following to the date of this article https://www.pcbway.com/helpcenter/design_instruction/PCBWay_Custom_Design_Rules.html the data is from May 2024. I learned through this how to use the custom DRCs, never looked at it, never though about it. quite cool actually.
I will just write them and ask :)

Kampi, 2024-10-06:
>
> i also havent understood why the clearance should differ between a 2 and 4 layer PCB. As fasr as I know the process steps are the same, just putting more layers on top.
>

Maybe they use a different machine for 4-layer PCBs. It´s quite common for manufacturers to have different machines for PCBs.

> I was thinking about this too, but they were done for KiCAD 7, which was release february 2023, so it cant be that outdated at all. And following to the date of this article https://www.pcbway.com/helpcenter/design_instruction/PCBWay_Custom_Design_Rules.html the data is from May 2024. I learned through this how to use the custom DRCs, never looked at it, never though about it. quite cool actually. I will just write them and ask :)

Let me know what the answer was :)

blubbsy, 2024-10-07:
basically they just referred me to: https://www.pcbway.com/multi-layer-laminated-structure.html, though that the information is not consistent, because following to their website, the L1 and L4 copper planes are 0.0175mm thick, instead of 0.035 (which you have in the PCB and what they put in their DRC template):
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

I'm actually not sure if they look at it at the end or when selecting 4 layers and 1mm thickness, automatically leads to the stackup.

i played with the pcbway cost calculator and i think it is possible to reduce the via hole size from 0.25mm to 0.2mm, without additional cost (at least it does not increase for me). **As you have still plenty of space on the PCB it does not help much, but maybe in case it is planned or necessary to be more compact it helps. Should i commit the change (0.2 hole + 0.15mm via diameter == 0.35)?**

The track width could be reduced to 4mil on the inner layers (i assume that normal process does not increase the price):
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
but i think the DRC checks do not differ between outer and inner layers in KiCAD. SFor the sake of simplicity and to have the proper checks i would not touch this at all.

Kampi, 2024-10-22:
@blubbsy is this issue solved?

blubbsy, 2024-10-22:
i think yes. i will just one day create a PR with the corrected stackup values from PCBway and then it is up to you to accept it or not. it's just changing few values.

To Summerize:

* Plane thicknesses adapting to pcbway values (i think worst case it influences just the step export).
* Changing to smaller vias. i dont think you will change the vias if not necessary, but when it may be necessary nothing starts to cry.
* WONT change Inner trace width to 4mil, because i dont know how to define it in KiCAD.

blubbsy, 2024-10-22:
i mean i reduced it and added the via size, but i dont see the necessity to update them all if there is no need for it (at the moment). i hadnt the feeling that you lack of space on the PCB.

i mean i just quickly changed all the vias, refilled the areas and uploaded it to pcbway and the price did not change at all. So the information on their capability-site seems to outdated? Okay, they also say via sizes should be the same, which i think is just wrong.

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

the price estimation does not change at all. so from my point of view this is then OK.

Closed 2025-05-05.

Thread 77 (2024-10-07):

External KiCAD Library

blubbsy, 2024-10-07:
Hi,

you built this really amazing library for your purposes ! cant imagine how much work this actually is to maintain (1GB?!).
but what i wonder if for the projects this is the right approach? shouldnt ZSWatch-HW use it's own project specific library instead of your universal one? I understand why you do it, because it is a lot of work to maintain it.
i would maybe dedicate some time to check if i could write a script (a quite dumb though and i have to check how to do it) that automatically extracts the relevant components from your library to a project library.

At the same time i would check if there are some other components that could need an update of the paths, because i saw that the LIS2MDLTR is actually still referring to the KiCAD6 path. Dont know why it actually works, because i have a clear kicad installation and kicad6 is not in the paths anymore, but okay...

This is cosmetics, so definitely nothing i want to bother you much. Personally i just downloaded your library and added the path to KiCAD...

BR
Adrian

Kampi, 2024-10-08:
Hi Adrian,
I also thought about it last week because it makes versioning easier and may avoid some issues, e.g., fetching a specific commit of the watch hardware and using the latest library version, which changes some footprints. This can lead to potential bugs in the hw when a user updates the footprints. Feel free to extract the specific parts and copy them in a' library directory in the project root. Then you can add them as project-specific components and add them to Git. Next, you have to change the CI/CD pipeline.

blubbsy, 2024-10-08:
> I also thought about it last week because it makes versioning easier and may avoid some issues
totally true, don't know why i haven't though about it. Also it is then possible to make releases, that fit together with the SW part.
Do you want to detach it entirely from your library and maintain a specific library? my idea would have been to write a python script that copies from your library the used components and copies them into the ZSWatch-Project/library folder.

to your ToDo list: sounds good! Dont know when i will do it, because i'm travelling for work to Munich tomorrow. But i will try my best ;-)

> Discuss if we want to do it for all parts (also, the KiCad parts) or the custom parts only. Doing the same with the KiCad parts might avoid issues when upgrading KiCad

Why the KiCAD parts? i think these are only standard packages (diodes, capacitors, resistors etc.) and i wouldn't expect any changes. If i'm not mistaken these are actually generated through a python script.

Kampi, 2024-10-08:
Take your time. We are not in a rush with this topic :)

Why the KiCad parts:
Only for completion (I. e. when modifing a resistor to remove the silkscreen). We can use the way that we do not change standard components and if we do they should be placed in the library or we copy all components and we add the standard components that currently exist in the layout and then you can change them later on.

Kampi, 2024-10-22:
@blubbsy we must check how we rebase your changes to my 2.0.6 branch. I suggest we try it with [CadLab](https://cadlab.io/) as soon as you have finished your work. It´s also a good check for a new workflow to improve the work as a team on KiCad projects.

blubbsy, 2024-10-22:
> we must check how we rebase your changes to my 2.0.6 branch.

no idea 🤦

> I suggest we try it with [CadLab](https://cadlab.io/) as soon as you have finished your work.

just created already the account for it. Actually mostly the proper check if still everything is correct is the main issue, so CadLab is exactly the right solution for it.

Closed 2025-01-02.

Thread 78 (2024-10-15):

Add pin orientation to iBOM

Kampi, 2024-10-15:
Add missing `F_Fab` layer

Closed 2025-05-25.

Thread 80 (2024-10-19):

Understanding need for 3V3/VDD-Display

blubbsy, 2024-10-19:
Hi,

What is the reason to supply the display with 3.3V instead of 3.0V? If i understand the datasheet of the display correctly, then the typical supply should be 2.8V for the supply and 3.0V for the backlight.

i summed up all the currents from the sensors, mcu, flash etc. and i calculated a total peak current of 75mA (rounded up), while the output could handle 200mA. In normal operating the value should be much smaller, because it is already with flash writing, full display, vibration motor, MCU transmitting etc.

The reason why I looked at it is, that i think the power supply would be more efficient when only using the 3V instead off additionally using the 3V3 from the LDO1. I first though the LDO1 is used for some software control over the display, but then i saw the backlight driver that actually does it...

Am I missing something or is there a SW reason to use the LDO1?

BR
Adrian

Kampi, 2024-10-19:
I guess it´s a relict from the previous versions. I haven´t checked it in the past. The separate power supply has the advantage of cutting off the display power completely. If we use one power supply for all we can not turn off the display, instead it´s only possible to reduce the backlight.

Maybe we can use the load switch for it?

@jakkra what was the reason for using 3V3 for the display? Do you know it?

blubbsy, 2024-10-19:
I think i know from where this comes. The datasheet of the display itself does not say anywhere 3.3V as recommended supply voltage, neither does the controller Datasheet (https://files.waveshare.com/upload/5/5e/GC9A01A.pdf) say it. but at many places in the web 3.3V are stated as nominal supply voltage, which i cant really follow why this is the case:

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

> If we use one power supply for all we can not turn off the display, instead it´s only possible to reduce the backlight.
this is what i also though, but now that i scrolled through the controller datasheet:
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

> Maybe we can use the load switch for it?

Something to make you laught:
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

Kampi, 2024-10-19:
Okay, so removing the backlight supply doesn´t work. If @jakkra hasn´t any argument against it I would suggest this as an idea for Rev 2.6 (at least for testing).

jakkra, 2024-10-19:
Reason it's at 3V3 is that I just picked it as I consider it a common voltage and within the range. Before the nPM1300 there was less flexibility for voltage levels. With v5 we got requirement to have 3V0, and I think we never thought of changing display VBUS to 3V0 also. BUT it's very good to have display on a seperate power supply as it pulls quite a bit of power even in sleep mode (perhaps putting in reset is ok, never tried) so it's simple to just cut the power and touch and display are consuming 0.

blubbsy, 2024-10-19:
> BUT it's very good to have display on a seperate power supply as it pulls quite a bit of power even in sleep mode (perhaps putting in reset is ok, never tried)

Yes, but if the nPM1300 can provide so much more I don't see any problem. And a switch can be also located on the 3V line exclusively the display if necessary.

Ultimately maybe it can be tested how much the display consumes in sleep to see if it is worth? I expect the buck to be more efficient than the LDO1, but has to be checked.

> Okay, so removing the backlight supply doesn´t work.

I think they are overdramatic 😅

Kampi, 2024-10-20:
Probably we can use an additional pnp transistor to switch the LCD and use own power supply for all?

blubbsy, 2024-10-20:
Someone had to stand up early today ;)

You mean something like this?
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
The PNP would need to have a lower voltage drop than the LDO (200mOhm), otherwise it would not save energy at all.

i'm not sure if this somehow benefits us at all. I mean: is the PNP more efficient than using the nPM1300 LDOs? In a nutshell the discussion is about how to make it more energy saving right?

Initially i only though that the Buck would be more efficient than the LDO. And well, slightly the board layout would be more simply as you have to route one trace less.

Maybe it is something to postpone and simpyl keeping it in mind for future ideas/optimizations, until some question are answered regarding the energy consumption. If we realize that it is okay to use only the 3V also for the display, we could check if it makes sense to change the sensors to 3V (or whatever voltage level makes sense. they are all already rated for >3V) too and use a smaller PMIC (e.g. nPM1100 --> ~30% cheaper / 2€) as the additional voltage level wouldnt be needed anymore.

Kampi, 2024-10-20:
A DC/DC converter is always more efficient than an LDO because of the way the energy is converted. The LDO converts a voltage difference into heat so we use the LDO to generate 3.3 V out of 4.2 V we waste 0.9 V * 75 mA (just a random value as display power) 0.0675 W. If we use the 3 V from the DC/DC we don´t have this issue but we have the problem that the display can not be disabled alone because all peripherals are powered by 3 V. This is where the PNP comes into play. With this PNP as a simple switch we can turn on and off the display. Using a `DMG1013UW-7` (like for the microphone) means an additional 1.5 Ohms resistor (worst case) which means 1.5 Ohms * (75 mA)^2 or 0,0084375 W = 12.5 % in comparison to the LDO.

The next advantage would be that the watch can be used a bit longer because currently, the display doesn´t work at a battery voltage less than 3.3 V (VOut LDO) + 40 mV (Droput of the LDO).

The reason why we switch from the LDOs to the nPM is the optimized bundle of MCU and PMIC together with an optimized battery charging and a more efficient power supply (DC/DC instead of LDO). The nPM1100 is IMO not an option because we want to use the ship mode of the nPM1300 to shutdown the watch when not needed and the "real" hardware reset of the nPM1300 ist also a big bonus

jakkra, 2024-10-20:
IMO we can keep this in mind for future revision, but not worth doing now current setup is fine and power consumption wise, shoving off a few uA doesn't do much if you use the watch regularly anyway. I however think the features of nPM1300 are not something I want to trade away also.

Kampi, 2024-10-20:
@blubbsy feel free to add this idea as a ticket for rev 2.6 or later :)

There is a lot to do with the current revision (like reducing the current consumption :P).

blubbsy, 2024-10-20:
> I however think the features of nPM1300 are not something I want to trade away also.

Totally legit point. As I dont know the SW side so far, i have no idea which features are being used at all or what capabilites the different nPMxxxx have.

> @blubbsy feel free to add this idea as a ticket for rev 2.6 or later :)

I cant move/edit this ticket to add it to the milestone. i would like to keep the discussion for documental reasons when someone is starting to work on it.  Who knows when this is being worked on or if other things change (new sensors, displays etc.), but as we had good clarifactions here it would be a shame to have it distributed through multiple discussions.
A new issue would be possible to be assigned to the milestone by me 🤷‍♂️.

Kampi, 2024-10-20:
I can edit it later

Closed 2025-04-08.

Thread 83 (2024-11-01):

Automatic diff generation between main and feature branch when pushing to a branch?

Kampi, 2024-11-01:
I think it`s useful to generate a diff between main and branch when someone pushes stuff to a feature branch to compare the differences. This can be done with KiDiff:

https://github.com/INTI-CMNB/KiDiff

My idea is to build a CI/CD that generates a diff output on every push to a feature branch. It wouldn´t cover KiCad settings, but I think settings can be merged more easily than schematic and layout conflicts.

A simple command can look like this:

```
kicad-diff.py original/project/ZSWatch.kicad_pcb modified/project/ZSWatch.kicad_pcb --all_pages --output_dir Result --no_reader --resolution 500
```

With a PDF result or images

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
[diff.pdf](https://github.com/user-attachments/files/17600641/diff.pdf)

Closed 2024-11-05.

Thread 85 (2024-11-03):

BOSCH footprint is missing in library and move the library settings to 2.0.6 branch

Kampi, 2024-11-03:
- Remove library from CI/CD
- Check symbol and footprint paths

Closed 2024-12-31.

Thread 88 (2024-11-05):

Generated render of PCB wrong after library changes

jakkra, 2024-11-05:
Components missing. Ci needs update.
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

Guess something needs to be updated here https://github.com/jakkra/ZSWatch-HW/blob/main/project/zswatch.kibot.yaml

Kampi, 2024-11-07:
The issue is fixed in [here](https://github.com/Kampi/ZSWatch-HW/tree/2.0.6_Dev)

Kampi, 2024-11-07:
Fixed in [2.0.6_Dev](https://github.com/Kampi/ZSWatch-HW/tree/2.0.6_Dev)

https://github.com/Kampi/ZSWatch-HW/actions/runs/11730072439

Kampi, 2024-11-07:
Fixed in 2.0.6_Dev

Closed 2024-11-07.

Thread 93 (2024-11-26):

Make sure to adjust/remove soldermask on all places space between pins are less than 0.2mm

jakkra, 2024-11-26:
PCBWay often ask if it's okey to go ahead removing it, we should do that ourselves in order to not need that extra step every time.
Example:
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

Closed 2025-05-05.

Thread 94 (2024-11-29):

pcbway issue

ravi145258, 2024-11-29:
pcbway opening showing issue for purchasing pcb

jakkra, 2024-11-29:
Not enough information.

ravi145258, 2024-11-29:
https://www.pcbway.com/project/shareproject/ZSWatch_Open_Source_Smartwatch_4ca3bcf6.html
this getting error please share where to purchase pcb

jakkra, 2024-11-29:
> https://www.pcbway.com/project/shareproject/ZSWatch_Open_Source_Smartwatch_4ca3bcf6.html this getting error please share where to purchase pcb

It's been removed temporarily as a new version (v5) will soon be uploaded to PCBWay. So I suggest waiting for that.

ravi145258, 2024-11-29:
thank your verymuch jakkra is there any option to change pcb layout to square like apple watch

jakkra, 2024-11-29:
> thank your verymuch jakkra is there any option to change pcb layout to square like apple watch

If you know KiCad you can do whatever, all source is in this repo.

Closed 2025-01-02.

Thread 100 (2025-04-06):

Security: Avoid printing GITHUB_TOKEN in workflow logs

BohdanBuinich, 2025-04-06:
Hello,

I noticed that the GitHub Actions workflow contains a line that prints the full authenticated Git URL, including the `${{ secrets.GITHUB_TOKEN }}`:
https://github.com/ZSWatch/Watch-HW/blob/85f999e7fccad1212f0afddf338b57fbeee3052f/.github/workflows/production.yml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

This could unintentionally expose the tokens in the logs, especially if they’re public or shared. Since the token provides write access to the repository, it would be safer to remove this line.

Thanks for the awesome work on this project! 🚀

WenchongWang, 2025-04-06:
这是来自QQ邮箱的假期自动回复邮件。邮件已经收到，我会尽快回复您。

jakkra, 2025-04-06:
Fixed, thanks a lot!

Closed 2025-04-06.

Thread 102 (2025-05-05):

New vibration motor

Kampi, 2025-05-05:
Variants:
- https://www.digikey.de/en/products/detail/vybronics-inc/VC1027B902F/9356387

Closed 2025-05-09.

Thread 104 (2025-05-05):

Rework power supply to use only 1V8 and 3V3

Kampi, 2025-05-05:

Kampi, 2025-05-20:
We use 3V0 instead of 3V0

Closed 2025-05-20.

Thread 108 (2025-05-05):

Change housing for ESDALC6V1W5 and add ESD protection for new dock interface

Kampi, 2025-05-05:
Variants:
- https://assets.nexperia.com/documents/short-data-sheet/PUSB3BB4_SDS.pdf

Closed 2025-05-20.

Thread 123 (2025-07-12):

Rework DISPLAY-EN signal

Kampi, 2025-07-12:
Add pull-up resistor to enable it by default. Can be disabled via GPIO.

Closed 2025-07-13.

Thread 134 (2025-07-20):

Switch back to old LED driver

Kampi, 2025-07-20:
Four channel doesn´t work because it looks like we have to use all four channels.

Closed 2025-07-21.

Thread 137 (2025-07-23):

Add display position to PCB on a different layer

Kampi, 2025-07-23:
@jakkra I must reimport the display DXF into the PCB to change the layer. Can you please provide me the file again?

jakkra, 2025-07-23:
[display_dxf.zip](https://github.com/user-attachments/files/21384923/display_dxf.zip)
This one?

jakkra, 2025-07-23:
You need only to keep the actual circle we have today

Closed 2025-07-23.

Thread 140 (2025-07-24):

Flip Rx and Tx lines for UART and USB

Kampi, 2025-07-24:

Kampi, 2025-07-24:
Done in the dock

Closed 2025-07-24.

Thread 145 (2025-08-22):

Power MIC from nPM1300 LDO

jakkra, 2025-08-22:
This way we can skip MIC-EN and the mosfet causing current leakage.
Using dedicated LDO saves us from any current leakage and we have 2 LDOs unused anyway on the nPM1300.

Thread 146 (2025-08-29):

WtachDK: BMI270 INT pin shall use INT2 and not INT1

jakkra, 2025-08-29:
We used INT2 before, DK uses INT1. This cause some issues. Let's keep it same and use INT2. INT1 can be be left unconnected.

Closed 2025-08-29.

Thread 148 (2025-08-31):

CI/CD fixes

Kampi, 2025-08-31:
- Change the name of the board
- Look through the config
- Add copy workflow from Dock
- Rename branches to make sure CI/CD works with them
- Update README
- Use the KiBot files from the heartrate devkit

Closed 2025-09-06.

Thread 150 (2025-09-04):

Don't use P0.00 and P0.01 (XTAL) pins

jakkra, 2025-09-04:
Change mic DIN and CLK to some other pin.

If we due to routing issues later on small PCB need to use P0.00 and P0.01 we can do the debugging then why those don't work even tho configured properly...

Closed 2025-09-04.

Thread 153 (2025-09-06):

Replace dock connector with USB connector

Kampi, 2025-09-06:

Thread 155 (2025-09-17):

Ship-Mode button is wrong

Kampi, 2025-09-17:
The ship mode pin of the nPM1300 has an internal pull-up to VSYS. So the MCU pin is connected to VSYS all the time which is not good and causes weird behaviours in sleep mode.

We try to trigger ship mode via I2C and remove the connection completely.

Closed 2025-09-18.

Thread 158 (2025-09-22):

Fixes needed for Release 1.2.1

jakkra, 2025-09-22:
- I2C addon header wrong part number, is a 2 pin header, but should be 4 pin
- PCA9306JK - We should add a pin1 marking on the gerber layer exported to PCBWay for assembly help (f.fab I think)
- Missing pullups
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

- Not needed now, but for real watch the FAN5622SX can be optimized, cane shave of 0.3mm of the pads length
- Do we need this resistor? MCU will control CS and the resistor will leak when flash is used. Not much, but for real watch we would save PCB space by removing it
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

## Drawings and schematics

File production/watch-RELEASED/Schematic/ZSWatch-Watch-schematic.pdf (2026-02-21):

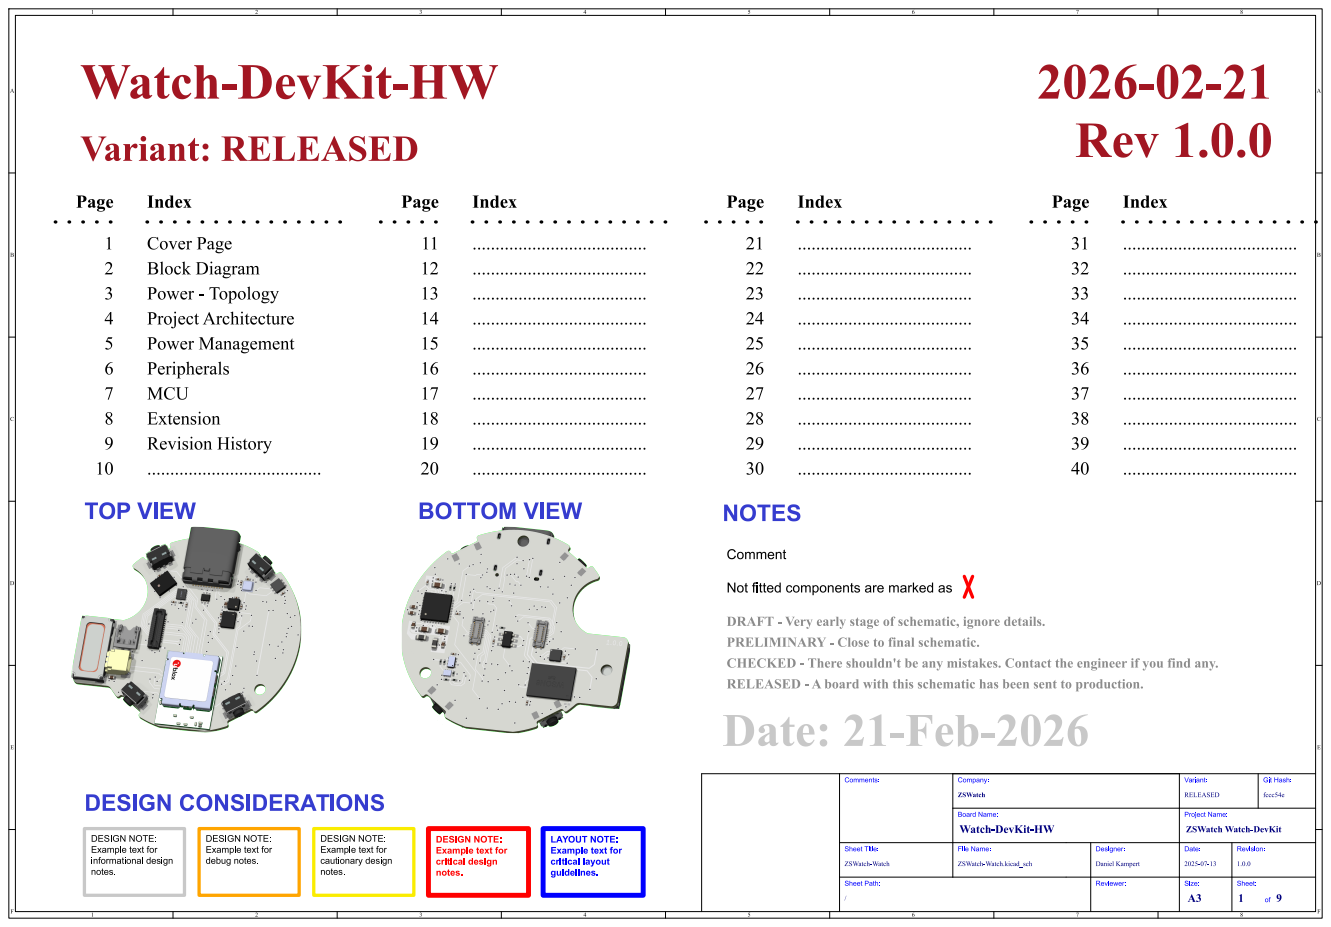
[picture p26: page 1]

...................................... PRELIMINARY - Closetofinal schematic.
CHECKED - Thereshouldn'tbeanymistakes.Contacttheengineerif youfindany. ......................................

Not fitted components are marked as

DRAFT - Veryearlystageof schematic,ignoredetails.

Revision: 1.0.0 Date: Project Name: 2025-07-13 Reviewer: Designer:

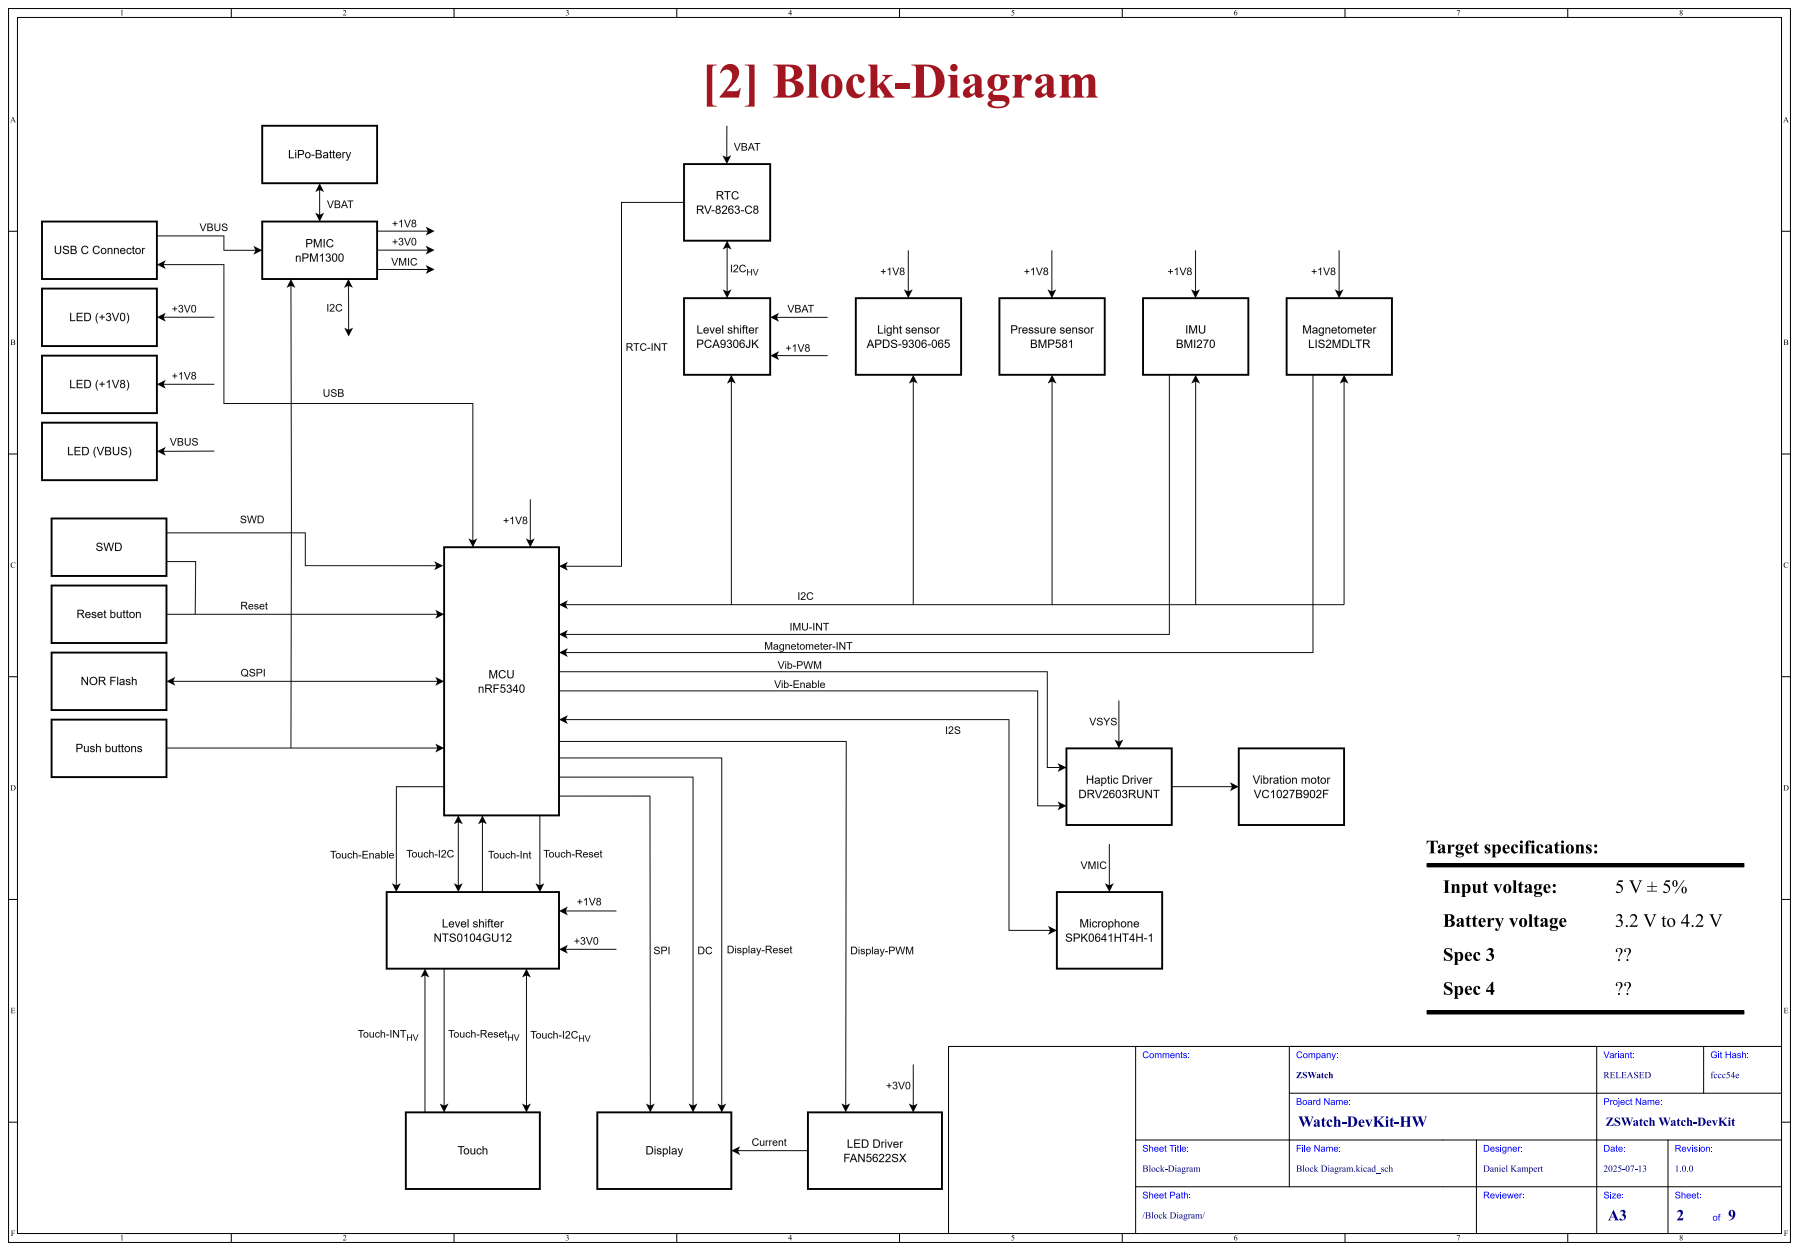
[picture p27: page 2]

/Block Diagram/ Sheet Path: Block-Diagram

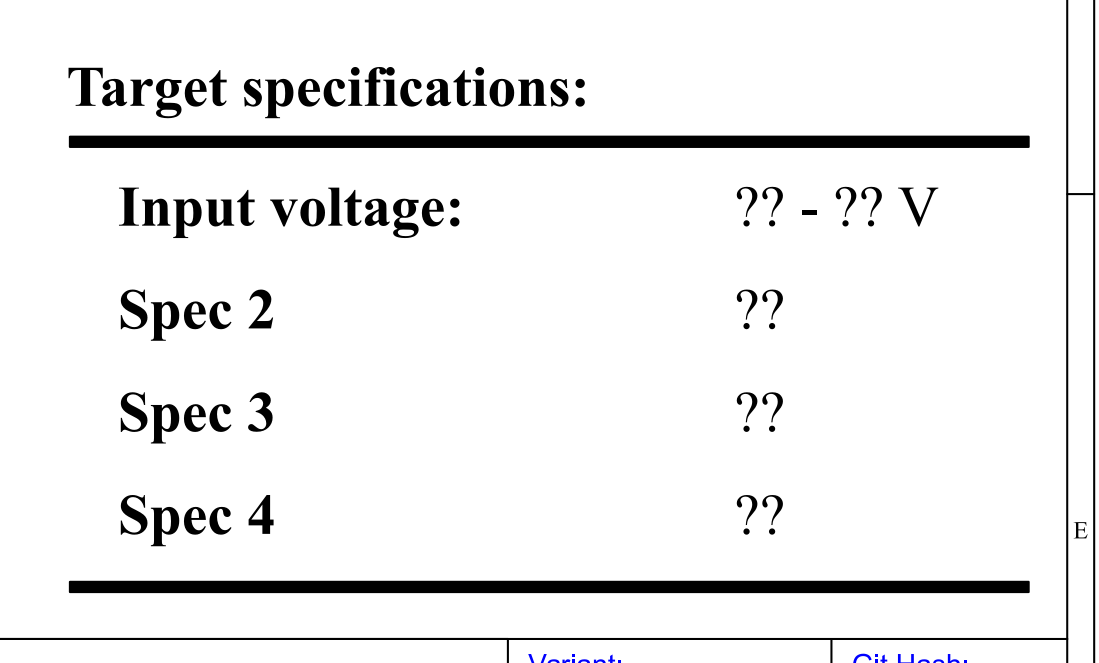
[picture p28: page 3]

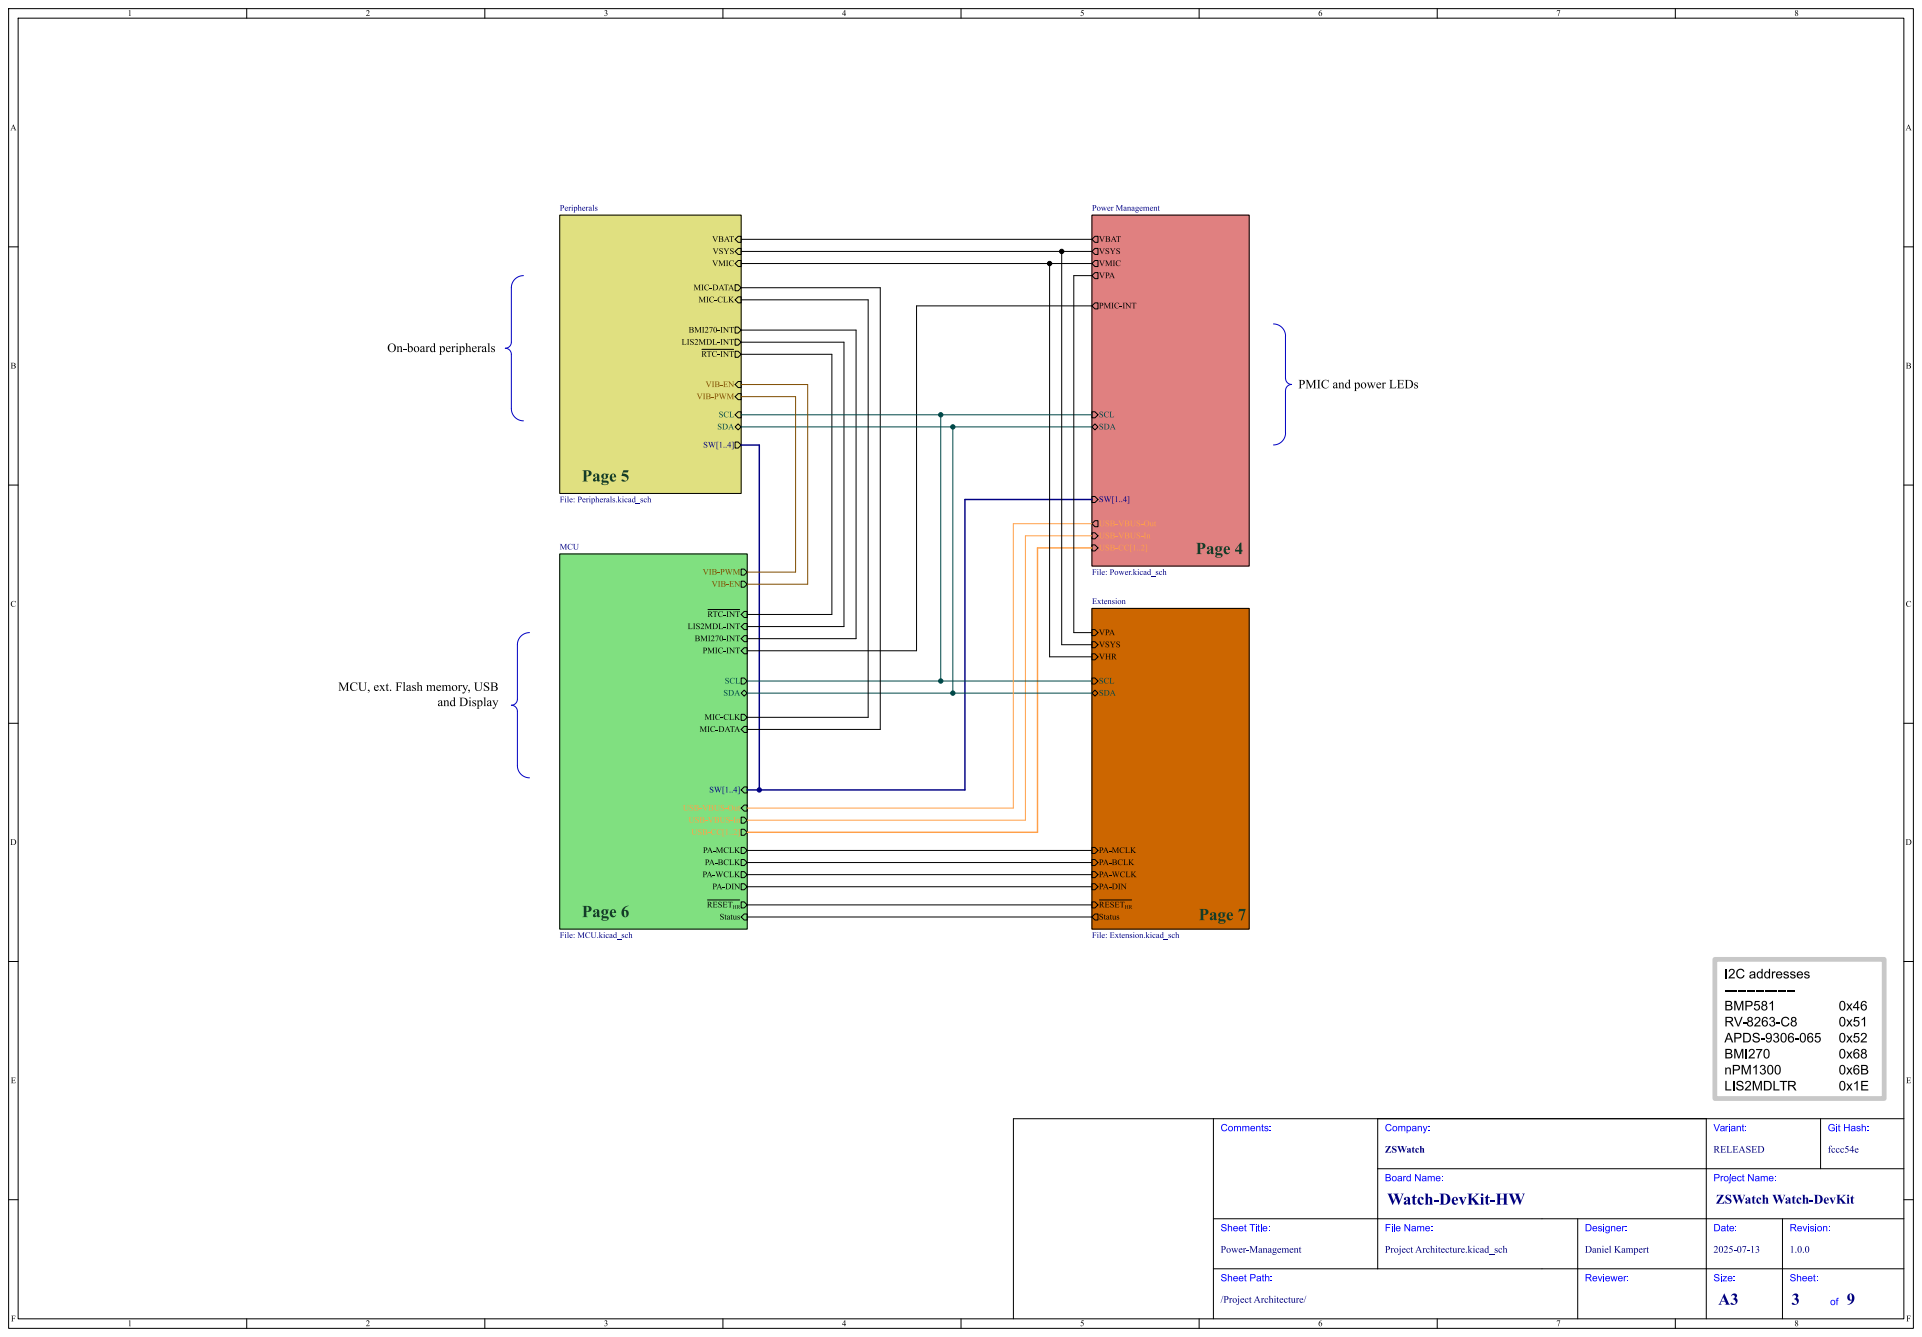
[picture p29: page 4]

PowerManagement File: Power.kicad_sch SCL
SW[1..4] VBAT VSYS

VBAT USB-VBUS-In USB-CC[1..2] USB-VBUS-Out SW[1..4] VMIC
VSYS

LIS2MDL-INT BMI270-INT MIC-CLK MIC-DATA

~{RTC-INT} VIB-EN

PA-MCLK MCU
LIS2MDL-INT BMI270-INT PMIC-INT MIC-DATA MIC-CLK USB-VBUS-In USB-CC[1..2] USB-VBUS-Out SW[1..4]

VIB-PWM

MCU, ext.Flashmemory,USB

PA-MCLK
PA-BCLK
PA-WCLK
~{RESET_{HR}} Status PA-DIN

Revision: 1.0.0 Date: Project Name: 2025-07-13 Reviewer: Designer:

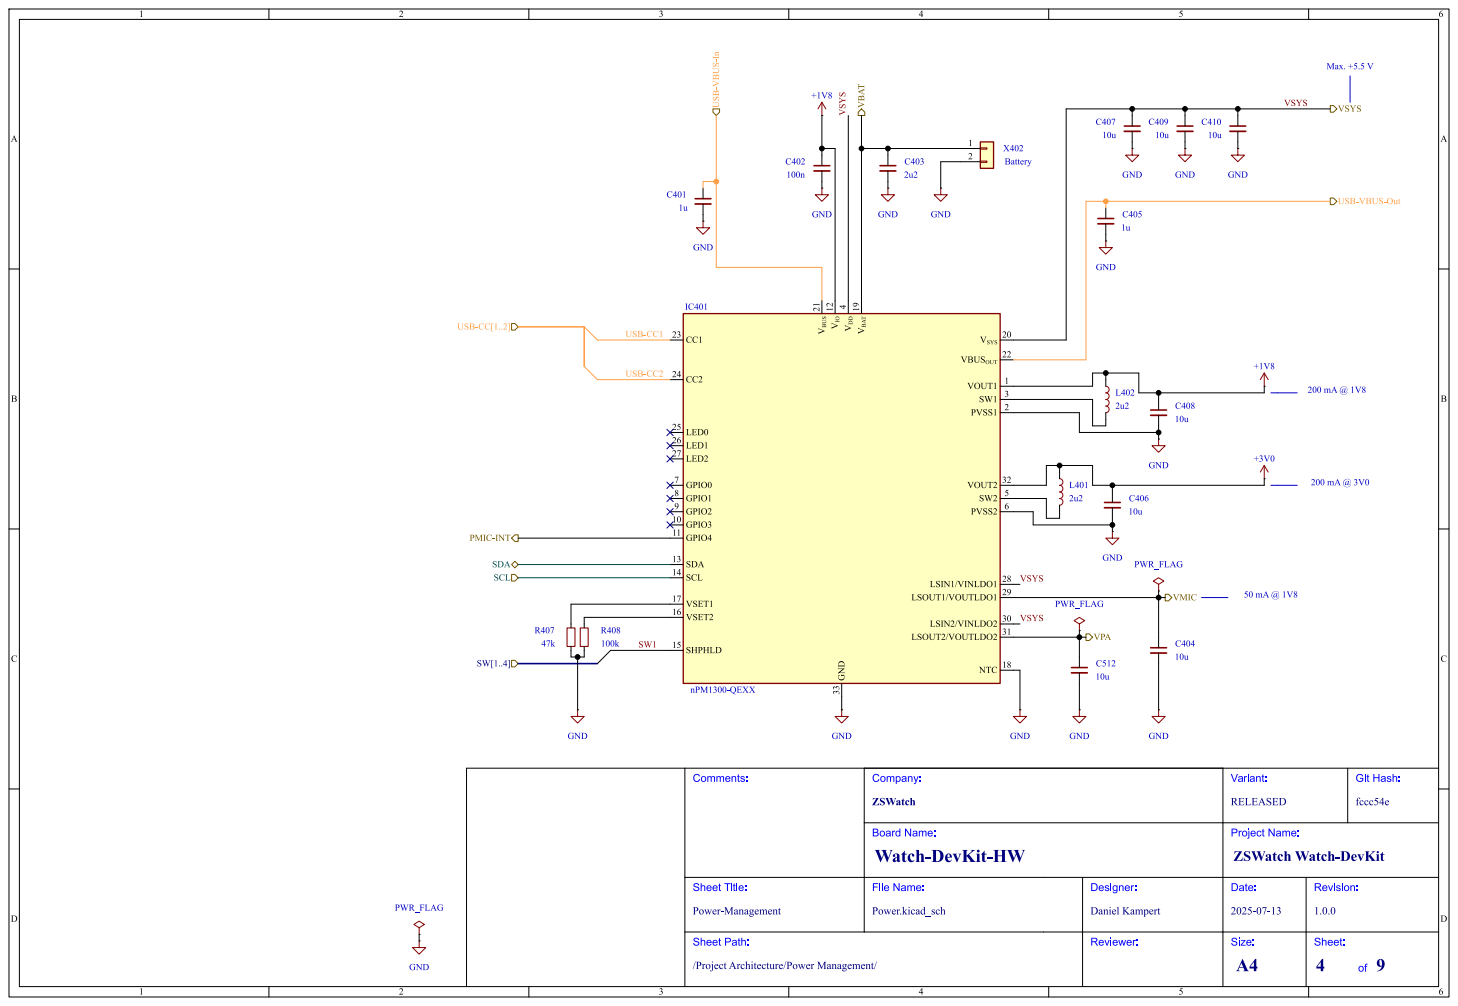
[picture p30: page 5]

USB-VBUS-Out VSYS

Revision: 1.0.0 Date: Project Name: 2025-07-13 Reviewer: Designer:

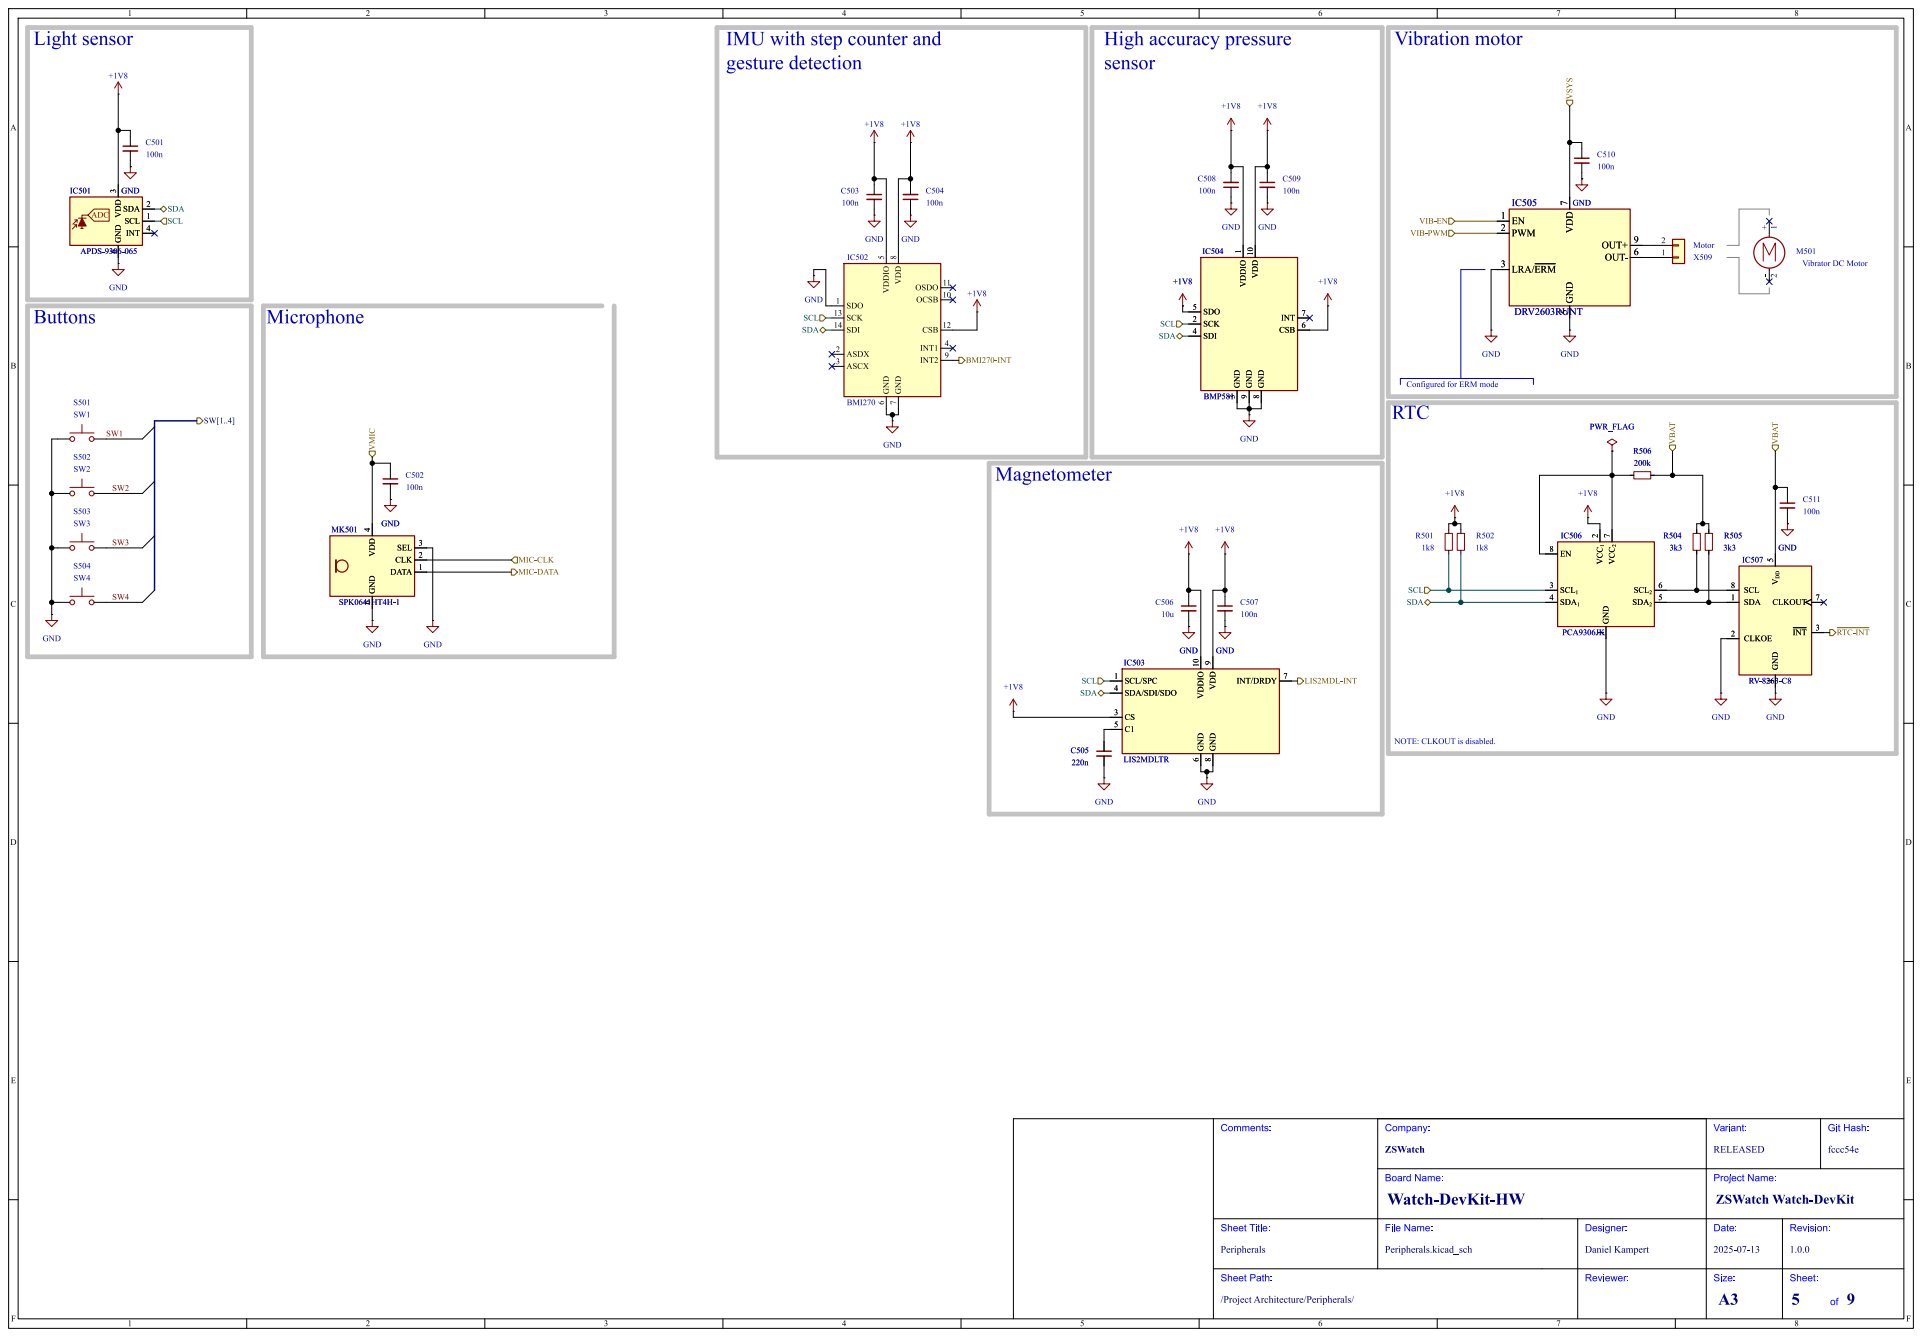
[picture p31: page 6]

NOTE: CLKOUT is disabled. Light sensor

Configuredfor ERM mode IMU with stepcounterand
gesturedetection

5 OUT+ 9 OUT- 6 GND GND

-2 M501 VibratorDC Motor SDO 1 SCK 13 SDI 14 ASDX 2 ASCX 3 VDDIO

MIC-CLK MIC-DATA

Revision: 1.0.0 Date: Project Name: 2025-07-13 Reviewer: Designer:

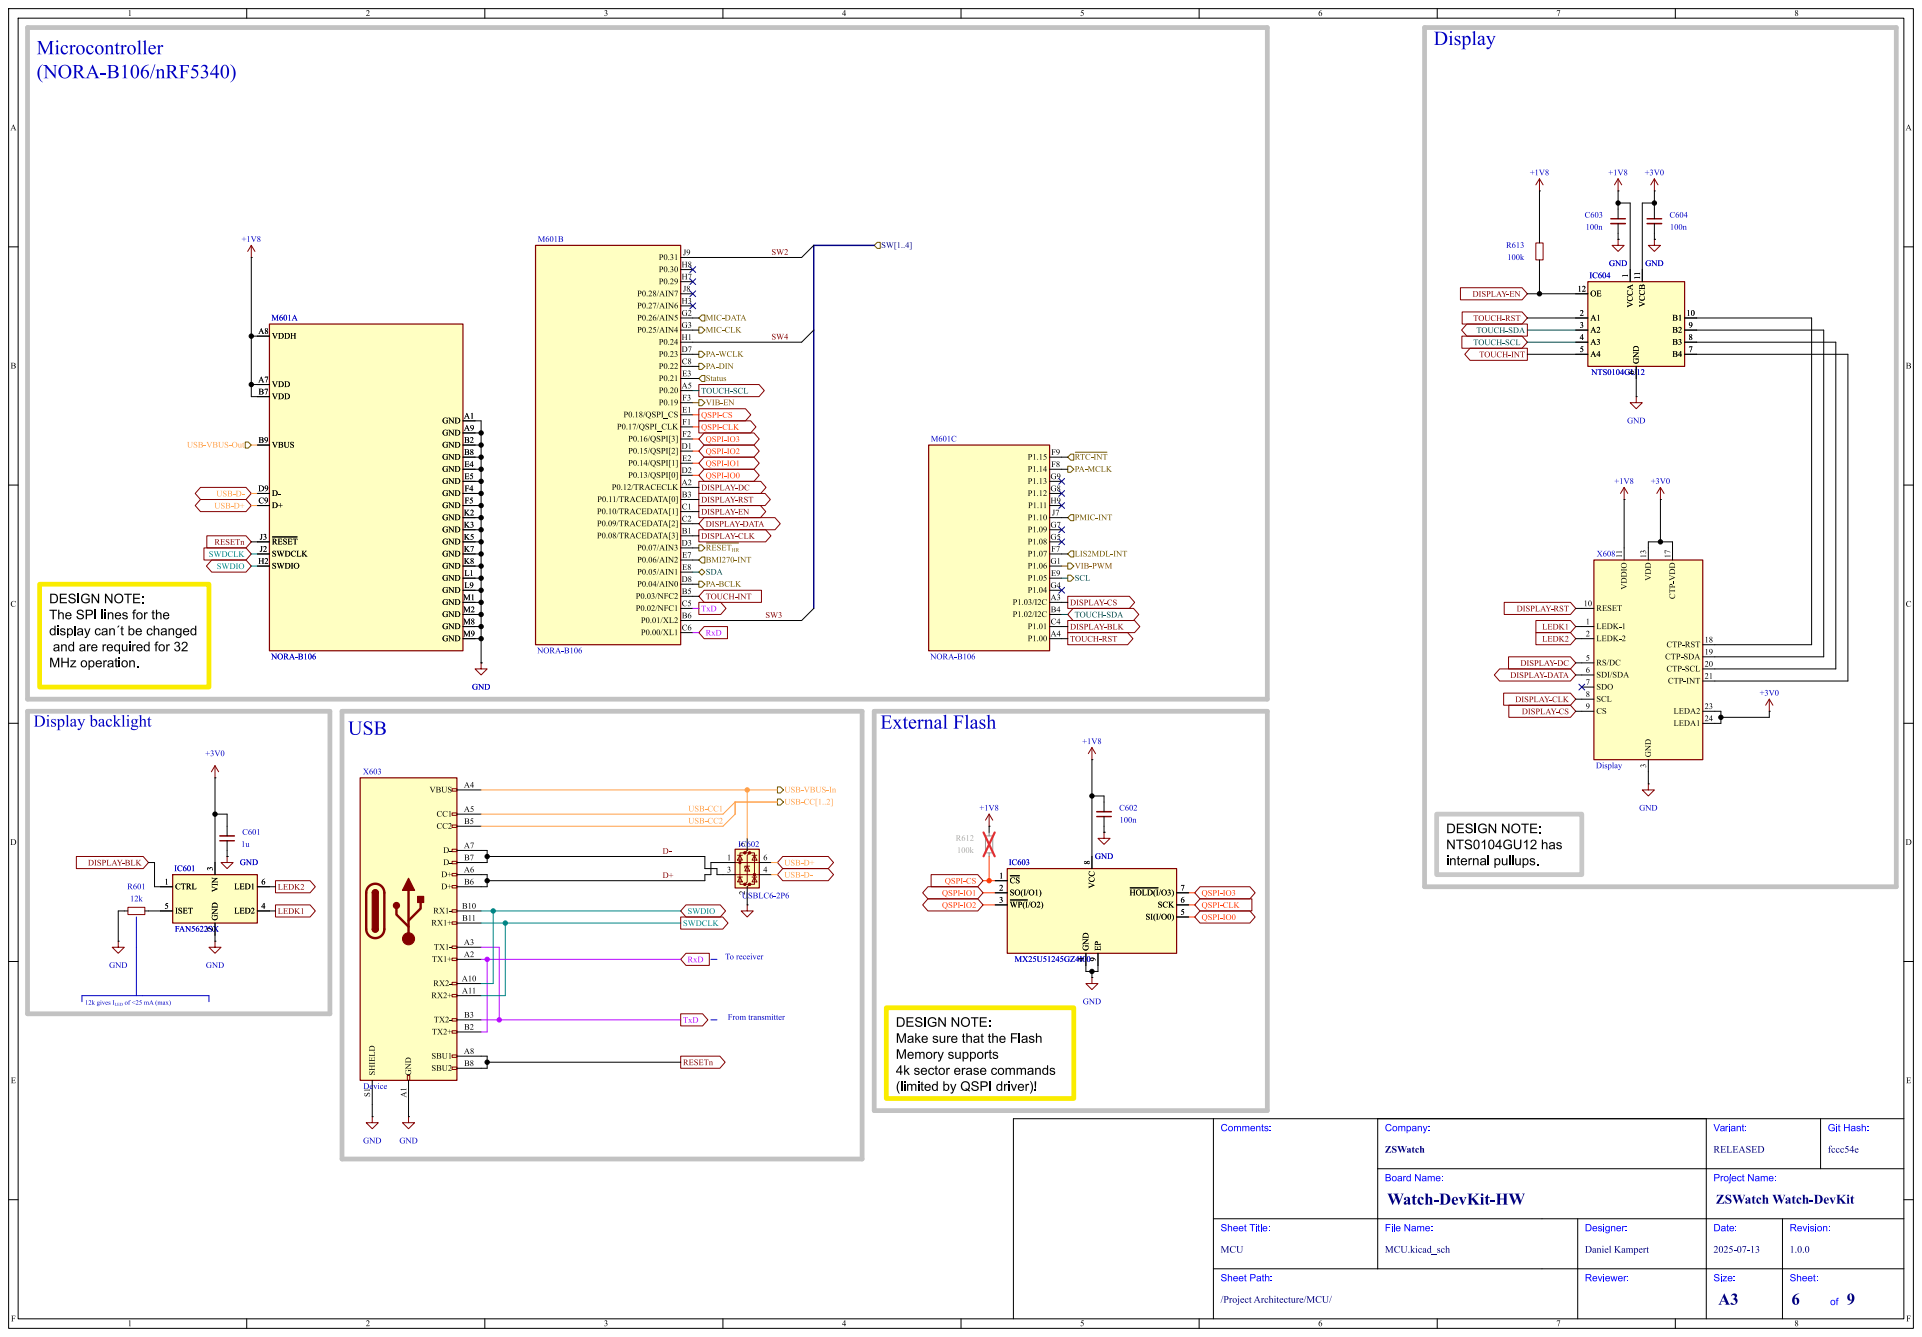
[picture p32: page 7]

PA-DIN MIC-DATA

8 B4

PMIC-INT VIB-EN QSPI-IO2 RxD

DISPLAY-CLK DISPLAY-DATA QSPI-CLK

USB-D+ USB-D- SWDCLK RESETn SWDIO

3 CTP-VDD 17 CTP-RST

The SPI lines for the
display þÿcan´t be changed
and are required for 32
MHz operation.

9 ~{HOLD(I}/O3)7 SCK 6 SI(I/O0) 5 GND IC601 FAN5622SX CTRL 1
CTRL 1

DESIGN NOTE:
Make sure that the Flash
Memory supports
4k sector erase commands
(limited by QSPI driver)!

Revision: 1.0.0 Date: Project Name: 2025-07-13 Reviewer: Designer:

/ProjectArchitecture/MCU/ Sheet Path: MCU

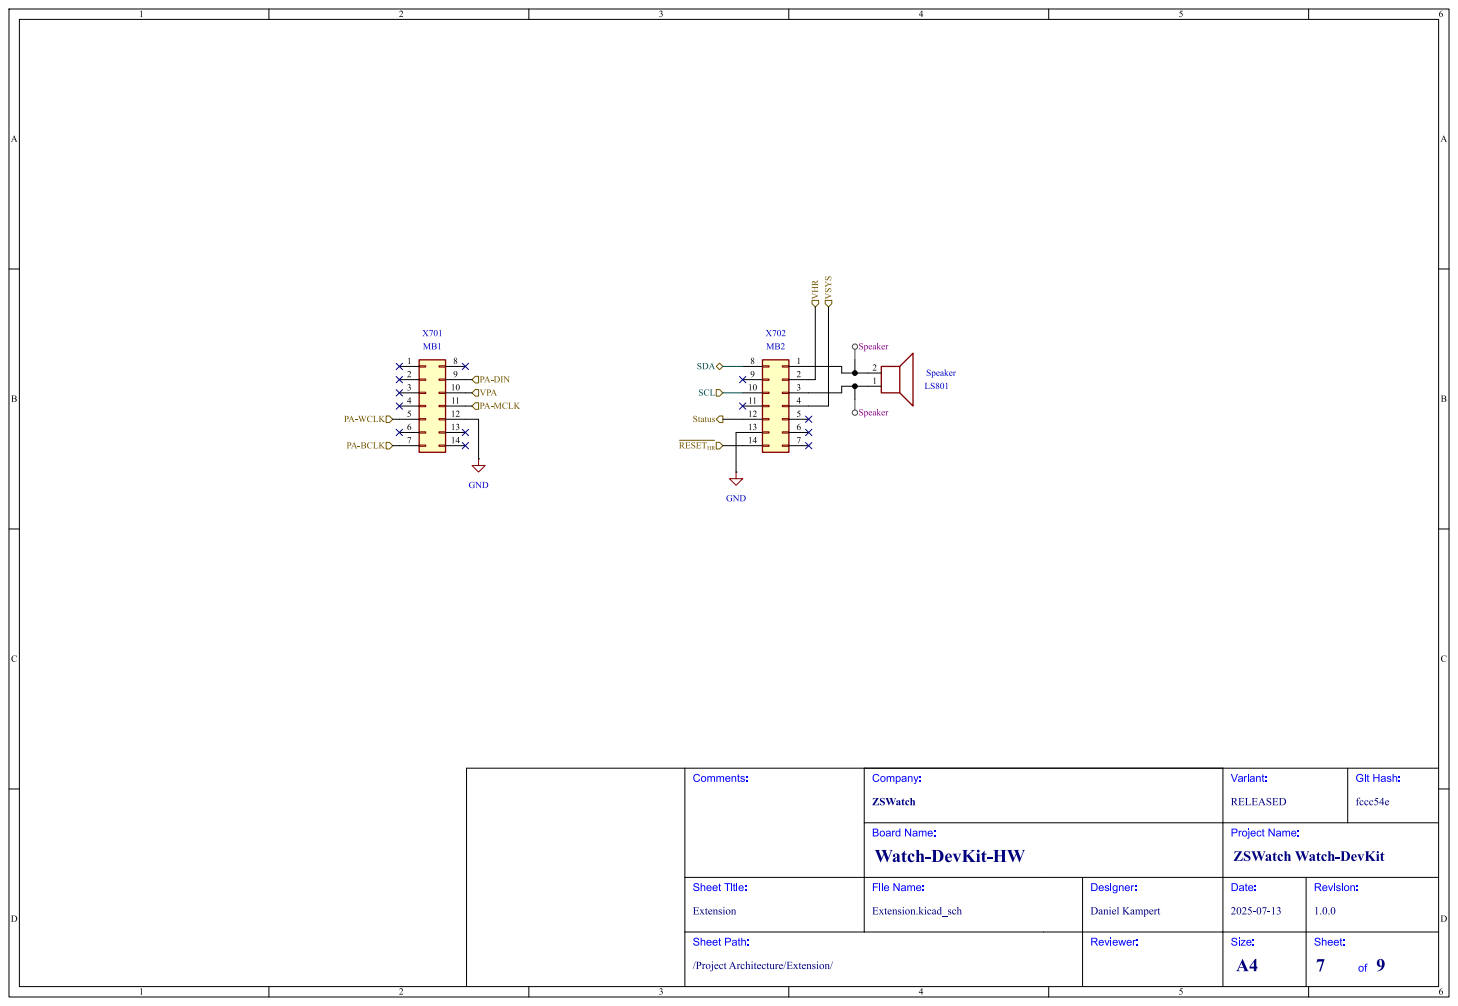
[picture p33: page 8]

Revision: 1.0.0 Date: Project Name: 2025-07-13 Reviewer: Designer:

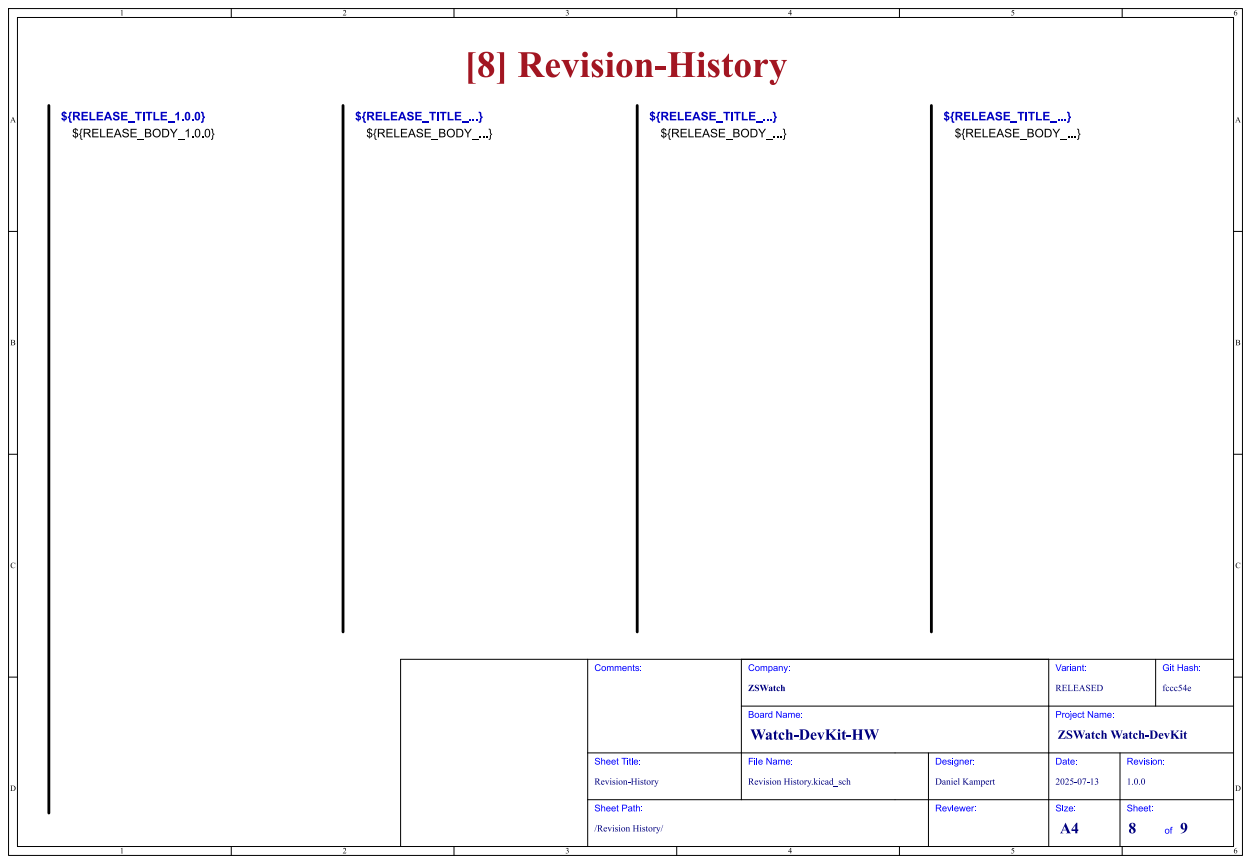
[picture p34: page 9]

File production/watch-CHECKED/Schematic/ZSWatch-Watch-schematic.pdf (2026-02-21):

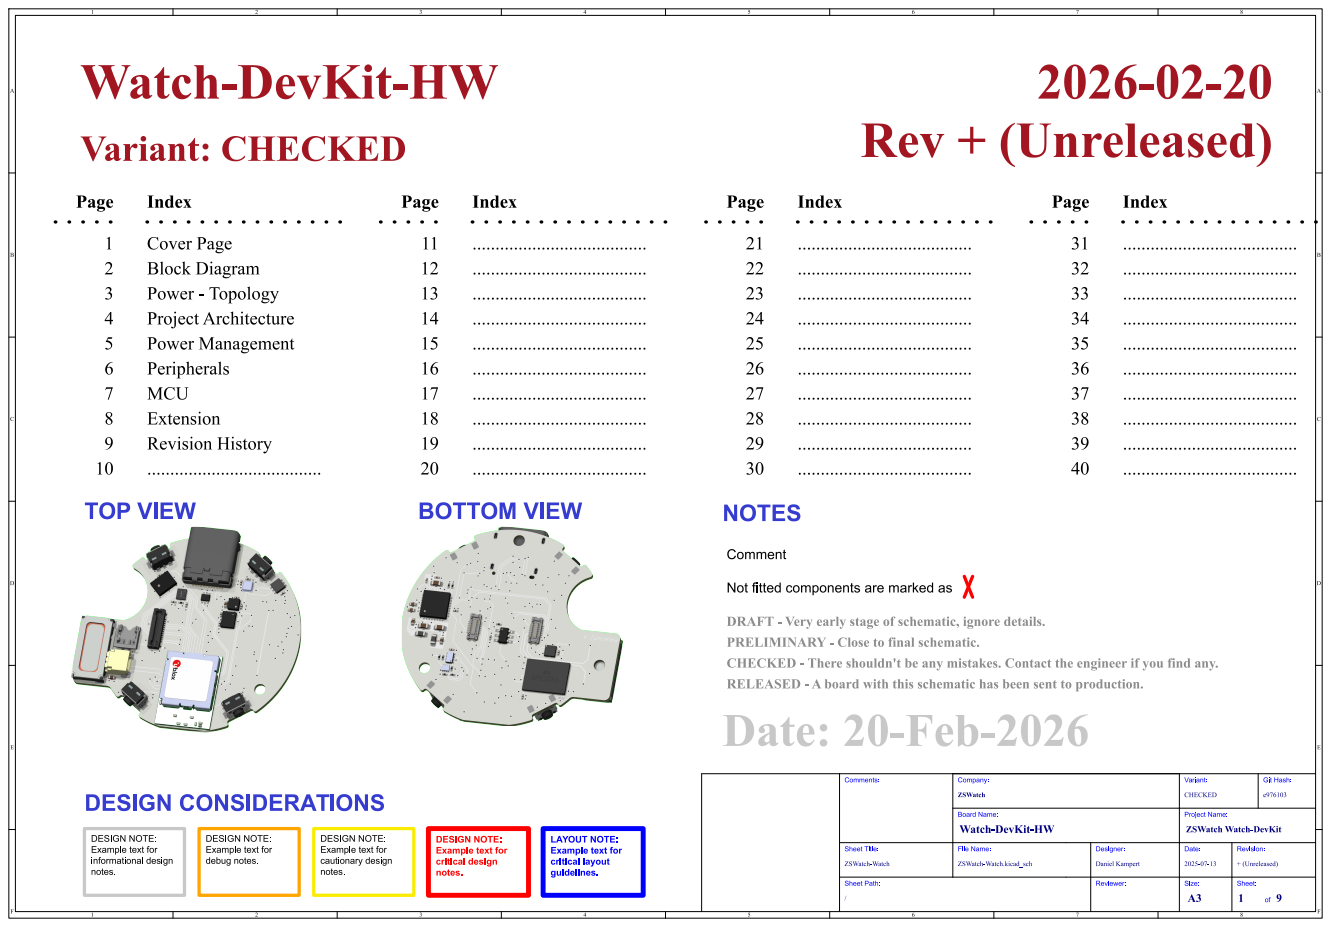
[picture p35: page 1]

...................................... PRELIMINARY - Closetofinal schematic.
CHECKED - Thereshouldn'tbeanymistakes.Contacttheengineerif youfindany. ......................................

Not fitted components are marked as

DRAFT - Veryearlystageof schematic,ignoredetails.

Revision: + (Unreleased) Date: Project Name: 2025-07-13 Reviewer: Designer:

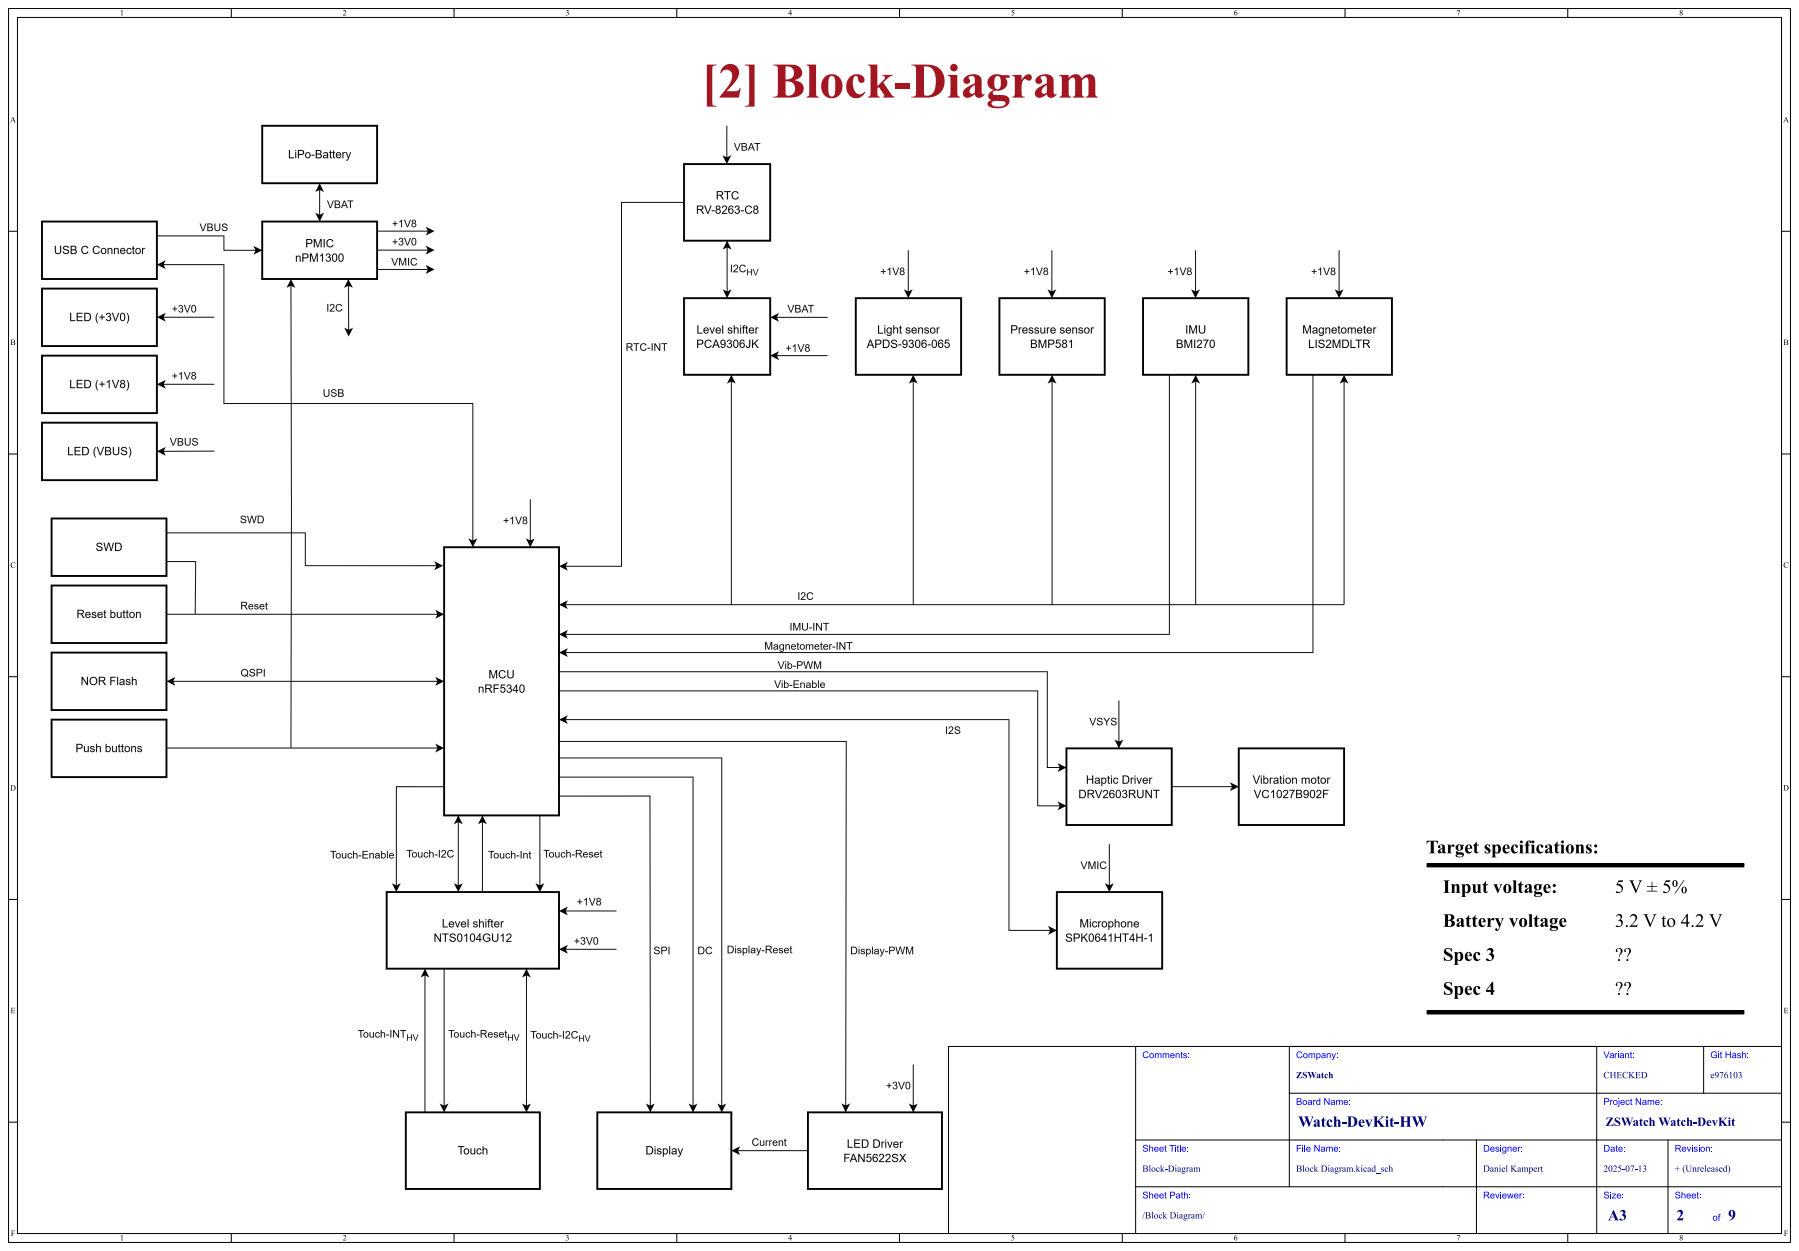
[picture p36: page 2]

/Block Diagram/ Sheet Path: Block-Diagram


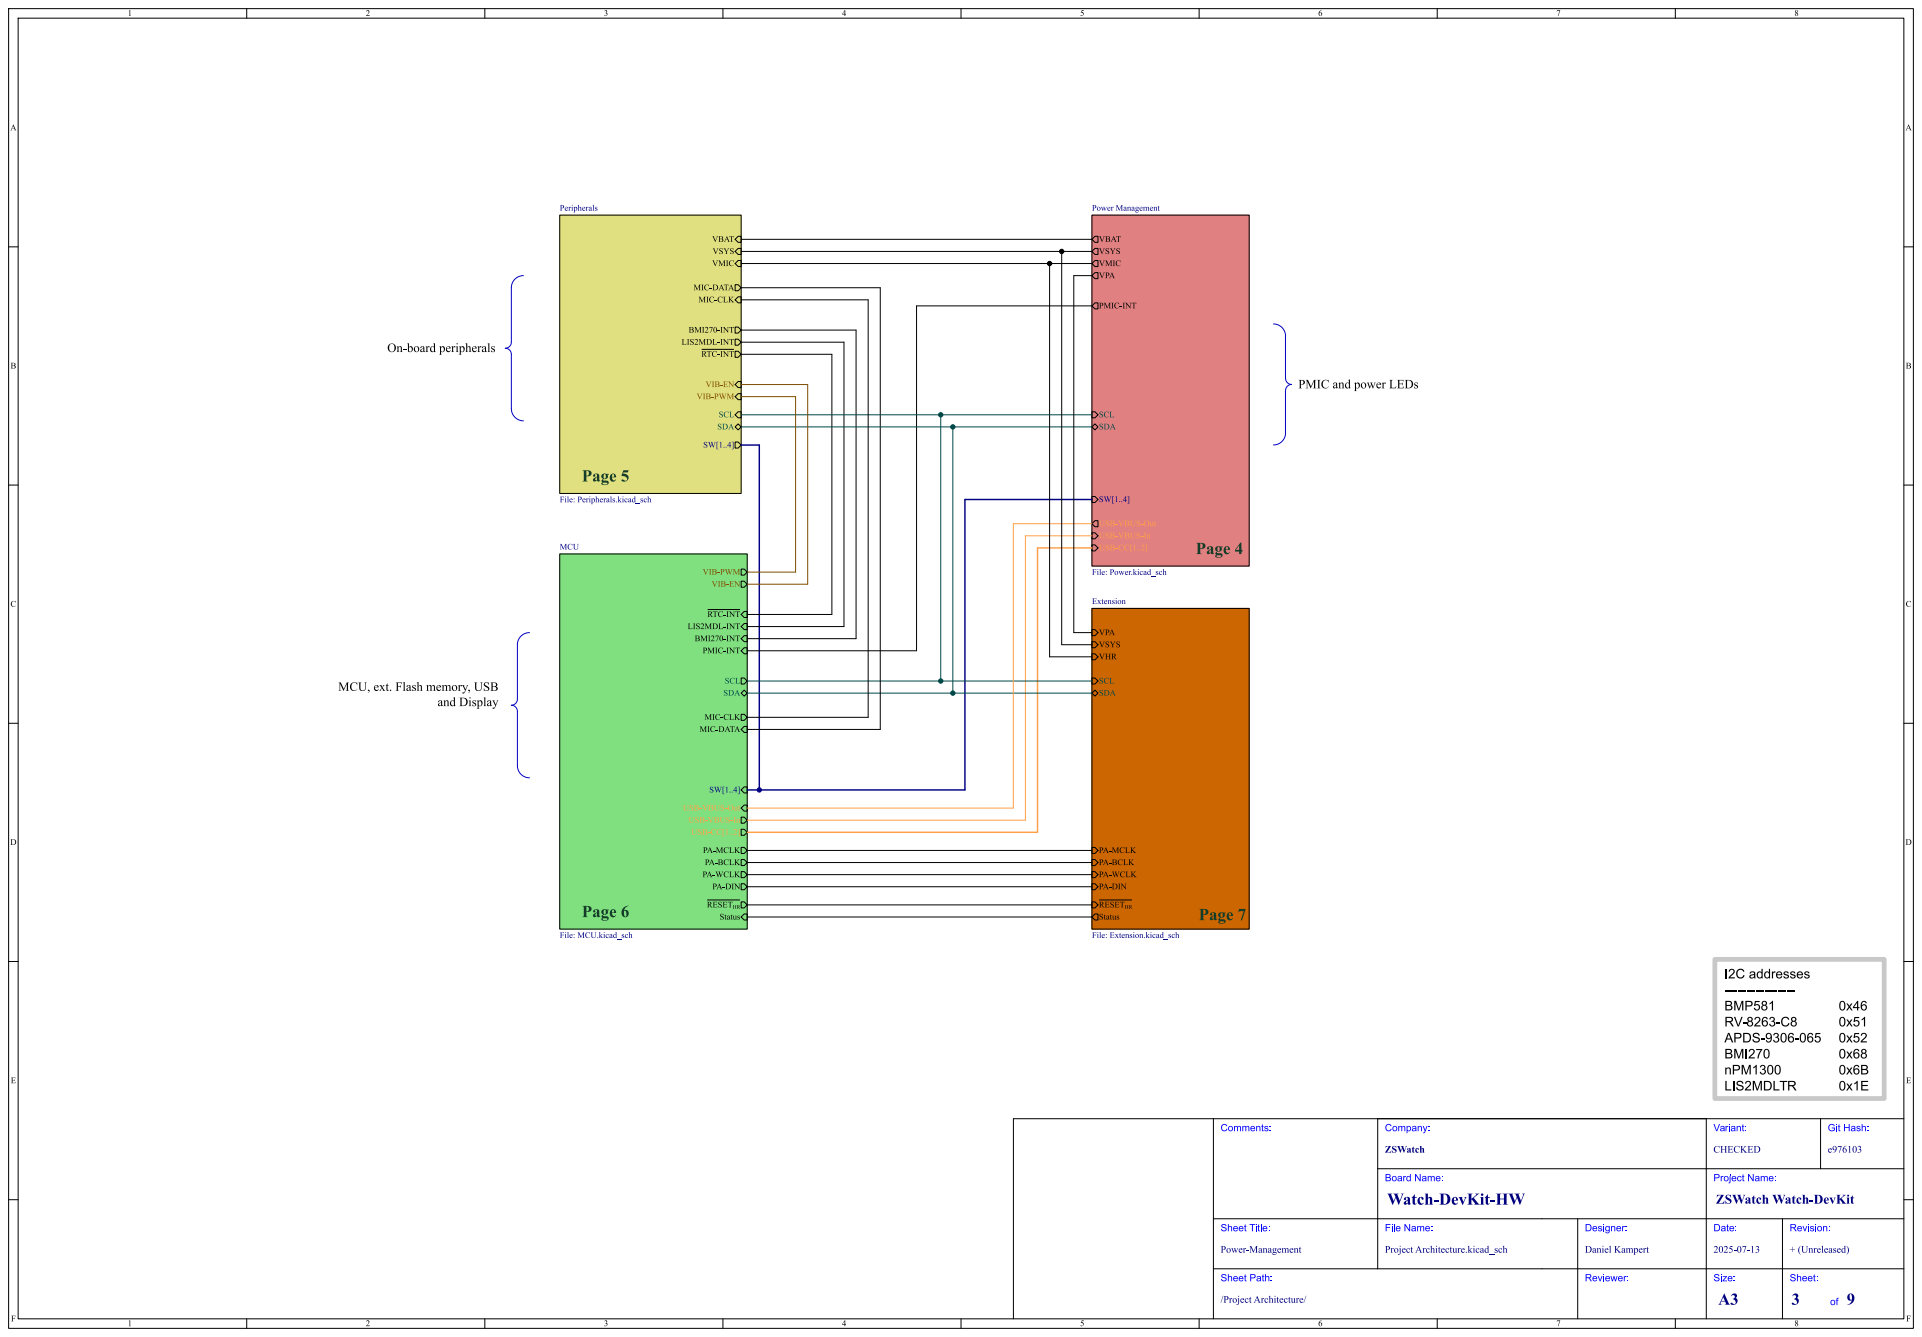
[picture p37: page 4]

PowerManagement File: Power.kicad_sch SCL
SW[1..4] VBAT VSYS

VBAT USB-VBUS-In USB-CC[1..2] USB-VBUS-Out SW[1..4] VMIC
VSYS

LIS2MDL-INT BMI270-INT MIC-CLK MIC-DATA

~{RTC-INT} VIB-EN

PA-MCLK MCU
LIS2MDL-INT BMI270-INT PMIC-INT MIC-DATA MIC-CLK USB-VBUS-In USB-CC[1..2] USB-VBUS-Out SW[1..4]

VIB-PWM

MCU, ext.Flashmemory,USB

PA-MCLK
PA-BCLK
PA-WCLK
~{RESET_{HR}} Status PA-DIN

Revision: + (Unreleased) Date: Project Name: 2025-07-13 Reviewer: Designer:


USB-VBUS-Out VSYS

Revision: + (Unreleased) Date: Project Name: 2025-07-13 Reviewer: Designer:


NOTE: CLKOUT is disabled. Light sensor

Configuredfor ERM mode IMU with stepcounterand
gesturedetection

5 OUT+ 9 OUT- 6 GND GND

-2 M501 VibratorDC Motor SDO 1 SCK 13 SDI 14 ASDX 2 ASCX 3 VDDIO

MIC-CLK MIC-DATA

Revision: + (Unreleased) Date: Project Name: 2025-07-13 Reviewer: Designer:


PA-DIN MIC-DATA

8 B4

PMIC-INT VIB-EN QSPI-IO2 RxD

DISPLAY-CLK DISPLAY-DATA QSPI-CLK

USB-D+ USB-D- SWDCLK RESETn SWDIO

3 CTP-VDD 17 CTP-RST

The SPI lines for the
display þÿcan´t be changed
and are required for 32
MHz operation.

9 ~{HOLD(I}/O3)7 SCK 6 SI(I/O0) 5 GND IC601 FAN5622SX CTRL 1
CTRL 1

DESIGN NOTE:
Make sure that the Flash
Memory supports
4k sector erase commands
(limited by QSPI driver)!

Revision: + (Unreleased) Date: Project Name: 2025-07-13 Reviewer: Designer:

/ProjectArchitecture/MCU/ Sheet Path: MCU


Revision: + (Unreleased) Date: Project Name: 2025-07-13 Reviewer: Designer:


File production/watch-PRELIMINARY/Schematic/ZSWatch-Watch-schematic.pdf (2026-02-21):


Error:XML File not found
TOP VIEW

CoverPage

BOTTOM VIEW
kibot_image_png_3d_viewer_angled_bottom DESIGN NOTE:

NOTES

Not fitted components are marked as

DRAFT - Veryearlystageof schematic,ignoredetails.
PRELIMINARY - Closetofinal schematic.
CHECKED - Thereshouldn'tbeanymistakes.Contacttheengineerif youfindany.
RELEASED - A boardwiththisschematichasbeensenttoproduction.
Date:19-Feb-2026

Revision: + (Unreleased) Date: Project Name: 2025-07-13 Reviewer: Designer:

File: Project Architecture.kicad_sch DESIGN NOTE:
Example text for
debug notes.


/Block Diagram/ Sheet Path: Block-Diagram



PowerManagement File: Power.kicad_sch SCL
SW[1..4] VBAT VSYS

VBAT USB-VBUS-In USB-CC[1..2] USB-VBUS-Out SW[1..4] VMIC
VSYS

LIS2MDL-INT BMI270-INT MIC-CLK MIC-DATA

~{RTC-INT} VIB-EN

PA-MCLK MCU
LIS2MDL-INT BMI270-INT PMIC-INT MIC-DATA MIC-CLK USB-VBUS-In USB-CC[1..2] USB-VBUS-Out SW[1..4]

VIB-PWM

MCU, ext.Flashmemory,USB

PA-MCLK
PA-BCLK
PA-WCLK
~{RESET_{HR}} Status PA-DIN

Revision: + (Unreleased) Date: Project Name: 2025-07-13 Reviewer: Designer:


USB-VBUS-Out VSYS

Revision: + (Unreleased) Date: Project Name: 2025-07-13 Reviewer: Designer:


NOTE: CLKOUT is disabled. Light sensor

Configuredfor ERM mode IMU with stepcounterand
gesturedetection

5 OUT+ 9 OUT- 6 GND GND

-2 M501 VibratorDC Motor SDO 1 SCK 13 SDI 14 ASDX 2 ASCX 3 VDDIO

MIC-CLK MIC-DATA

Revision: + (Unreleased) Date: Project Name: 2025-07-13 Reviewer: Designer:


PA-DIN MIC-DATA

8 B4

PMIC-INT VIB-EN QSPI-IO2 RxD

DISPLAY-CLK DISPLAY-DATA QSPI-CLK

USB-D+ USB-D- SWDCLK RESETn SWDIO

3 CTP-VDD 17 CTP-RST

The SPI lines for the
display þÿcan´t be changed
and are required for 32
MHz operation.

9 ~{HOLD(I}/O3)7 SCK 6 SI(I/O0) 5 GND IC601 FAN5622SX CTRL 1
CTRL 1

DESIGN NOTE:
Make sure that the Flash
Memory supports
4k sector erase commands
(limited by QSPI driver)!

Revision: + (Unreleased) Date: Project Name: 2025-07-13 Reviewer: Designer:

/ProjectArchitecture/MCU/ Sheet Path: MCU


Revision: + (Unreleased) Date: Project Name: 2025-07-13 Reviewer: Designer:


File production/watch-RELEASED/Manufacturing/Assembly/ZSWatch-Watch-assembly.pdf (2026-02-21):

# Watch-DevKit-HW Assembly Document

Git; Hash:; ZSWatch; Comments:; Sheet Path:; Sheet Title:; File Name:; Watch-DevKit-HW; ZSWatch Watch-DevKit; Company:; RELEASED; Variant:; Board Name:; ZSWatch-Watch.kicad_pcb; Daniel Kampert; Designer:; Reviewer:; Project Name:; Date:; Revision:; Size:; Sheet:

Top/Bottom View

# Top Assembly (Scale 1:1)


# Bottom Assembly (Scale 1:1)







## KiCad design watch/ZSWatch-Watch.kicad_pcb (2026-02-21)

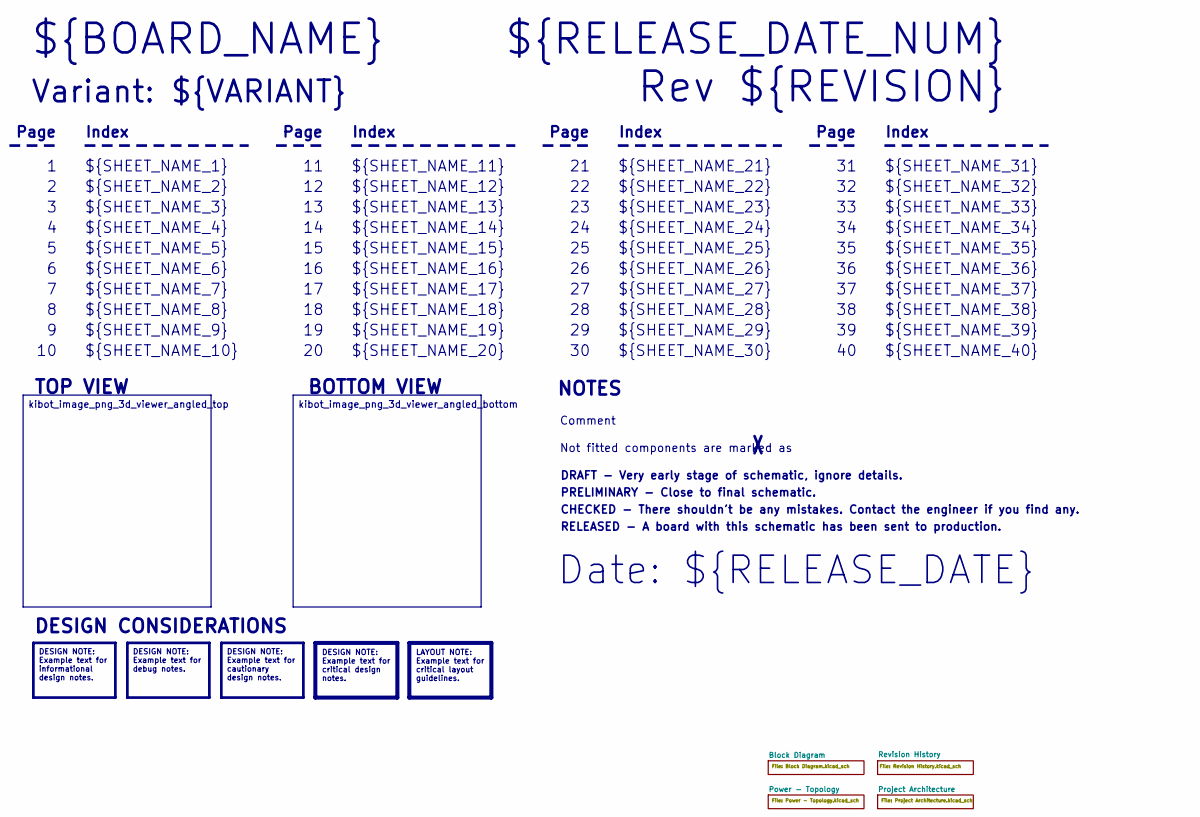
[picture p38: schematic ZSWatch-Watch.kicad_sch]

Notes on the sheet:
Variant: ${VARIANT}
RELEASED - A board with this schematic has been sent to production.
${SHEET_NAME_24}
Index
Page
PRELIMINARY - Close to final schematic.
${SHEET_NAME_22}
DRAFT - Very early stage of schematic, ignore details.
${SHEET_NAME_12}
${SHEET_NAME_8}
${SHEET_NAME_2}
${SHEET_NAME_5}
${SHEET_NAME_20}
${SHEET_NAME_23}
${RELEASE_DATE_NUM}
${SHEET_NAME_35}
Not fitted components are marked as
${SHEET_NAME_11}
${SHEET_NAME_6}
${SHEET_NAME_37}
${SHEET_NAME_26}
${SHEET_NAME_36}
Rev ${REVISION}
${SHEET_NAME_15}
CHECKED - There shouldn't be any mistakes. Contact the engineer if you find any.
BOTTOM VIEW
${SHEET_NAME_14}
${SHEET_NAME_21}
${SHEET_NAME_17}
${SHEET_NAME_18}
Date: ${RELEASE_DATE}
${SHEET_NAME_7}
${SHEET_NAME_31}
${BOARD_NAME}
NOTES
${SHEET_NAME_40}
${SHEET_NAME_39}
${SHEET_NAME_32}
${SHEET_NAME_1}
${SHEET_NAME_9}

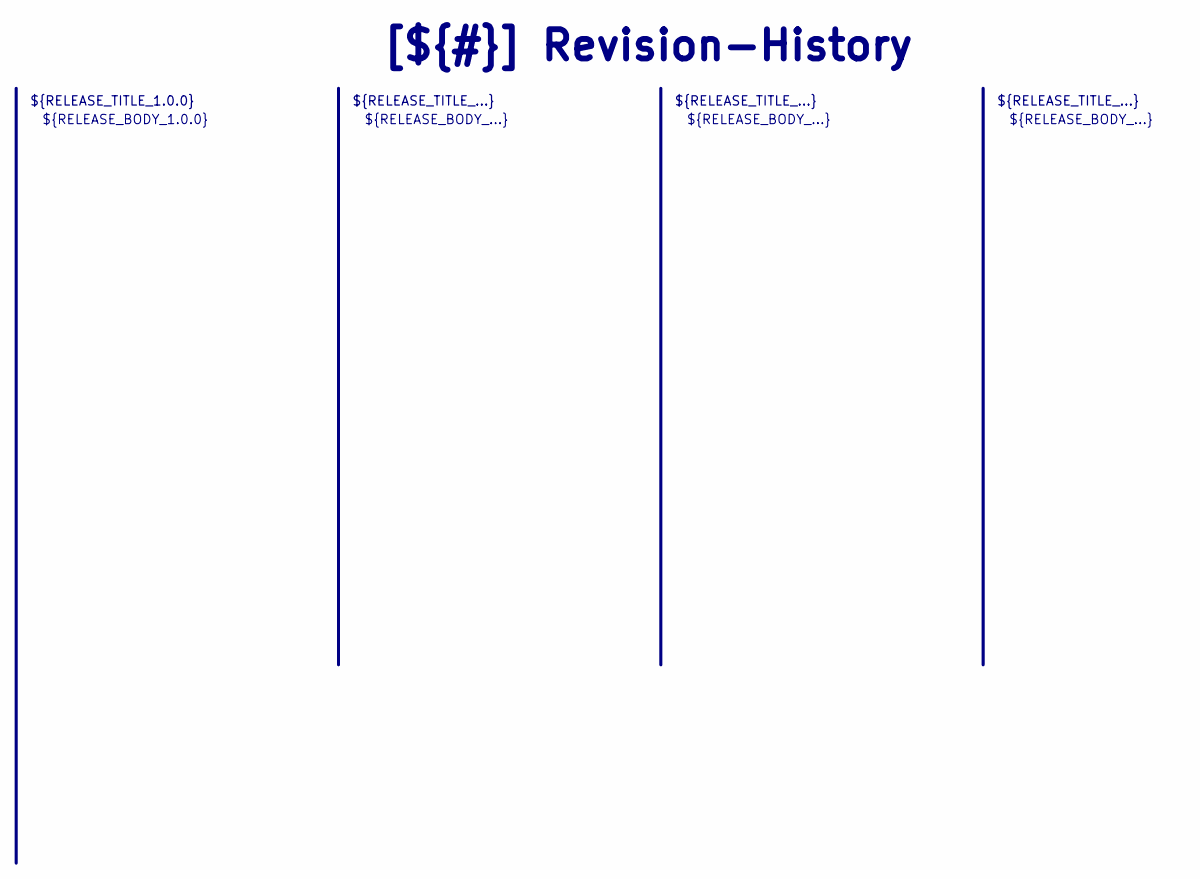
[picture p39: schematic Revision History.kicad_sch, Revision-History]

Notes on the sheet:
${RELEASE_BODY_...}
[${#}] ${TITLE}
${RELEASE_BODY_1.0.0}
${RELEASE_TITLE_...}
${RELEASE_TITLE_1.0.0}

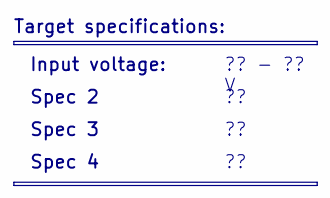
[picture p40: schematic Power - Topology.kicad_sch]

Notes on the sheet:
Spec 2
Input voltage:
Spec 4
?? - ?? V
Target specifications:
Spec 3

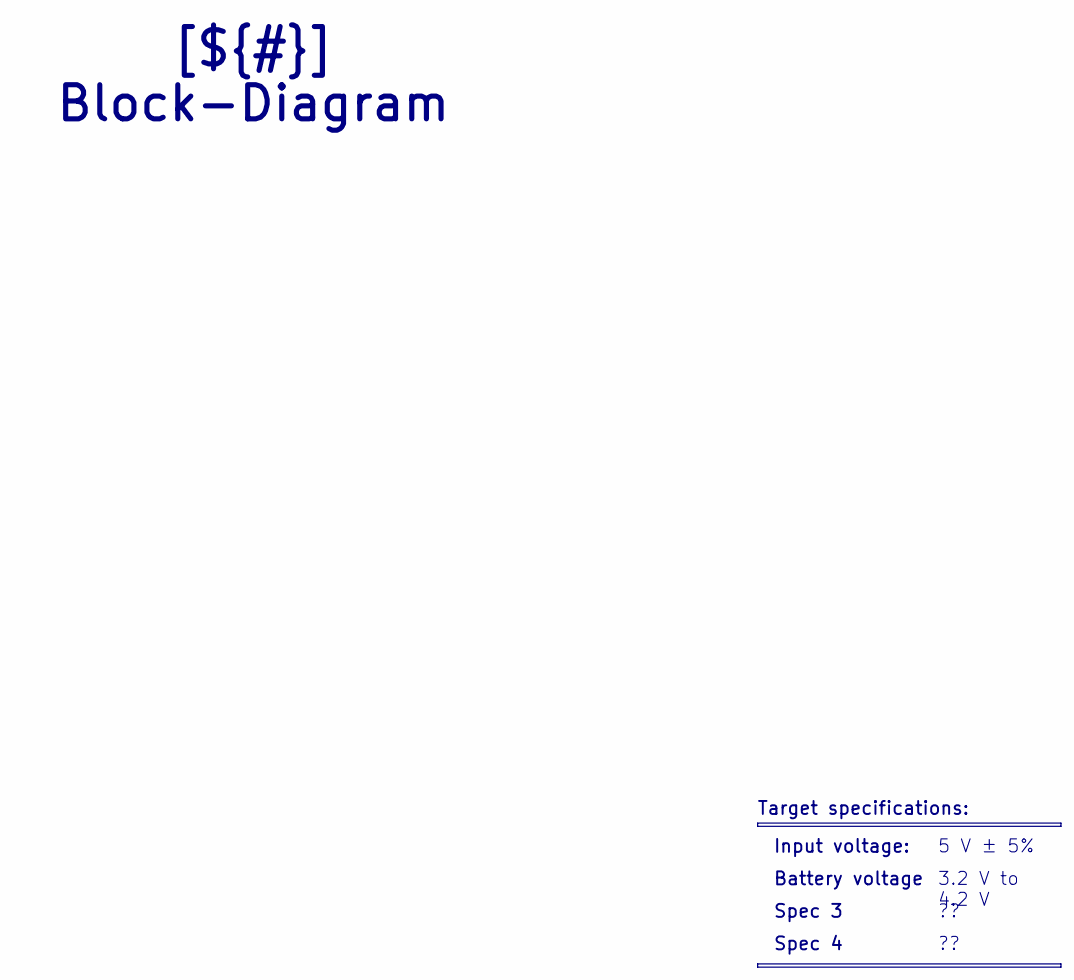
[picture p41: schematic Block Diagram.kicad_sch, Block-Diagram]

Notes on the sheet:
Spec 4
5 V ± 5%
[${#}] ${TITLE}
3.2 V to 4.2 V
Input voltage:
Target specifications:
Spec 3
Battery voltage

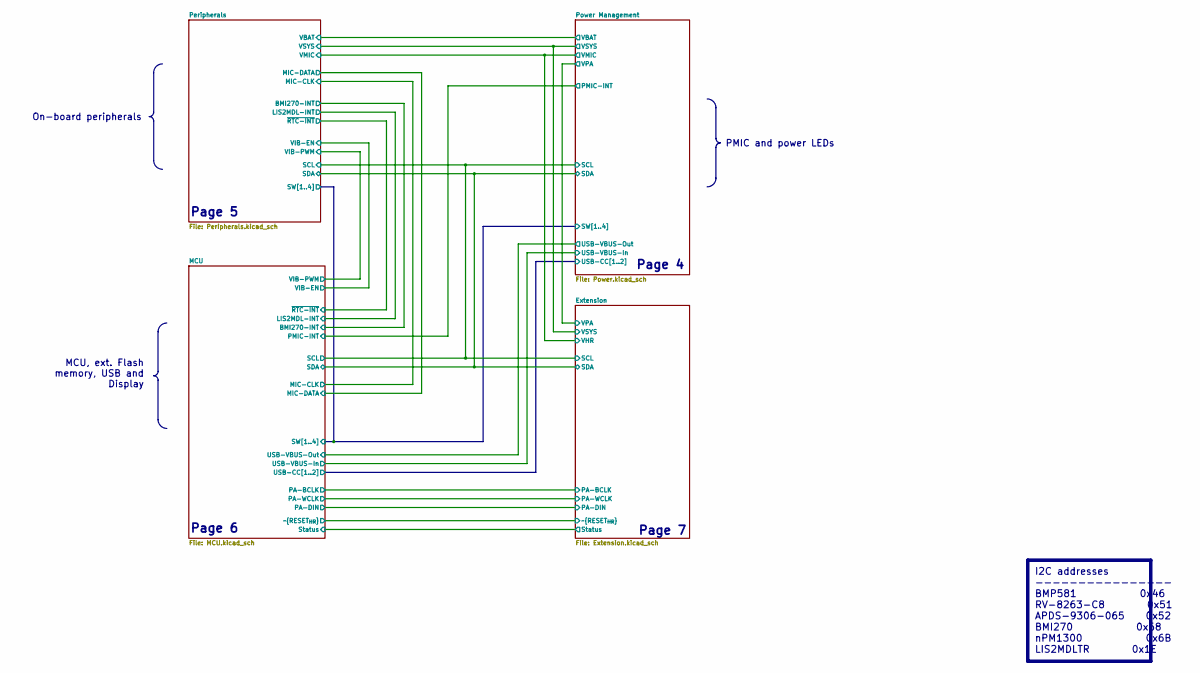
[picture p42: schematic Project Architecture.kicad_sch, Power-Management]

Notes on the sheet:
Page 6
Page 4
Page 7
Page 5
MCU, ext. Flash memory, USB and Display
I2C addresses ---------------- BMP581 0x46 RV-8263-C8 0x51 APDS-9306-065 0x52 BMI270 0x68 nPM1300 0x6B LIS2MDLTR 0x1E
On-board peripherals
PMIC and power LEDs

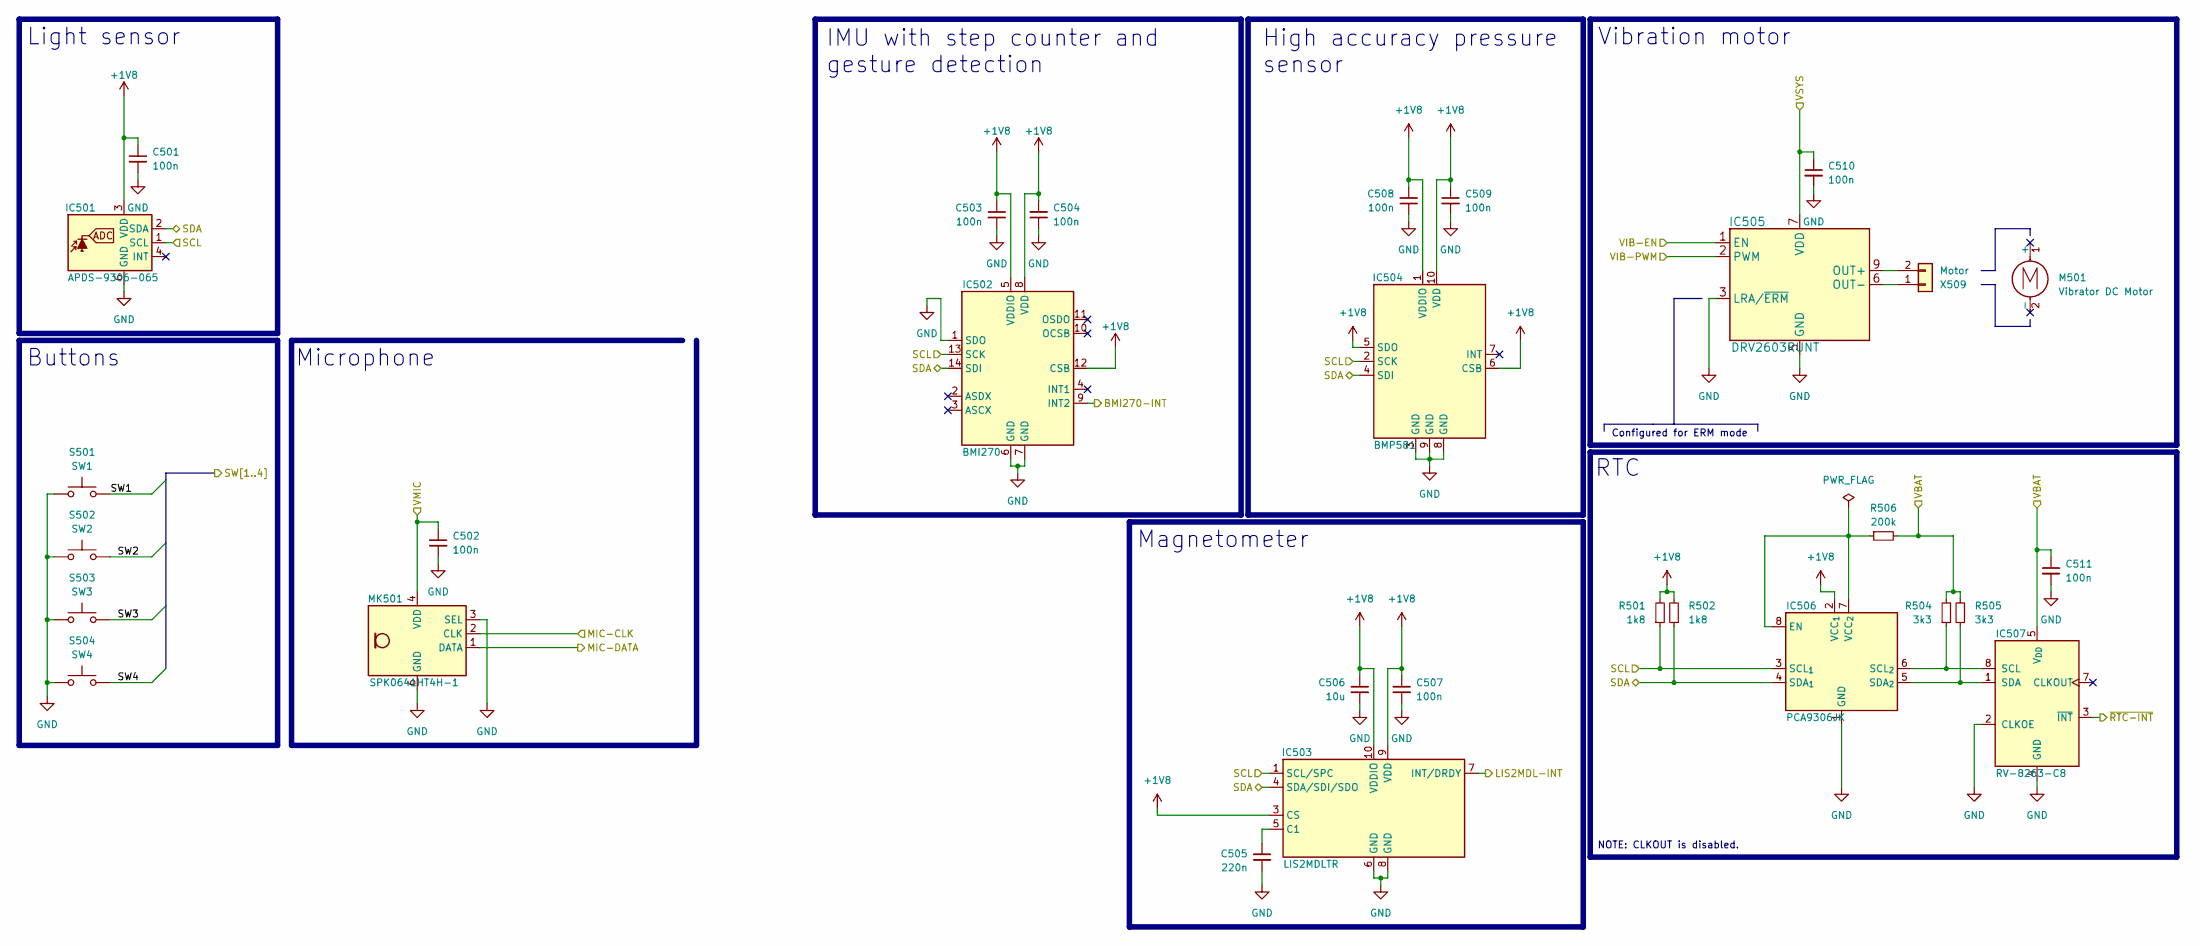
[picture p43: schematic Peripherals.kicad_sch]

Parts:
C501, C502, C503, C504, C507, C508, C509, C510, C511: 100n; C_0201_0603Metric; mouser# 581-02016D104MAT4A
C505: 220n; C_0201_0603Metric; mouser# 581-0201ZD224KAT2A
C506: 10u; C_0402_1005Metric; mouser# 81-GRJ155R60J106ME11D
IC501: APDS-9306-065; Broadcom_DFN-6_2x2mm_P0.65mm; mouser# 630-APDS-9306-065
IC502: BMI270; Bosch_LGA-14_3x2.5mm_P0.5mm_LayoutBorder3x4y; mouser# 262-BMI270
IC503: LIS2MDLTR; LGA-12_2x2mm_P0.5mm; mouser# 511-LIS2MDLTR
IC504: BMP581; Bosch_LGA-10_2x2mm_P0.5mm_ClockwisePinNumbering; mouser# 262-BMP581
IC505: DRV2603RUNT; WQFN-10_2x2mm_P0.5mm; mouser# 595-DRV2603RUNT
IC506: PCA9306JK; XSON-8_0.65x0.17mm_P0.35mm; mouser# 771-PCA9306JKZ
IC507: RV-8263-C8; mouser# 428-204291-MC01
M501: Vibrator DC Motor; digikey# 1670-VC1027B902F-ND
MK501: SPK0641HT4H-1; mouser# 721-SPK0641HT4H-1
R501, R502: 1k8; R_0201_0603Metric; mouser# 603-RC0201JR-071K8L
R504, R505: 3k3; R_0201_0603Metric; mouser# 603-RC0201JR-073K3L
R506: 200k; R_0201_0603Metric; mouser# 603-RC0201JR-07200KL
S501: SW1; 43633303381_NoMountingPads; mouser# 710-436333033816
S502: SW2; 43633303381_NoMountingPads; mouser# 710-436333033816
S503: SW3; 43633303381_NoMountingPads; mouser# 710-436333033816
S504: SW4; 43633303381_NoMountingPads; mouser# 710-436333033816
X509: Motor; 78171-0002; mouser# 538-78171-0002

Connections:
+1V8: C501.1, C503.1, C504.2, C506.1, C507.1, C508.2, C509.1, IC501.3 (VDD), IC502.5 (VDDIO), IC502.8 (VDD), IC502.12 (CSB), IC503.3 (CS), IC503.9 (VDD), IC503.10 (VDDIO), IC504.1 (VDDIO), IC504.5 (SDO), IC504.6 (CSB), IC504.10 (VDD), IC506.2 (VCC_{1}), R501.2, R502.2; also elsewhere on the board
/Project Architecture/Extension/SCL: IC501.1 (SCL), IC502.13 (SCK), IC503.1 (SCL/SPC), IC504.2 (SCK), IC506.3 (SCL_{1}), R501.1; also elsewhere on the board
/Project Architecture/Extension/SDA: IC501.2 (SDA), IC502.14 (SDI), IC503.4 (SDA/SDI/SDO), IC504.4 (SDI), IC506.4 (SDA_{1}), R502.1; also elsewhere on the board
/Project Architecture/Extension/VHR: C502.1, MK501.4 (VDD); also elsewhere on the board
/Project Architecture/MCU/BMI270-INT: IC502.9 (INT2); also elsewhere on the board
/Project Architecture/MCU/LIS2MDL-INT: IC503.7 (INT/DRDY); also elsewhere on the board
/Project Architecture/MCU/MIC-CLK: MK501.2 (CLK); also elsewhere on the board
/Project Architecture/MCU/MIC-DATA: MK501.1 (DATA); also elsewhere on the board
/Project Architecture/MCU/SW1: S501.2; also elsewhere on the board
/Project Architecture/MCU/SW2: S502.2; also elsewhere on the board
/Project Architecture/MCU/SW3: S503.2; also elsewhere on the board
/Project Architecture/MCU/SW4: S504.2; also elsewhere on the board
/Project Architecture/MCU/VIB-EN: IC505.1 (EN); also elsewhere on the board
/Project Architecture/MCU/VIB-PWM: IC505.2 (PWM); also elsewhere on the board
/Project Architecture/MCU/~RTC-INT: IC507.3 (~INT); also elsewhere on the board
/Project Architecture/Peripherals/VBAT: C511.1, IC507.5 (V_{DD}), R504.2, R505.2, R506.2; also elsewhere on the board
/Project Architecture/Power Management/VSYS: C510.1, IC505.7 (VDD); also elsewhere on the board
GND: C501.2, C502.2, C503.2, C504.1, C505.2, C506.2, C507.2, C508.1, C509.2, C510.2, C511.2, IC501.6 (GND), IC502.1 (SDO), IC502.6 (GND), IC502.7 (GND), IC503.6 (GND), IC503.8 (GND), IC504.3 (GND), IC504.8 (GND), IC504.9 (GND), IC505.3 (LRA/~ERM), IC505.5 (GND), IC505.8 (GND), IC505.10 (GND), IC506.1 (GND), IC507.2 (CLKOE), IC507.4 (GND), MK501.3 (SEL), MK501.5 (GND), MK501.6 (GND), MK501.7 (GND), MK501.8 (GND), S501.1, S502.1, S503.1, S504.1; also elsewhere on the board
unnamed: C505.1, IC503.5 (C1)
unnamed: IC505.9 (OUT+), X509.2
unnamed: IC505.6 (OUT-), X509.1
unnamed: IC506.7 (VCC_{2}), IC506.8 (EN), R506.1
unnamed: IC506.6 (SCL_{2}), IC507.8 (SCL), R504.1
unnamed: IC506.5 (SDA_{2}), IC507.1 (SDA), R505.1

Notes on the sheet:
Vibration motor
Magnetometer
Configured for ERM mode
High accuracy pressure sensor
Buttons
RTC
Microphone
Light sensor
IMU with step counter and gesture detection
NOTE: CLKOUT is disabled.

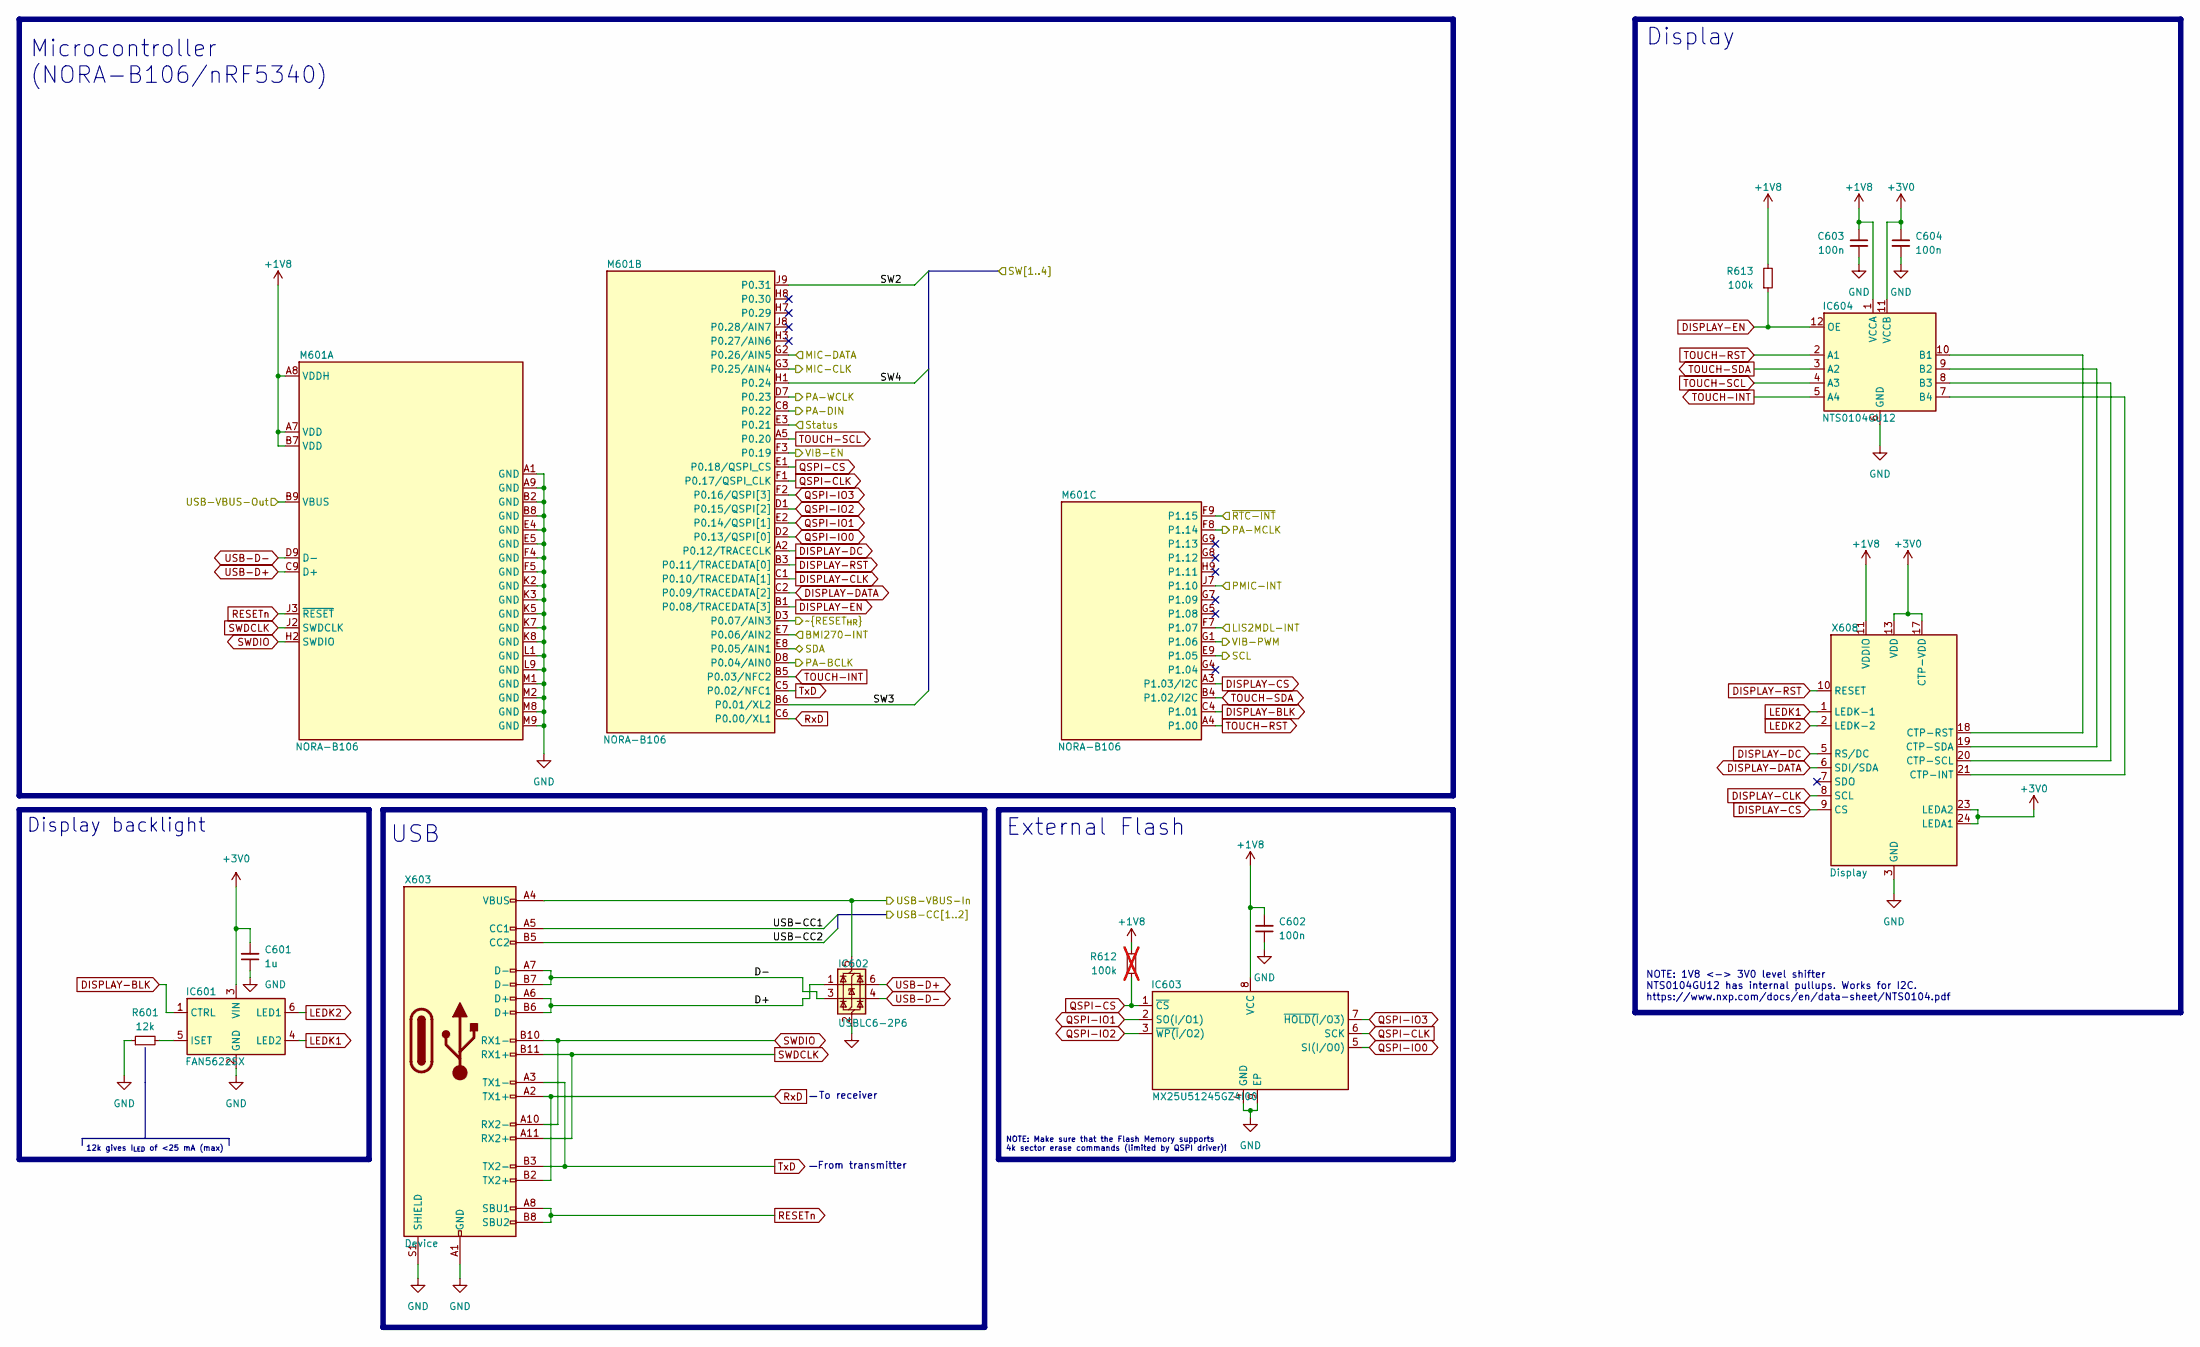
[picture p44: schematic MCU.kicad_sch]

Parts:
C601: 1u; C_0201_0603Metric; mouser# 581-KGM03BR50J105KH
C602, C603, C604: 100n; C_0201_0603Metric; mouser# 581-02016D104MAT4A
IC601: FAN5622SX; TSOT-23-6; mouser# 512-FAN5622SX
IC602: USBLC6-2P6; SOT-666; mouser# 511-USBLC6-2P6
IC603: MX25U51245GZ4I00; WSON-8-1EP_8x6mm_P1.27mm_EP3.4x4.3mm; mouser# 95-25U51245GZ4I00T
IC604: NTS0104GU12; XQFN-12-1.7x2mm_P0.4mm; mouser# 771-NTS0104GU12115
M601: NORA-B106; mouser# 377-NORA-B106-00B
R601: 12k; R_0201_0603Metric
R612: 100k; R_0201_0603Metric; not fitted
R613: 100k; R_0201_0603Metric
X603: Device; USB_C_Receptacle_Amphenol_12401610E4-2A; mouser# 523-12401610E4#2A
X608: Display; ER-CON0.4-24P

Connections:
+1V8: C602.2, C603.1, IC603.8 (VCC), IC604.1 (VCCA), M601.A7 (VDD), M601.A8 (VDDH), M601.B7 (VDD), R612.1, R613.2, X608.11 (VDDIO), X608.12 (VDDIO); also elsewhere on the board
+3V0: C601.2, C604.1, IC601.3 (VIN), IC604.11 (VCCB), X608.13 (VDD), X608.14 (VDD), X608.17 (CTP-VDD), X608.23 (LEDA2), X608.24 (LEDA1); also elsewhere on the board
/Project Architecture/Extension/PA-BCLK: M601.D8 (P0.04/AIN0); also elsewhere on the board
/Project Architecture/Extension/PA-DIN: M601.C8 (P0.22); also elsewhere on the board
/Project Architecture/Extension/PA-MCLK: M601.F8 (P1.14); also elsewhere on the board
/Project Architecture/Extension/PA-WCLK: M601.D7 (P0.23); also elsewhere on the board
/Project Architecture/Extension/SCL: M601.E9 (P1.05); also elsewhere on the board
/Project Architecture/Extension/SDA: M601.E8 (P0.05/AIN1); also elsewhere on the board
/Project Architecture/Extension/Status: M601.E3 (P0.21); also elsewhere on the board
/Project Architecture/Extension/~RESET_{HR}: M601.D3 (P0.07/AIN3); also elsewhere on the board
/Project Architecture/MCU/BMI270-INT: M601.E7 (P0.06/AIN2); also elsewhere on the board
/Project Architecture/MCU/D+: IC602.1 (I/O1), X603.A6 (D+), X603.B6 (D+)
/Project Architecture/MCU/D-: IC602.3 (I/O2), X603.A7 (D-), X603.B7 (D-)
/Project Architecture/MCU/LIS2MDL-INT: M601.F7 (P1.07); also elsewhere on the board
/Project Architecture/MCU/MIC-CLK: M601.G3 (P0.25/AIN4); also elsewhere on the board
/Project Architecture/MCU/MIC-DATA: M601.G2 (P0.26/AIN5); also elsewhere on the board
/Project Architecture/MCU/PMIC-INT: M601.J7 (P1.10); also elsewhere on the board
/Project Architecture/MCU/SW2: M601.J9 (P0.31); also elsewhere on the board
/Project Architecture/MCU/SW3: M601.B6 (P0.01/XL2); also elsewhere on the board
/Project Architecture/MCU/SW4: M601.H1 (P0.24); also elsewhere on the board
/Project Architecture/MCU/USB-CC1: X603.A5 (CC1); also elsewhere on the board
/Project Architecture/MCU/USB-CC2: X603.B5 (CC2); also elsewhere on the board
/Project Architecture/MCU/USB-VBUS-In: IC602.5 (VBUS), X603.A4 (VBUS), X603.A9 (VBUS), X603.B4 (VBUS), X603.B9 (VBUS); also elsewhere on the board
/Project Architecture/MCU/USB-VBUS-Out: M601.B9 (VBUS); also elsewhere on the board
/Project Architecture/MCU/VIB-EN: M601.F3 (P0.19); also elsewhere on the board
/Project Architecture/MCU/VIB-PWM: M601.G1 (P1.06); also elsewhere on the board
/Project Architecture/MCU/~RTC-INT: M601.F9 (P1.15); also elsewhere on the board
DISPLAY-BLK: IC601.1 (CTRL), M601.C4 (P1.01)
DISPLAY-CS: M601.A3 (P1.03/I2C), X608.9 (CS)
DISPLAY-DATA: M601.C2 (P0.09/TRACEDATA[2]), X608.6 (SDI/SDA)
DISPLAY-DC: M601.A2 (P0.12/TRACECLK), X608.5 (RS/DC)
DISPLAY-RST: M601.B3 (P0.11/TRACEDATA[0]), X608.10 (RESET)
GND: C601.1, C602.1, C603.2, C604.2, IC601.2 (GND), IC602.2 (GND), IC603.4 (GND), IC603.9 (EP), IC604.6 (GND), M601.A1 (GND), M601.A9 (GND), M601.B2 (GND), M601.B8 (GND), M601.E4 (GND), M601.E5 (GND), M601.F4 (GND), M601.F5 (GND), M601.K2 (GND), M601.K3 (GND), M601.K5 (GND), M601.K7 (GND), M601.K8 (GND), M601.L1 (GND), M601.L9 (GND), M601.M1 (GND), M601.M2 (GND), M601.M8 (GND), M601.M9 (GND), R601.1, X603.A1 (GND), X603.A12 (GND), X603.B1 (GND), X603.B12 (GND), X603.S1 (SHIELD), X608.3 (GND), X608.4 (GND), X608.15 (GND), X608.16 (GND); also elsewhere on the board
LEDK1: IC601.4 (LED2), X608.1 (LEDK-1)
LEDK2: IC601.6 (LED1), X608.2 (LEDK-2)
unnamed: IC601.5 (ISET), R601.2
unnamed: IC604.10 (B1), X608.18 (CTP-RST)
unnamed: IC604.9 (B2), X608.19 (CTP-SDA)
unnamed: IC604.8 (B3), X608.20 (CTP-SCL)
unnamed: IC604.7 (B4), X608.21 (CTP-INT)
QSPI-CLK: IC603.6 (SCK), M601.F1 (P0.17/QSPI_CLK)
QSPI-CS: IC603.1 (~CS), M601.E1 (P0.18/QSPI_CS), R612.2
QSPI-IO0: IC603.5 (SI(I/O0)), M601.D2 (P0.13/QSPI[0])
QSPI-IO1: IC603.2 (SO(I/O1)), M601.E2 (P0.14/QSPI[1])
QSPI-IO2: IC603.3 (~WP(I/O2)), M601.D1 (P0.15/QSPI[2])
QSPI-IO3: IC603.7 (~HOLD(I/O3)), M601.F2 (P0.16/QSPI[3])
RESETn: M601.J3 (~RESET), X603.A8 (SBU1), X603.B8 (SBU2)
RxD: M601.C6 (P0.00/XL1), X603.A2 (TX1+), X603.B2 (TX2+)
SWDCLK: M601.J2 (SWDCLK), X603.A11 (RX2+), X603.B11 (RX1+)
SWDIO: M601.H2 (SWDIO), X603.A10 (RX2-), X603.B10 (RX1-)
TOUCH-INT: IC604.5 (A4), M601.B5 (P0.03/NFC2)
TOUCH-RST: IC604.2 (A1), M601.A4 (P1.00)
TOUCH-SCL: IC604.4 (A3), M601.A5 (P0.20)
TOUCH-SDA: IC604.3 (A2), M601.B4 (P1.02/I2C)
TxD: M601.C5 (P0.02/NFC1), X603.A3 (TX1-), X603.B3 (TX2-)
USB-D+: IC602.6 (I/O1), M601.C9 (D+)
USB-D-: IC602.4 (I/O2), M601.D9 (D-)

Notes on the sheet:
From transmitter
To receiver
12k gives I_{LED} of <25 mA (max)
NOTE: Make sure that the Flash Memory supports 4k sector erase commands (limited by QSPI driver)!
Display backlight
Display
USB
NOTE: 1V8 <-> 3V0 level shifter NTS0104GU12 has internal pullups. Works for I2C. https://www.nxp.com/docs/en/data-sheet/NTS0104.pdf
Microcontroller (NORA-B106/nRF5340)
External Flash

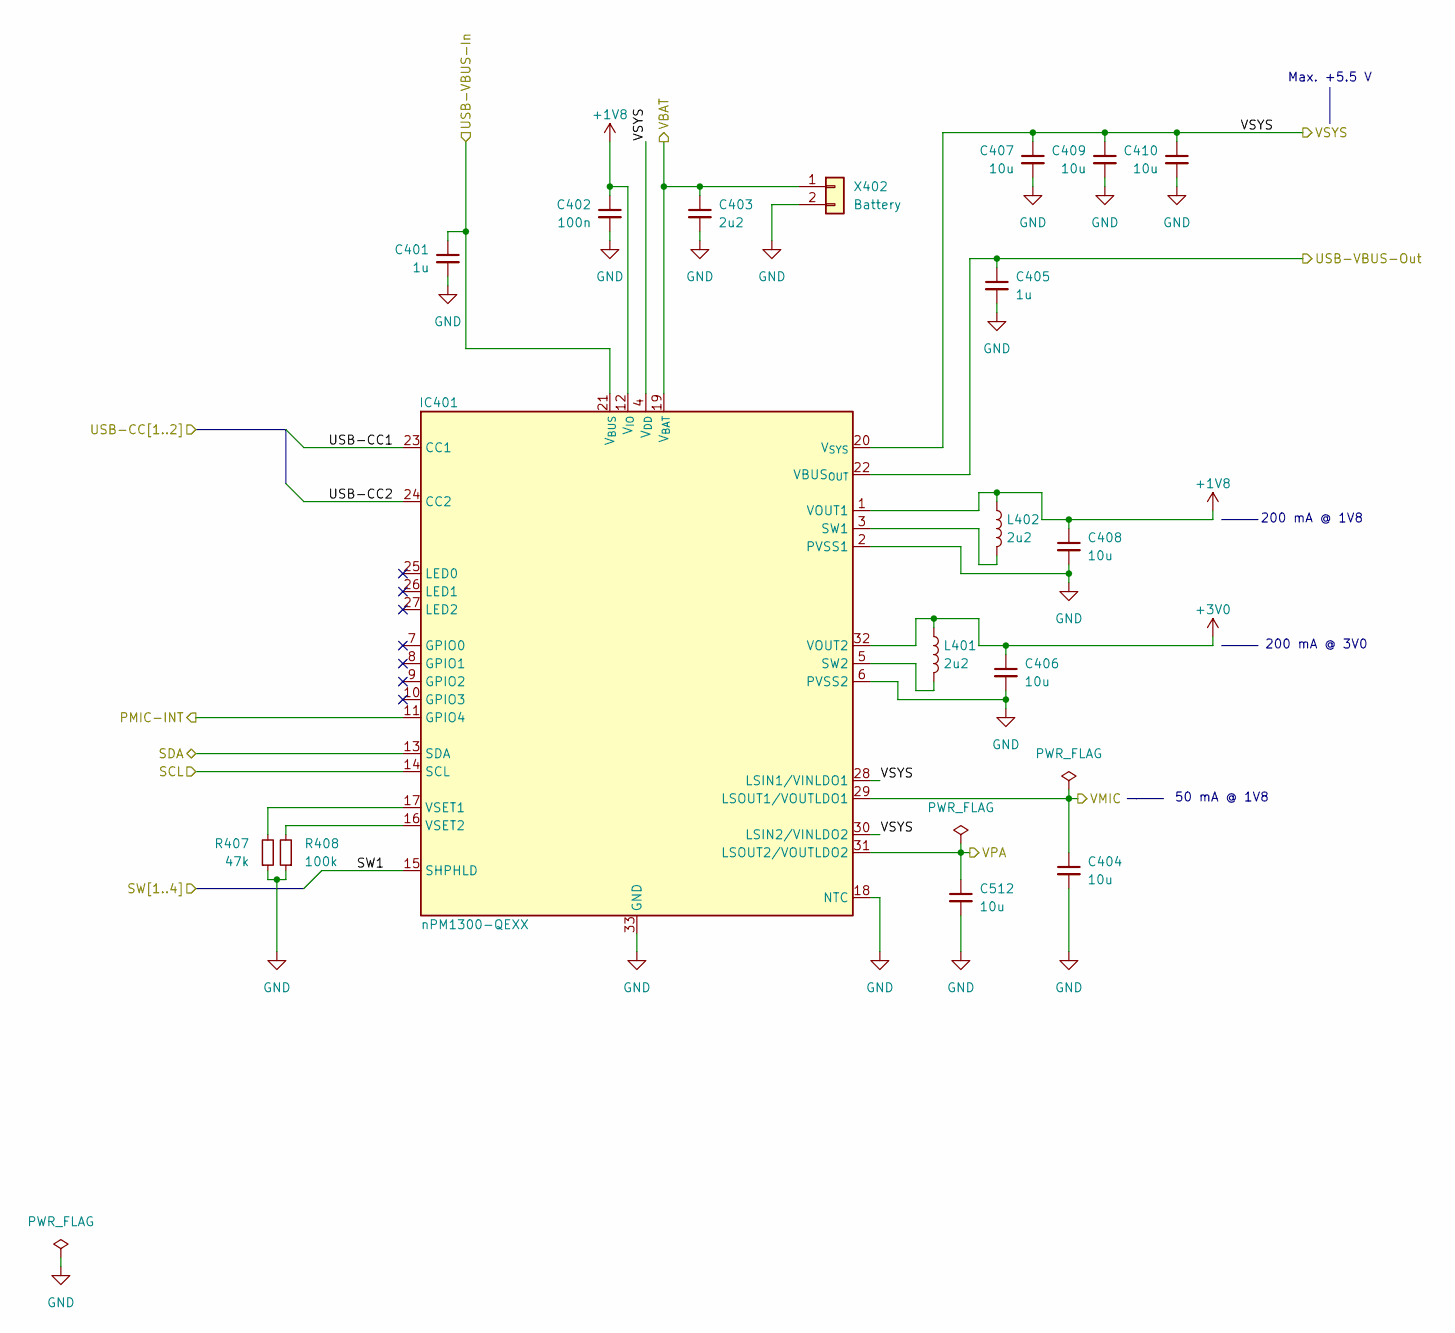
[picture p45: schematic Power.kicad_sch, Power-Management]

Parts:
C401, C405: 1u; C_0201_0603Metric; mouser# 581-KGM03BR50J105KH
C402: 100n; C_0201_0603Metric; mouser# 581-02016D104MAT4A
C403: 2u2; C_0402_1005Metric; mouser# 581-0402ZD225MAT2A
C404, C406, C408, C512: 10u; C_0402_1005Metric; mouser# 81-GRJ155R60J106ME11D
C407, C409, C410: 10u; C_0603_1608Metric; mouser# 581-KGM15CR50J106MT
IC401: nPM1300-QEXX; QFN-32-1EP_5x5mm_P0.5mm_EP3.6x3.6mm; mouser# 949-NPM1300-QEAA-R7
L401, L402: 2u2; L_0603_1608Metric; mouser# 81-LQM18PZ2R2MDHD
R407: 47k; R_0201_0603Metric; mouser# 603-RC0201JR-0747KL
R408: 100k; R_0201_0603Metric; mouser# 603-RC0201JR-07100KL
X402: Battery; JST_SH_SM02B-SRSS-TB_1x02-1MP_P1.00mm_Horizontal; mouser# 306-SM02BSRSSTBLFSN

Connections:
+1V8: C402.1, C408.1, IC401.1 (VOUT1), IC401.12 (V_{IO}), L402.1; also elsewhere on the board
+3V0: C406.1, IC401.32 (VOUT2), L401.1; also elsewhere on the board
/Project Architecture/Extension/SCL: IC401.14 (SCL); also elsewhere on the board
/Project Architecture/Extension/SDA: IC401.13 (SDA); also elsewhere on the board
/Project Architecture/Extension/VHR: C404.1, IC401.29 (LSOUT1/VOUTLDO1); also elsewhere on the board
/Project Architecture/Extension/VPA: C512.1, IC401.31 (LSOUT2/VOUTLDO2); also elsewhere on the board
/Project Architecture/MCU/PMIC-INT: IC401.11 (GPIO4); also elsewhere on the board
/Project Architecture/MCU/SW1: IC401.15 (SHPHLD); also elsewhere on the board
/Project Architecture/MCU/USB-CC1: IC401.23 (CC1); also elsewhere on the board
/Project Architecture/MCU/USB-CC2: IC401.24 (CC2); also elsewhere on the board
/Project Architecture/MCU/USB-VBUS-In: C401.1, IC401.21 (V_{BUS}); also elsewhere on the board
/Project Architecture/MCU/USB-VBUS-Out: C405.1, IC401.22 (VBUS_{OUT}); also elsewhere on the board
/Project Architecture/Peripherals/VBAT: C403.1, IC401.19 (V_{BAT}), X402.1; also elsewhere on the board
/Project Architecture/Power Management/VSYS: C407.1, C409.1, C410.1, IC401.4 (V_{DD}), IC401.20 (V_{SYS}), IC401.28 (LSIN1/VINLDO1), IC401.30 (LSIN2/VINLDO2); also elsewhere on the board
GND: C401.2, C402.2, C403.2, C404.2, C405.2, C406.2, C407.2, C408.2, C409.2, C410.2, C512.2, IC401.2 (PVSS1), IC401.6 (PVSS2), IC401.18 (NTC), IC401.33 (GND), R407.1, R408.1, X402.2; also elsewhere on the board
unnamed: IC401.3 (SW1), L402.2
unnamed: IC401.5 (SW2), L401.2
unnamed: IC401.17 (VSET1), R407.2
unnamed: IC401.16 (VSET2), R408.2

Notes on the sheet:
50 mA @ 1V8
200 mA @ 1V8
Max. +5.5 V
200 mA @ 3V0

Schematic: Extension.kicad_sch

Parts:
LS801: Speaker; CMR-12062S-67; mouser# 490-CMR-12062S-67
M801: Extension

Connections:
unnamed: M801.S113 (GND), M801.S212 (GND)
unnamed 56: LS801.2, M801.S11 (SP_{N}); also elsewhere on the board
unnamed 57: LS801.1, M801.S13 (SP_{P}); also elsewhere on the board

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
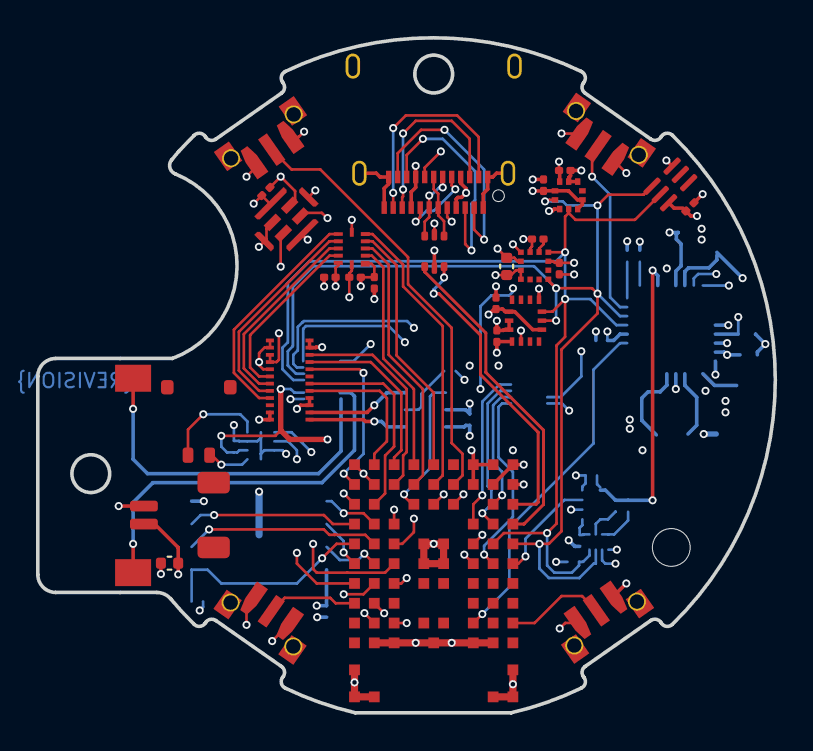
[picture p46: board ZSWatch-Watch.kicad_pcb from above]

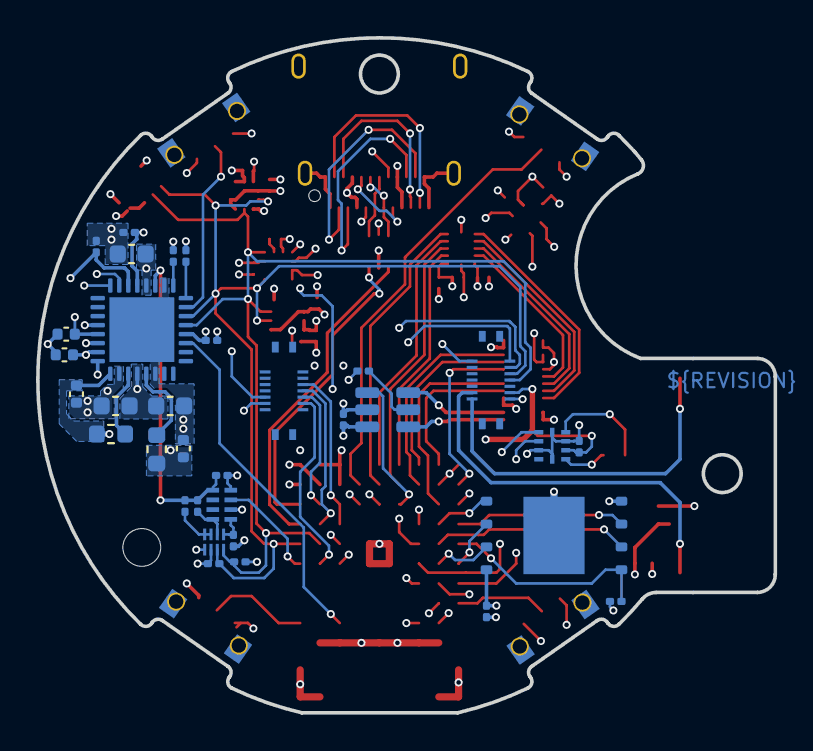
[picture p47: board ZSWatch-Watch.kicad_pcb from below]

Board: 4 copper layers, 41.0 x 37.5 mm, 63 parts (33 on the bottom side), 76 nets.

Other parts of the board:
X701: MB1; 101R014FB110
X702: MB2; 101R014FB110

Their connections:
/Project Architecture/Extension/PA-BCLK: X701.7; also elsewhere on the board
/Project Architecture/Extension/PA-DIN: X701.9; also elsewhere on the board
/Project Architecture/Extension/PA-MCLK: X701.11; also elsewhere on the board
/Project Architecture/Extension/PA-WCLK: X701.5; also elsewhere on the board
/Project Architecture/Extension/SCL: X702.10; also elsewhere on the board
/Project Architecture/Extension/SDA: X702.8; also elsewhere on the board
/Project Architecture/Extension/Status: X702.12; also elsewhere on the board
/Project Architecture/Extension/VHR: X702.2; also elsewhere on the board
/Project Architecture/Extension/VPA: X701.10; also elsewhere on the board
/Project Architecture/Extension/~RESET_{HR}: X702.14; also elsewhere on the board
/Project Architecture/Power Management/VSYS: X702.4; also elsewhere on the board
GND: X701.12, X702.13; also elsewhere on the board
unnamed 56: X702.1; also elsewhere on the board
unnamed 57: X702.3; also elsewhere on the board

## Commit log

2026-02-21 First prototype release ready
    [Block Diagram.kicad_sch, Extension.kicad_sch, MCU.kicad_sch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]
2026-02-21 Add speaker
    [Extension.kicad_sch, MCU.kicad_sch, Peripherals.kicad_sch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]
2026-02-21 New PCB outline, fix logo copy job for KiBot
    [ZSWatch-Watch.kicad_pcb]
2026-02-21 Move display connector 3 mm to the outside and optimize routing
    [MCU.kicad_sch, ZSWatch-Watch.kicad_pcb]
2026-02-21 Fix wrong Extension footprint
    [Extension.kicad_sch, MCU.kicad_sch, Project Architecture.kicad_sch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]
2026-02-21 New buttons
    [Peripherals.kicad_sch, ZSWatch-Watch.kicad_pcb]
2026-02-21 New battery connector
    - Add CI/CD workflow to check for changelog updates on pull requests
    [Extension.kicad_sch, MCU.kicad_sch, Power.kicad_sch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]
2026-02-21 Replace wrong extension connectors
    [Extension.kicad_sch, MCU.kicad_sch, ZSWatch-Watch.kicad_pcb]
2026-02-21 OPtimize connector positions
    - New position for the battery connector, moved to the right side of the watch
    - Rotate haptics connector by 180°
    [MCU.kicad_sch, Peripherals.kicad_sch, Power.kicad_sch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]
2026-02-21 Rename PCB workflow, add part number for battery connector, remove sim pins property
    [MCU.kicad_sch, Peripherals.kicad_sch, Power.kicad_sch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]
2026-02-21 Prepare release 1.0.0
    [ZSWatch-Watch.kicad_pcb]
2026-02-21 Push outputs from CI/CD (2026-02-20 15:45:10)
    [ZSWatch-Watch-(L1-L4)_NPTH_drill_table.csv, ZSWatch-Watch-(L1-L4)_drill_table.csv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]
2026-02-21 Push outputs from CI/CD (2026-02-20 19:25:28)
    [ZSWatch-Watch-(L1-L4)_NPTH_drill_table.csv, ZSWatch-Watch-(L1-L4)_drill_table.csv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]
2026-02-21 Update outputs (release)
    [ZSWatch-Watch-(L1-L4)_NPTH_drill_table.csv, ZSWatch-Watch-(L1-L4)_drill_table.csv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]
2026-04-17 Update README with prototype warnings and links
    Added important notes regarding the prototype status and ordering recommendations.
2026-10-13 Add .coderabbit.yaml to filter out files for review.
2026-10-14 Change to a larger battery connector (JST 1.25). Add pads for speaker instead.
2026-10-14 Fix BOM fields, optional speaker flags and connector 3D model
    - Rename J1 fields to match the BOM generator
    - Exclude optional LS801 from the board and BOM
    - Correct the Molex footprint's 3D model reference
2026-10-14 Make battery/speaker stickout 0.5mm shorter. Add few extra Test Points for power at bottom.
2026-10-14 Fix some ERC Errors due to NC mount points.
2026-10-15 Add test pads for FEM pins if NORA-126 is used instead.
    NORA-W126 is a drop in compatible module with FEM to increase output power.
    Litterary just to mount this instead of NORA-B106.
2026-10-15 Add 1.1.0 release notes to Revision History
    - Fill the Unreleased changelog section for the 1.1.0 release
    - Show the 1.1.0 changelog on the Revision History sheet
    - Generate 1.0.0 and 1.1.0 changelog variables in the KiBot preflight so
    the sheet no longer prints raw ${RELEASE_*} placeholders
2026-10-15 Add orientation arrow for HR add-on silkscreen
2026-10-21 Restore pinned KiCad library and release validation
2026-10-29 Update to the latest KiCad template and KiCad 10
    - Port schematics, layout and the local libraries to the KiCad 10 file format
    (ERC/DRC unchanged), rename the text variable VARIANT to PCB_VARIANT and use
    KICAD10_3DMODEL_DIR for the 3D models
    - Replace watch.yaml and changelog-check.yaml with the template workflows
    hw-pcb.yaml and common-changelog.yaml (KiCad 10 image, BoM check, Mouser cart,
    release and GitHub Pages deployment). The pinned kicad-library submodule is kept
    - Remove the committed production outputs and CI logs, they are attached to the
    release and published on GitHub Pages instead
    - Update the KiBot configuration, resources and title block templates from the
    templat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
2026-10-29 Update schematic and layout with KiCad 10
    Changes to the MCU and Power sheets and the layout, saved with KiCad 10
    (adds the new KiCad 10 project settings).
2026-10-29 Restore the sheet instances of Project Architecture
    The KiCad 10 upgrade of the sheet without the project context dropped the
    instances of the project, so Power Management, Peripherals, MCU and Extension
    had no page numbers. Restore them (pages 4 to 7) from the state before the
    upgrade.
2026-10-29 Fix DRC errors and remove the Power - Topology sheet
    Fixes the annular width of the mounting holes of S501 to S504 and the
    courtyard overlaps of J1 with C403 and X509. The removed sheet also fixes the
    duplicate page number 2.
